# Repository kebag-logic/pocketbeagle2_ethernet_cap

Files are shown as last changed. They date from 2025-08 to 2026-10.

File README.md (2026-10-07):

# PocketBeagle 2 Ethernet Cap

Ethernet cap for the PocketBeagle 2, exposing the TSN features of the AM62x through a
DP83867IRPAPR gigabit PHY (RGMII), with full IO pass-through headers for stacking additional modules.

## Getting started

```sh
git clone <this repo>
git submodule update --init     # pulls kebag_logic_kicad_library
```

Open `pocketbeagle2_ethernet_cap.kicad_pro` with KiCad ≥ 9. All symbols/footprints
resolve project-locally through `sym-lib-table` / `fp-lib-table` into the
[kebag_logic_kicad_library](https://github.com/kebag-logic/kebag_logic_kicad_library)
submodule — no global library setup needed.

## Schematic structure

```
pocketbeagle2_ethernet_cap.kicad_sch   root: pure block diagram (sheet symbols only)
├── io.kicad_sch                       U1 PocketBeagle 2 + J2/J3 IO pass-through headers
├── network.kicad_sch                  network domain top
│   ├── phy.kicad_sch                  U2 DP83867 PHY, straps, decoupling, status LEDs
│   ├── rj45_connector_port0.kicad_sch J1 RJ45 magjack (integrated magnetics)
│   └── oscillator.kicad_sch           Y1 25 MHz HCMOS oscillator + clock conditioning
├── ldo_2v5.kicad_sch                  U4 TPS7A2025 -> VDD_2V5
└── ldo_1v1.kicad_sch                  U3 TPS7A2011 -> VDD_1V1
```

The design is fully hierarchical (shish-lan house style): **no global labels**. `GND`
is distributed via `power:GND` symbols; every other inter-sheet net crosses through
**hierarchical sheet-pin ports**, so signal flow is traceable through the hierarchy.
The root is a block diagram: `io` sources the RGMII/MDIO/reset/interrupt signals and
`VDD_3V3`, `network` consumes them, and the `ldo_*` sheets feed `VDD_2V5`/`VDD_1V1`.
Inside `io`, the PocketBeagle IOs fan out to the stacking headers as sheet-local nets;
only the 17 cap-used signals leave the sheet as ports.

## Documentation

- [documentation/connections.md](documentation/connections.md) — RGMII, MDI, MDIO,
  clocking, straps, audio, power tree, and the rev A → current net rename map
- [documentation/naming_convention.md](documentation/naming_convention.md) — mandatory
  signal naming rules
- [documentation/review_checklist.md](documentation/review_checklist.md) — everything
  awaiting user review after the restructure
- [documentation/library_additions.md](documentation/library_additions.md) — every
  part added to the KL library for this design (review checkpoint)
- [documentation/U2-DP83867IRPAPR_pin_out.md](documentation/U2-DP83867IRPAPR_pin_out.md)
- [documentation/current_consumption.md](documentation/current_consumption.md)

## Board state

**Rev B** (branch `revb-respin`) is manufactured and assembled by JLCPCB. All SMD parts are on the
top side; the RJ45 magjack J1 (TE 5-2301994-7, pin 1 left unsoldered) is hand-soldered on the bottom
and runs through the DP83867 RJ45 mirror mode. RGMII lengths are matched including the PocketBeagle 2
module side. Design and order details: [documentation/handover_revb_respin.md](documentation/handover_revb_respin.md).

Bring-up status (2026-10-07):

| Step | Result |
|---|---|
| Visual inspection, rail-to-GND shorts | OK |
| Bench 3.3 V on P1.14, cape alone: VDD_2V5 / VDD_1V1 | OK |
| PocketBeagle 2 on USB-C, no SD card: rails | OK |
| Ethernet link LED on cable plug/unplug (PHY out of reset, auto-negotiation) | OK |
| Link speed on the switch side: 1000 Mb/s (all 4 pairs and mirror mode work) | OK |
| Linux: PHY detected over MDIO, 1000/Full, iperf3, RGMII delay tuning | to do (needs SD card) |

### Software

A Linux image for the PocketBeagle 2 with this cape is built from the
[ti-sitara-am65x-bsp](https://github.com/kebag-logic/ti-sitara-am65x-bsp). The device tree needs the PHY at `reg = <0>` and
`phy-mode = "rgmii-rxid"` (start with a 1.75 ns RX delay); see section 2.4 of the handover.

### Rev B pictures

Assembled board on the PocketBeagle 2:

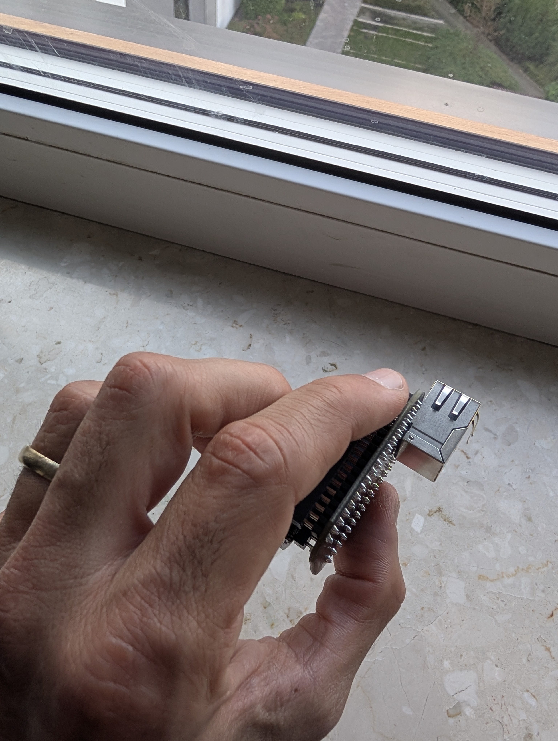
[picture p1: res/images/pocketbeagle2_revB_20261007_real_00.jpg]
Rev B assembled, side

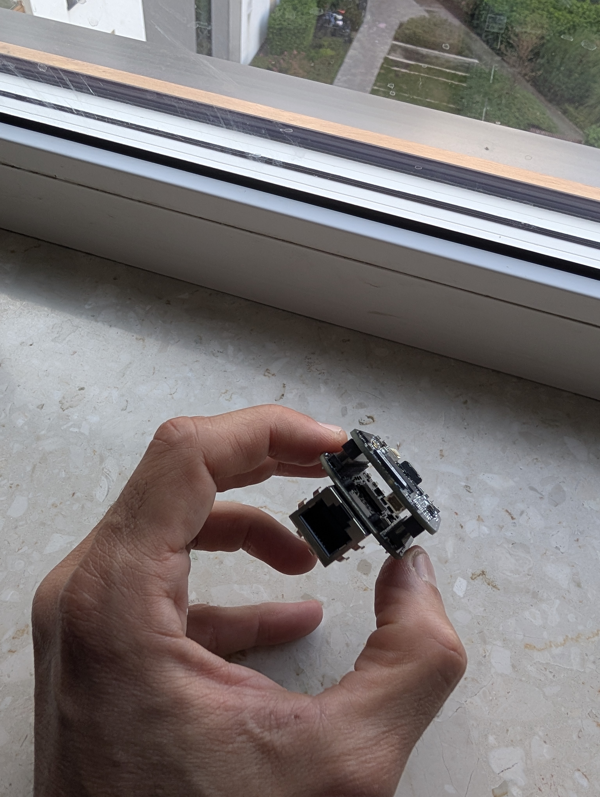
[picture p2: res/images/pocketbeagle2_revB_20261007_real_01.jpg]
Rev B assembled, RJ45 side

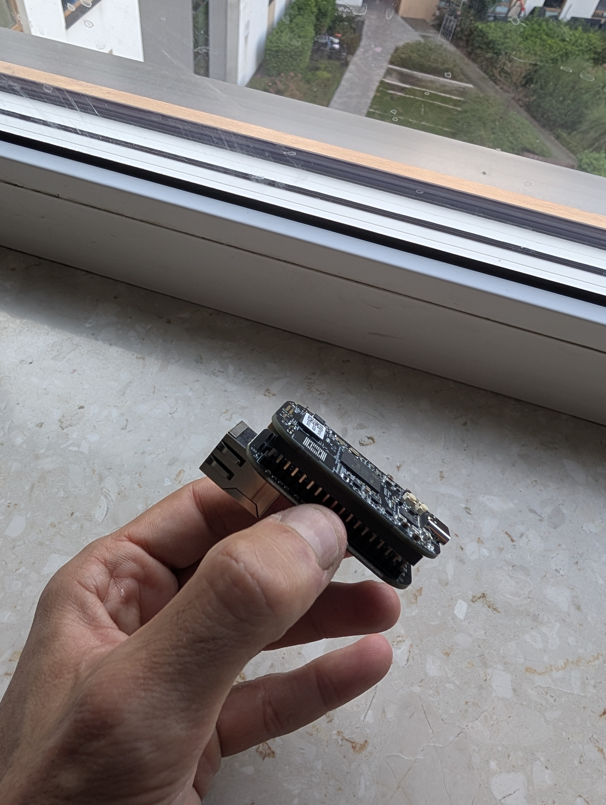
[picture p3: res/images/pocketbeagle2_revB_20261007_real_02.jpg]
Rev B assembled, PocketBeagle 2 on top


Layout and 3D views:

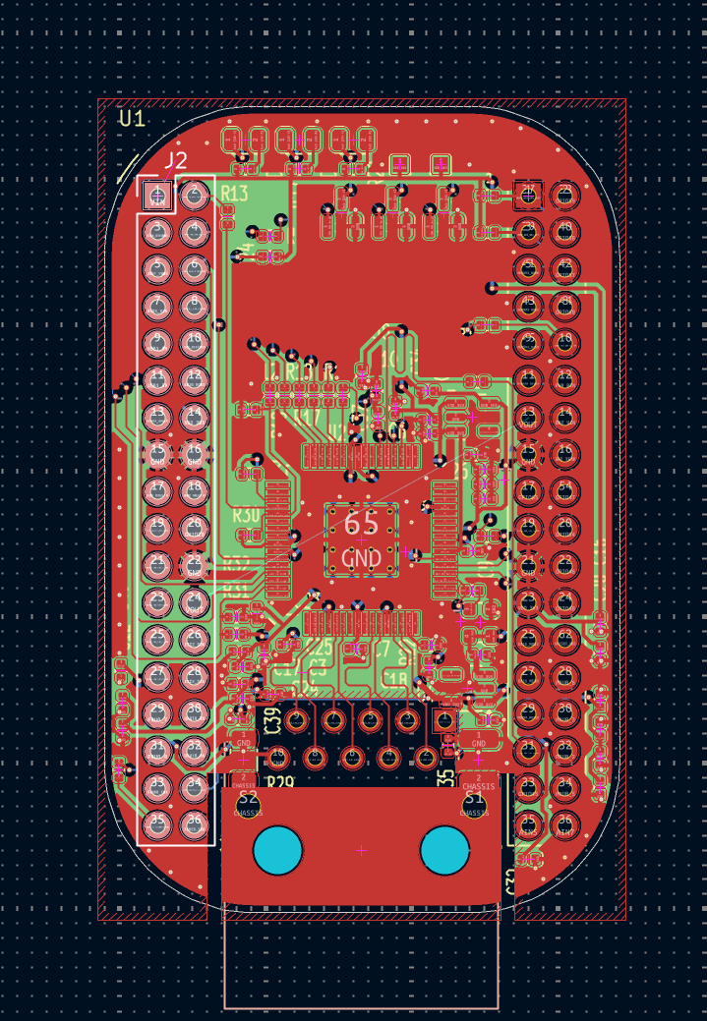
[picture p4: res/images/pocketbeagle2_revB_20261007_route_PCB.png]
Rev B routing

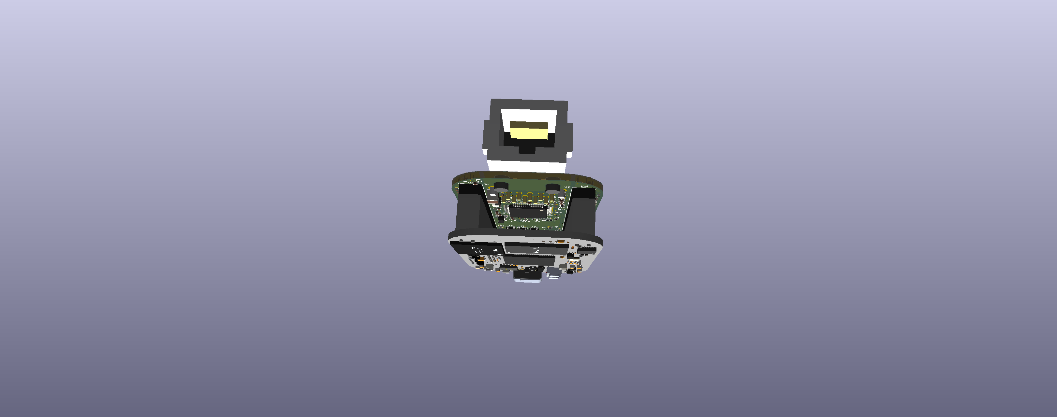
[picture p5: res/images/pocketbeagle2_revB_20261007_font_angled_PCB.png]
Rev B 3D front

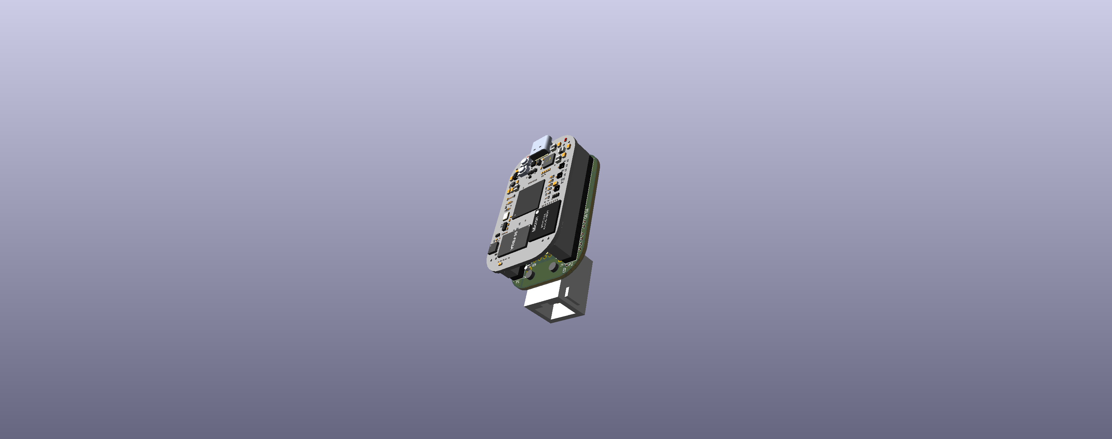
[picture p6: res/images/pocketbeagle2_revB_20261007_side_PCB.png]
Rev B 3D side

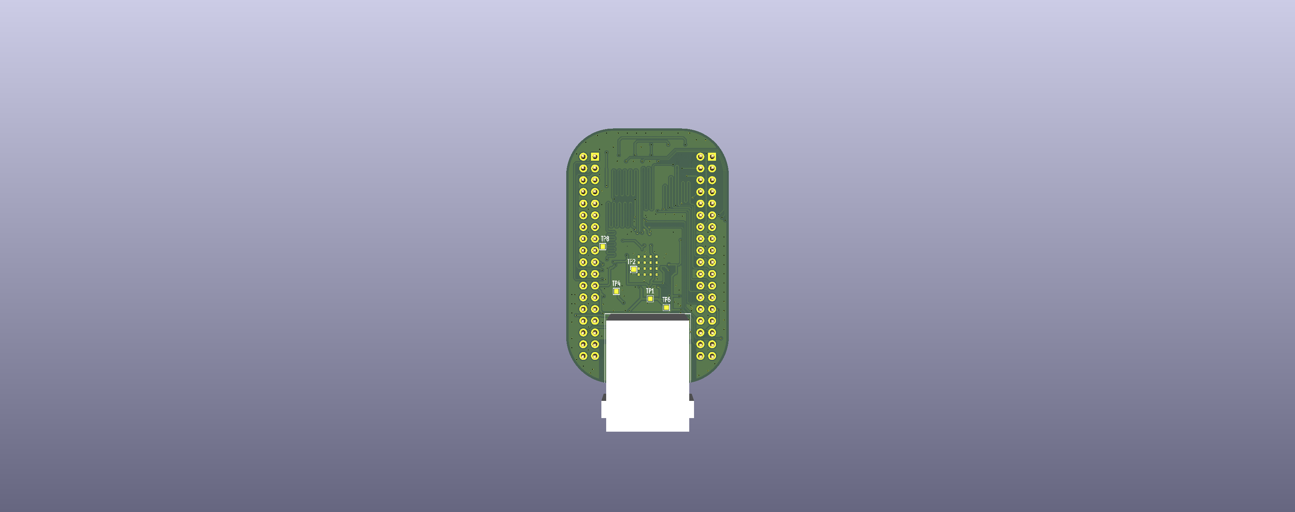
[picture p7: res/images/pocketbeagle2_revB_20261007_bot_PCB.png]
Rev B 3D bottom


### Rev A

The **rev A** routed board is preserved at git tag `revA-routed` (flight-time matching on the RGMII was
still open there).

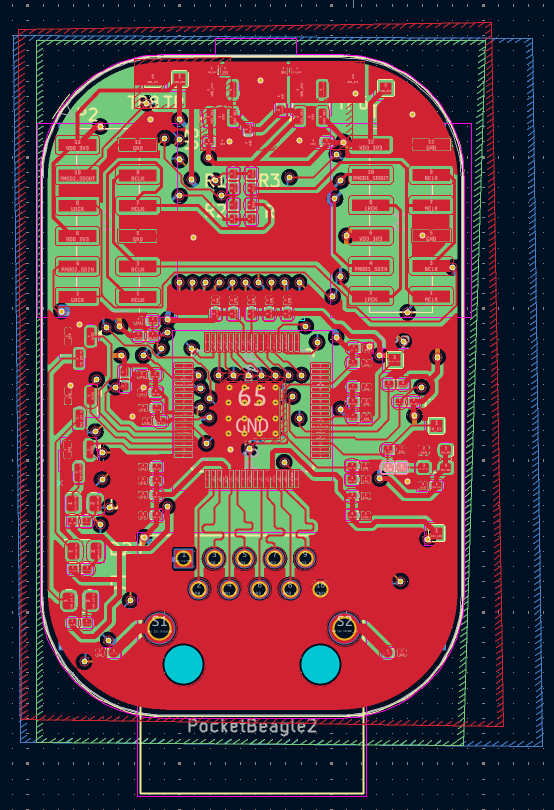
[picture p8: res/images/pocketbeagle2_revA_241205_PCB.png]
PCB layout

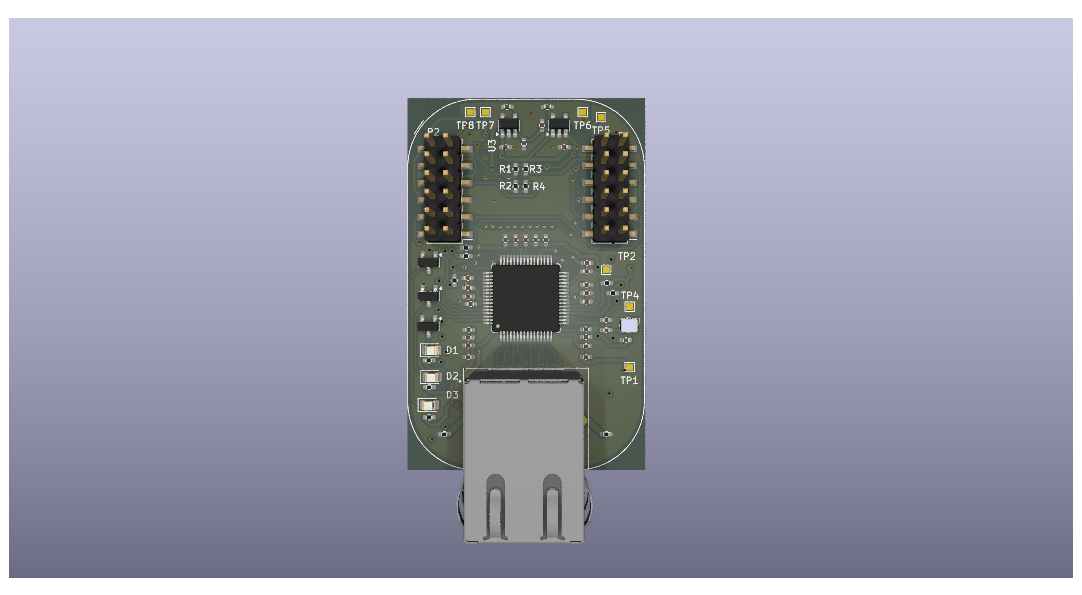
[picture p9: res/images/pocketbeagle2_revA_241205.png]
3D front

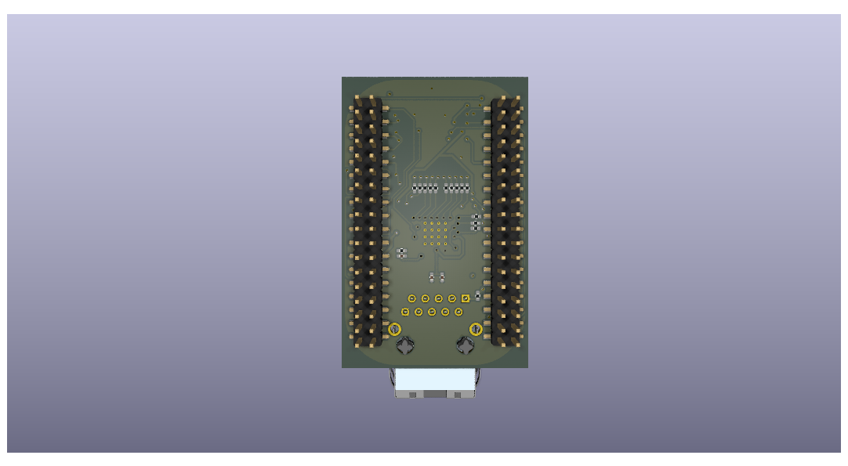
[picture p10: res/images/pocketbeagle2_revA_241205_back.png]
3D back


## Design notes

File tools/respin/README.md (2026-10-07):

# Rev B re-spin helper scripts

These are read-only planning tools plus one kipy script, which clears copper. See `documentation/handover_revb_respin.md`.

Requirements: Python 3 with `shapely` and `kipy==0.8.0`. KiCad 10 must be running with IPC enabled for the kipy scripts.

| Script | What it does |
|---|---|
| `sexp.py` | Minimal s-expression parser. |
| `model.py` | Loads pads and tracks from the saved `.kicad_pcb`. `Plan.seg/via/check` does clearance and edge checks for planned copper with shapely. |
| `plan_mdi.py [bumps…]` | MDI pair routes with the P/N skew bumps. Run with `1.2745 1.2745 1.2745 1.3455` to get 0 issues. |
| `plan_led.py` | LED0–2 gate routes: F stubs, vias, then B.Cu lanes around the top-left arc, necked to 0.10 mm. |
| `plan_rgmii.py` | **Reference only.** The old shortest-path RGMII plan, superseded by the length-matched re-spin. |
| `rgmii_len.py` | Measures the cape-side RGMII lengths per line (PHY pin → R → PB2 pad) and prints the PB2 module lengths. |
| `schio.py <sheet.kicad_sch>` | Read-only schematic geometry helper: pin positions and wire clusters. |
| `ses_parse.py` | Reads Freerouting `.ses` wiring into segment and via lists. |
| `clear_copper.py` | **Destructive.** Removes every track, via and zone from the live board in one KiCad undo step. |

`reference/board_before_respin.kicad_pcb` is the board just before the copper was cleared on 2026-09-25. It has the MDI, power, slow-net and LED routing.

## `topside/`: all SMD parts moved to F.Cu (2026-09-25)

These are archived as run. They also import the working-copy planners (`rg.py`, `d_*.py`, `meander.py`, `audit_angles.py`), which are not archived, so treat them as a record, not a ready-to-run tool.

| Script | What it does |
|---|---|
| `fpgeo.py` | Library footprint pads and courtyards for what-if placements. |
| `prune.py` | Finds the copper that dangles once a set of footprints leaves; used to clear their old bottom-side routing. |
| `ts.py` | The stage placement table (x, y, rot, side) plus courtyard and pad-clearance checks. |
| `r_top.py` | Stage 1. LED drivers Q1–Q3, D-K lanes, rebuilt LED gate lanes, MDIO/INT pull-ups, and the TD0/TD2 series resistors with their re-matched accordions. |
| `r_bot.py` | Stage 2. TD3 (R11) re-matched, TX_CLK (R14), R7 strap, CLK_OUT/1V1 test points moved to B.Cu. |
| `router.py` | 2-layer grid router. It uses 8 directions with turns of 45° or less, places vias, and stays clear of other-net copper and keepouts. |
| `capfit.py` | Greedy placement of U4 and the 30 caps nearest their pins. Each part is routed rail to copper and GND to a plane via. Results go to `cap_place.json` and `cap_routes.json`. |
| `conn.py` | Per-net island check: pads, tracks and vias, with GND vias joining the planes. |
| `apply_stage.py` | Checks live pads against the model, removes the pruned copper (exact endpoints), then pushes the plan. |
| `silk_place.py` | Places reference designators and P1/P2 labels at 1.0/0.15 mm with no overlaps. |

`../make_build.py` writes `build/`: fabrication (Gerbers, drill, zip, IPC-D-356), assembly (JLC BOM/CPL, full BOM, drawing) and docs (schematic PDF, STEP, DRC report).

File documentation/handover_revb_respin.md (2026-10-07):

# Handover — Rev B schematic review and PCB re-spin

Date: 2026-09-25. Project: PocketBeagle 2 Ethernet cape (DP83867, KiCad 10.0.6).

**State (end of 2026-09-25):** the re-spin is **routed, DRC-clean on copper and committed** on branch
`revb-respin`, with **every SMD part on the top side**. JLCPCB Gerbers, BOM and CPL are in `build/`.
Sections 2.1–2.2 are the schematic/library history; 2.3 onward is the current board.

---

## 1. What was asked

- Review the schematics, then re-spin the PCB.
- Match the RGMII lanes as they must be, **including the PocketBeagle 2 (PB2) module-side
  lengths**, with the right impedance. EMC must be good.
- Add F.Silkscreen labels for the P1/P2 headers.
- Add missing 3D models to the `kebag_logic_kicad_library` submodule and commit them.
  Commit as `hackerman-kl <alexandremalki89@gmail.com>`, at most 10 words, no co-author.
- Pour the signal-layer (F/B) GND planes **last**, after everything else is routed.
- Avoid 90° corners. Follow every IC's layout guidelines.

PB2 module-side RGMII2 lengths given by the user (mils → mm):

| Signal  | Ball | mils | mm |
|---|---|---|---|
| RD0 | AE23 | 1808.5  | 45.94 |
| RD1 | AB20 | 1520.17 | 38.61 |
| RD2 | AC21 | 1511.44 | 38.39 |
| RD3 | AE22 | 1459.68 | 37.08 |
| RX_CLK  | AD23 | 2204.81 | 56.00 |
| RX_CTRL | AD22 | 1350.87 | 34.31 |
| TD0 | Y18  | 1182.32 | 30.03 |
| TD1 | AA18 | 1991.72 | 50.59 |
| TD2 | AD21 | 785.48  | 19.95 |
| TD3 | AC20 | 328.86  | 8.35  |
| TX_CLK  | AE21 | 2442.23 | 62.03 |
| TX_CTRL | AA19 | 2925.95 | 74.32 |

TD2 and TD3 each have "2 possibilities" (two SoC balls). The table uses the listed ball.

---

## 2. Done

### 2.1 Schematic fixes (ERC: 0 errors; committed)

| Fix | Where | Why |
|-----|---|-----|
| J2.2/4/19/21/23/25/27/34/35 and J3.10/19 were tied to GND. They now carry their U1 RGMII net. | `io.kicad_sch` | J2/J3 are co-located on the U1 holes, so they are the same plated hole. As drawn, the GND tie shorted RGMII to GND. It came from commit `c8bef36`. |
| AIN_VREF_N label moved from U1.51 to U1.17. U1.51 is GND again. | `io.kicad_sch` | The label was on the wrong pin. |
| Removed a dangling 2.54 mm wire under `#PWR0100`. | `io.kicad_sch` | ERC warning. |
| **R30 5k76 added**, STRAP_RX_CTRL_PHY to VDD_3V3. With R7 2k49 this gives **mode 3**. | `phy.kicad_sch` | RX_CTRL in mode 1 is forbidden (SNLS484J Table 7-6 note 1): the PHY can enter a test mode. |
| RX_D7 strap changed to **mode 4**: R5 5k76 → 2k49, R6 removed. | `phy.kicad_sch` | Speed-opt stays on and CLK_OUT is disabled, so the unused 25 MHz to TP2 no longer radiates. Table 7-5/7-6. |
| C28 (22p on RBIAS) removed. | `phy.kicad_sch` | Not in the datasheet or TI reference designs. Konnect can't set DNP, so the part was deleted. |
| C18 27p → **22p**. | `oscillator.kicad_sch` | XI amplitude goes from 1.51 Vpp (marginal) to about 1.65 Vpp, against the 1.5–1.9 Vpp spec. |
| **R25 removed**, J1.1 (centre-tap common) marked no-connect, and the `VDD_2V5` sheet pin on the magjack sheet deleted. | `rj45_connector_port0.kicad_sch`, `network.kicad_sch` | Fitting R25 would put 2.5 V DC on the magjack centre taps. Fig 9-2: CTs go to GND through caps only. |
| **Chassis isolation.** J1.S1/S2 go to a `CHASSIS` net, then R29 **1M 1206** ∥ C36 **4n7 2 kV 1210** to GND. This replaces the two 0R links. | `rj45_connector_port0.kicad_sch` | TI §9.2.2 chassis isolation, for ESD and EMC. |

Review findings that are **not** schematic changes. They go to firmware and device tree (DT):

- **Shared pins:** PB2 RGMII/MDIO header pins are shared with other SoC balls (E18, D20, A13, B20, B18) and with MSPM0 PA16/PA21–26. The PB2 pinmux must keep the second balls as inputs with no pull, and the MSPM0 must keep those pins Hi-Z/analog. Check the RX eye at 1000 Mb/s.
- **PHY address:** it depends on RX_D0/RX_D2 floating at strap latch time. Put `reg = <0>` in the DT.
- **RGMII delays:** AM62x normally uses `phy-mode = "rgmii-rxid"`, and the DT needs `ti,rx-internal-delay`. Set the final values after routing, from the measured lengths (section 4.4).
- **Voltage:** RGMII2 on the PB2 is 3.3 V (VDDSHV2), so VDDIO = 3.3 V is correct. The "1.8V" pin labels were wrong; see 2.2.

### 2.2 Library submodule (`kebag_logic_kicad_library`, branch `pocketbeagle-2`)

There are 3 local commits. They are **not pushed**, and the main repo's submodule pointer has not been bumped.

- `3800219` Add 3D models for PHY, oscillator and PocketBeagle 2:
  - HTQFP-64: KiCad model `TQFP-64-1EP_10x10mm_P0.5mm_EP5.305x5.305mm.step`.
  - ECS-2520MV: KiCad `SG210` 2.5×2.0 model as a **stand-in** (see `3dmodels/Oscillator.3dshapes/README.md`).
  - PocketBeagle 2: `3dmodels/Module.3dshapes/PocketBeagle2.stpZ`. The source is the openbeagle.org pocketbeagle-2 repo (EVT STEP), licensed CC BY-SA 4.0. Attribution is in `README.md`.
- `d30326e` Add 1M 1206 resistor and 4n7 2kV 1210 capacitor:
  - `R_1M_0.25W_1pct_1206`: CRCW12061M00FKEA, LCSC C844869.
  - `C_4n7_2kV_10pct_X7R_1210`: KEMET C1210C472KGRACTU. **The Mouser, Digikey and LCSC fields are blank because they weren't verified.**
  - New footprints `R_1206` and `C_1210`, with KiCad 3D models.
- `561d560` Match PocketBeagle2 symbol GND pins, AIN0-4 are 3.3V:
  - The library symbol now matches the schematic layout.
  - GND pin 15 is `power_out`; the other GND pins are `passive`.

Later schematic changes (user-approved, committed):

- 1 µF added on PHY pins 4, 12, 41, 42 (C37–C40), per TI.
- **DP83867 RJ45 mirror mode** (§7.4.6.6), so J1 can sit on B.Cu:
  - J1 MDI pins are remapped: A↔D and B↔C, with polarity swapped.
  - A LED_0 mode-3 strap enables it: R31 5k76 to 3V3, R32 2k49 to GND. LED0 stays active-high.
- BOM swapped to in-stock LCSC parts. U3 is now **TLV73311PDBVR** (C2865431), same DBV pinout.

3D models (submodule `kebag_logic_kicad_library`): `PocketBeagle2.stpz` (lower-case extension, which KiCad 10 needs)
sits 11 mm above the cape top: 2.5 mm male-header plastic plus the 8.5 mm PB2 female header, which is on the PB2's
bottom face, so the PB2 is component-side up. The J1 Bel STEP is **not** committed; see section 5.

### 2.3 PCB (current)

**Stackup:** F / 0.1 mm prepreg / **In1 GND** / 1.24 mm core / **In2 GND** / 0.1 mm prepreg / B, close to JLC04161H-3313.

**Placement:**
- **All SMD parts are on F.Cu.**
- B.Cu holds only J1 (THT Bel 1840888-1, rotated 180° after the flip) and the unassembled test pads TP1/2/4/6/8.
- The PB2 (U1) plugs onto J2/J3 (2×18 male headers on U1's holes).
- LED drivers Q1–Q3 are under the 3V3 top bus.
- The TX series resistors R8/R10/R11/R14 sit next to their header pins.
- U4 (2V5 LDO) is at the bottom right.

**Routing:** everything uses 45° corners, audited by script.
- **RGMII:** 0.15 mm (≈50 Ω, estimate). Lengths are matched including the PB2 module side (module + cape, physical length, vias counted as 1.6 mm):

  | Group | Lines | Total (mm) |
  |-------|-------|------------|
  | RX | RD0–3 | 84.76 |
  | RX | RX_CLK | 98.86 (+14.1) |
  | TX | TX_CTRL, TD0–3 | 99.671 |
  | TX | TX_CLK | 115.07 (+15.4) |

  - The clock offsets (≈ +95 ps RX, ≈ +103 ps TX) come from the routes and are absorbed by the delay settings. Use AM62x `phy-mode = "rgmii-rxid"` or `rgmii-id`, and tune with DP83867 RGMIIDCTL (0.25 ns steps) or `ti,rx/tx-internal-delay`.
  - Measure with `tools/respin/rgmii_len.py`. It sums stubs as well, so strapped nets such as RX_CTRL read long.
- **MDI:** 0.13 mm width, 0.2 mm gap, on F.Cu with no vias, P/N skew-matched.
- **Chassis:** a CHASSIS island under J1 on F and B, with a 1 mm moat to GND. R29 (1M) and C36 (4n7 2 kV) bridge it.
- **Stitching:** GND stitching fence plus interior grid. F/B GND pours are refilled.
- **Decoupling:** placed and routed by `tools/respin/topside/capfit.py`, nearest free top-side spot to each pin.
  - C7 sits on pin 8 in the MDI gap, and C9 on pin 23.
  - Because of the single-sided constraint (user decision: "Everything on top anyway"), several caps are several mm from their pins. They connect over short B.Cu rail links.
  - The 2V5/3V3 bulk caps C11/C8/C19/C15/C16/C20 sit on the right edge strip beyond J3. C22 sits on the left strip.

**DRC (kicad-cli, `--refill-zones`):** 0 clearance, short, width, courtyard or silk-overlap errors. What remains:
- `annular_width` and `starved_thermal`: Board Setup values the user has to change (section 5).
- `holes_co_located`: J2/J3 on U1, by design.
- 4 `lib_footprint_mismatch`.
- U4 silk clipped by the J1.1 NC pad.
- J1 B.Silk past the edge: J1 overhangs the edge by design.
- VOUT U1.24 ↔ U1.49 unconnected: the PB2 joins them internally.
- Schematic parity field mismatches.

**Silkscreen:**
- 1.0 mm text, 0.15 mm stroke, with no overlaps.
- P1/P2 labels and pin numbers are kept.
- 19 crowded references are hidden on silk; they're still on F.Fab.

**Production:** `build/` holds the Gerber and drill zip, `*_bom_jlcpcb.csv` (LCSC #) and `*_cpl_jlcpcb.csv`. See `build/README.md`. Regenerate with `python tools/make_build.py`.

---

## 2.4 JLCPCB order (2026-09-25)

- The order was submitted to JLCPCB from `build/` at commit `bfe32f5`: Gerber zip, JLC BOM, JLC CPL.
- It's a top-side assembly with JLC-chosen rotations: U2 0°, Q1–Q3 270°, U3 180°, U4 0°, Y1 90°, J2/J3 90°, LEDs 0°.
- **Not assembled:**
  - J1: hand-solder it and **leave pin 1 (NC) unsoldered**. It sits 0.17–0.23 mm from U4, C5, C32 and C33.
    - **Part: TE 5-2301994-7** (tray; DigiKey stock 2,653 on 2026-09-27). The Bel 1840888-1 through -5 have no stock anywhere.
    - The TE drawing matches the Bel in every way that matters here:
      - holes Ø0.90 on a 1.27/2.54 stagger, rows 8.89/6.35, pegs Ø3.25 at 11.43;
      - pin 1 = centre-tap common, with 4 × 0.1 µF to pin 10 (GND);
      - pairs 2/3→RJ1/2, 4/5→RJ3/6, 6/7→RJ4/5, 8/9→RJ7/8;
      - the 1000 pF Bob-Smith capacitor goes to the shield.
    - The shield tabs are 15.71 mm apart against 15.49 on the board, 0.11 mm off per side in the 1.65 mm holes. If the tabs don't go in, squeeze them in slightly.
    - Other drop-ins, same wiring: Halo HFJ11-(E)1G16E-L12RL, Molex 0936268520 / 0936263508, Pulse (J)XKM-0013NL. For their LED pins (which land 0.2 mm inside the board edge), clip flush before fitting.
    - **Don't use** HanRun HR911130A-style jacks (and their clones). The holes match but the middle pairs are crossed (4/7, 5/6). The same goes for TE 2301994-6, 1-2301994-0 and 3-2301994-1, and Molex 0936263006 / 0936268020.
  - U1: the PocketBeagle 2, plugged on.
  - TP1–TP8: test pads only.
- **Late fixes before the order:**
  - R29 and C36 chassis pads moved off the J1 shield-pin holes.
  - C33 placed under U4.
  - J1.10 ground reconnected.
  - CPL rotations and centroid corrections.
- **Bring-up:**
  - Set the RGMII delays: RX clock is +14.1 mm (+95 ps) and TX clock +15.4 mm (+103 ps) versus data. Start with `rgmii-rxid` / `rgmii-id` and a DP83867 RX delay of 1.75 ns.
  - RJ45 mirror mode is strap-enabled (LED_0 mode 3).
  - PHY address `reg = <0>`.

## 3. Decisions and approvals from the user (keep them)

1. **Stackup:** In1 and In2 are both GND. Power runs on outer-layer traces.
2. **Tools:**
   - Konnect MCP is used for part moves, flips, saves, refills and footprint updates.
   - kicad-python (kipy 0.8.0, `ipc:///tmp/kicad/api.sock`) is approved for:
     - bulk clear or add of planned tracks and vias in undoable batches;
     - zone outline and spoke edits;
     - silkscreen text placement;
     - one-off 3D model entries.
   - Never hand-edit `.kicad_pcb`, `.kicad_sch` or `.kicad_pro`.
3. **Commits:**
   - One line, at most 10 words.
   - Author and committer `hackerman-kl <alexandremalki89@gmail.com>`, with **no co-author trailer**.
   - Branch `revb-respin`.
   - Never commit the untracked `.gitprep-hackerman-kl`, `Requirements`, `konnect/` or the PDF.
4. **Layout:**
   - F/B GND pours go on last.
   - 45° corners only.
   - Every SMD part on the top side, **"Everything on top anyway"**: decoupling can sit farther from the pins.
   - J1 is the only part on the bottom.
5. **Schematic changes need explicit approval.**

---

## 4. Open items

- **J1 sourcing:** the Bel 1840888-x has no stock anywhere, so hand-solder the **TE 5-2301994-7** instead (drop-in; see 2.4). J1 stays out of the JLC BOM/CPL. The schematic MPN still says Bel.
- **Low stock:** U2 C477933 has 18 pcs; order early.
- **Firmware / DT:**
  - Set the PHY address with `reg = <0>`.
  - RGMII delays per 2.3.
  - Mirror mode is strap-enabled; nothing to do in software.
  - PB2 shared pins: keep the second SoC balls and the MSPM0 pins Hi-Z.

---

## 5. Actions only the user can do

1. ~~Close and reopen the project in KiCad.~~ **Done.** `KL_LIB` is now a project text variable (`${KIPRJMOD}/kebag_logic_kicad_library`, `09816f6`). Its in-memory project settings are stale (pre-rev-B netclasses) and rewrite `pocketbeagle2_ethernet_cap.kicad_pro` on save. Every script run so far restores the file with `git checkout -- pocketbeagle2_ethernet_cap.kicad_pro`.
2. **3D path:** Preferences → Configure Paths → add `KL_LIB` = `<project>/kebag_logic_kicad_library`. Without it, KiCad shows only pads.
3. ~~Board Setup: via annular 0.1 mm, thermal spokes 1~~. **Done** (`6a96a4f`). DRC now has **0 errors**. Only warnings remain: J2/J3 on U1 holes, 4 library mismatches, the U4 silk clipped at J1.1, and J1's overhang.
4. **Impedance:** order JLC impedance control and let them adjust the widths. On their 3313 stackup, 50 Ω may need about 0.17–0.19 mm.
5. **J1 model:** download the Bel 1840888-1 STEP from belfuse.com (CC BY-ND, commit it unchanged).
6. **Library:** push the `kebag_logic_kicad_library` commits and bump the submodule pointer.
7. **JLC order:** check part rotations in the placement preview (SOT-23, SOT-23-5, HTQFP, LEDs).

---

## 6. Tooling and gotchas

- Scripts live in `tools/respin/` (see its README), including `topside/`: the router, the cap fitter and the stage plans.
- `kicad-cli pcb render` / `export` need `-D KL_LIB=<repo>/kebag_logic_kicad_library`.
- KiCad re-nets a dangling via or stub when a footprint it touched is flipped. Check for orphan vias and duplicate tracks after pushes.
- **Konnect cannot:** delete vias or zones, set DNP, or import SES on 4-layer or rounded boards.
- `kicad-cli` ERC JSON coordinates are scaled by 100.

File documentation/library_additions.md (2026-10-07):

# Library additions — review checkpoint (M2)

Everything added to `kebag_logic_kicad_library` for the ethernet cap migration, with
sources, license basis and open questions. **Please review before the submodule is
pushed upstream.**

**Sourcing pass (2026-07-27):** every MPN below was checked against a live Digi-Key
product page and against LCSC, and the `Digikey` / `LCSC` fields were filled from those
listings — see [Supplier reference pass](#supplier-reference-pass-2026-07-27) for the
full table and for the three part numbers that turned out not to exist. MPNs previously
marked *(derived)* are now marked **verified** where a distributor listing confirmed
them.

## Footprints (`KL_Footprints.pretty`)

| Footprint | Used by | Source | License basis | Notes |
|---|---|---|---|---|
| `SOT-23` | Q1-Q3 BSS138 | KiCad official lib, verbatim + KL 3D path | CC-BY-SA-4.0 w/ exception (house precedent: `C_0402`, `TQFP-128`) | 3D model included |
| `SOT-23-5` | U3/U4 LDOs | KiCad official lib | same | 3D model included. **PCB rev A uses SOT-23-5**, not the DSBGA of the old vendor import |
| `LED_0805` | D1-D3 | KiCad official `LED_0805_2012Metric` | same | 3D model included |
| `06x02_2.54mm_SMD_Header` | P1/P2 PMOD | KiCad official `PinHeader_2x06_P2.54mm_Vertical_SMD` | same | name follows `10x02_2.54mm_Header` house pattern; 3D model included |
| `TestPoint_SMD_1.0x1.0mm` | TP1-TP8 | KiCad official | same | existing KL `TestPoint` is through-hole — not interchangeable |
| `ECS-2520MV` | Y1 | KiCad official `Oscillator_SMD_ECS_2520MV-xxx-xx-4Pin_2.5x2.0mm` (the exact footprint on the routed rev A board) | same | no 3D model in KiCad lib; ECS provides a STEP on ecsxtal.com (SnapEDA copy not redistributable) |
| `BeagleBoard_PocketBeagle` | U1 | KiCad official Module lib | same | no 3D model available upstream |
| `HTQFP-64_10x10mm_P0.5mm` | U2 DP83867 | **redrawn**: pad geometry (incl. thermal-via array) identical to rev A board (TI PAP0064 land pattern); all graphics regenerated per FOOTPRINTS.md | land-pattern dimensions are datasheet facts; no SnapEDA file content copied (their license §1a forbids library redistribution) | via-in-pad array kept exactly as routed |
| `BEL_1840888-1` | J1 RJ45 | **redrawn**: pad geometry identical to rev A board; graphics regenerated | same reasoning | TH pin 1 is rectangular = pin-1 marking per FOOTPRINTS.md |

## Symbols

| Symbol (lib) | MPN | Status | Datasheet |
|---|---|---|---|
| `KL_R`: `R_0R_0.063W_5pct_0402` | CRCW04020000Z0EDC | **verified** (Digi-Key + LCSC) | vishay.com 28773/crcwce3.pdf |
| `KL_R`: `R_22R/200R/2K2/2K49/5K76/11K_0.063W_1pct_0402` | CRCW0402…FKEDC | **verified** — all six exist at Digi-Key and LCSC | same |
| `KL_C`: `C_10n_50V_10pct_X7R_0402` | GRM155R71H103KA88D | **verified** | murata.com productdetail |
| `KL_C`: `C_1u_16V_10pct_X5R_0402` | GRM155R61C105KA12D | **verified** — 0 stock / 17-week lead at Digi-Key, 150 k at LCSC | same |
| `KL_C`: `C_10u_6.3V_20pct_X5R_0402` | GRM155R60J106ME44D | **verified but DISCONTINUED at Digi-Key** (LCSC still stocks 1.1 M) — **6.3 V rating on a 3V3 rail: check derating policy** | same |
| `KL_C`: `C_22p/27p_50V_5pct_C0G_0402` | GRM1555C1H220/270JA01D | **verified** | same |
| `KL_LED`: `LED_Green_2.1V_0.02A_0805` | LTST-C170GKT | **verified** (Lite-On, same family as house 0603s); LCSC field was wrong — see below | liteon.com |
| `KL_LED`: `LED_Orange_2V_0.02A_0805` | LTST-C170KFKT | **verified**; LCSC field was wrong | liteon.com |
| `KL_LED`: `LED_Red_2V_0.02A_0805` | LTST-C170KRKT | **verified**; LCSC field was wrong | liteon.com |
| `KL_TestPoint`: `TestPoint_SMD` | — | clone of house TestPoint, SMD footprint | — |
| `KL_Voltage_Regulators`: `TPS7A2025PDBVR` | TPS7A2025PDBVR | **verified orderable** (2.5 V rail) | ti.com/lit/gpn/tps7a20 |
| `KL_Voltage_Regulators`: `TPS7A2011PDBVR` | TPS7A2011PDBVR | **DOES NOT EXIST — see Q1** (1.1 V rail) | same |
| `KL_Conn_Data`: `RJ45_1840888-1` | 1840888-1 | **verified — manufacturer is Bel Fuse Inc.** (Q2 closed) | LCSC mirror, see Q2 |
| `KL_Conn_Data`: `PMOD_02x06` | TBD (generic 2x6 SMD header) | physical part = any 2x6 SMD header; Digilent PMOD spec linked | digilent.com |
| `KL_Transistor` (new lib): `BSS138LT1G` | BSS138LT1G | **verified** (onsemi, Digi-Key + LCSC C82045) — rev A says only "BSS138"; onsemi variant chosen — see Q3 | onsemi.com |
| `KL_Oscillator` (new lib): `Oscillator_25M_25ppm_HCMOS_2.5x2.0` | ECS-2520MV-250-CN-TR | **verified** (LCSC C405464); matches `footporint_manual/ECS_2520MV_250_CN_TR/` | ecsxtal.com/store/pdf/ECS-2520MV.pdf |
| `KL_PHY` (new lib): `DP83867IRPAPR` | DP83867IRPAPR | **verified** | ti.com/lit/gpn/dp83867ir |
| `KL_Module` (new lib): `PocketBeagle2` | PocketBeagle 2 | board, not a component | docs.beagleboard.org/boards/pocketbeagle-2/ |

All IC/connector/module symbols replicate the **pin positions of the rev A schematic
symbols exactly**, so the migration drops them onto the existing wires without rewiring.
Only numeric pin data was carried over; symbol bodies, properties and fields are fresh
(KL conventions). Electrical pin types were corrected where the vendor import was wrong
(e.g. LDO `GND` was `power_out`, `NC` now `no_connect`).

## New convention documents

- `TRANSISTOR.md`, `OSCILLATOR.md`, `PHY.md`, `MODULE.md` — modeled on `VOLTAGE_REGULATOR.md`.
- `README.md` — four new libraries registered. *(Note: the pre-existing README table
  names several libraries that don't match the actual files, e.g. `KL_Ferrites` vs
  `KL_Ferrite_Bead` — left untouched, upstream issue.)*

## Open questions

1. **1.1 V LDO — BLOCKING, part does not exist.** rev A used symbol
   `TPS7A20C285PYCKR` (a DSBGA part) for *both* LDOs while the board has SOT-23-5 pads.
   TPS7A20**25**PDBVR (2.5 V) is confirmed orderable. **TPS7A20**11**PDBVR is not a real
   part number**: TI's own `part-details` page 404s for it (it resolves for e.g.
   `TPS7A2018PDBVR`), Digi-Key returns no results, and LCSC has no listing. Digi-Key's
   TPS7A20 SOT-23-5 range skips 1.1 V entirely (…09, 12, 15, 18, 185, 24, 28, 30, 31,
   32, 36, 42, 45, 50, 55). Its supplier fields were therefore left `TBD` — filling
   them would mean inventing an order number for a part nobody sells.
   Options: **(a)** `TLV73311PDBVR` — real TI 1.1 V / 300 mA LDO in the same SOT-23-5
   (DBV) package, LCSC `C2865431`; its pinout differs from TPS7A20 (no separate NR/SS
   pin) so it needs a pin-by-pin check before committing. **(b)** drop U3 and use the
   DP83867's internal core LDO, freeing one regulator. Neither `TPS7A2009PDBVR` (0.9 V)
   nor `TPS7A2012PDBVR` (1.2 V) is within the DP83867 VDD1P1 ±5 % window.
2. ~~**RJ45 1840888-1**~~ — **RESOLVED. The manufacturer is Bel Fuse Inc.**, so the
   SnapEDA `BEL_…` label was right and the TE-looking number format was a red herring.
   Digi-Key `5923-1840888-1-ND` (the same `5923-` Bel Fuse prefix as the house part
   `0826-1X4T-43-F`), LCSC `C5876366`. It is a shielded 10/100/1000 Base-T AutoMDIX
   MagJack with integrated magnetics, gold-plated phosphor bronze contacts, no LEDs.
   The `Datasheet` field now points at LCSC's mirror of the manufacturer PDF:
   `https://wmsc.lcsc.com/wmsc/upload/file/pdf/v2/lcsc/2312031643_TRP-Connector-1840888-1_C5876366.pdf`
   — **replace this with a belfuse.com URL if you have one**; Bel's own site does not
   expose a per-part page for this number. Note availability is poor: 26-week lead at
   Digi-Key, 0 stock at LCSC.
3. **BSS138 vendor**: plain "BSS138" is multi-sourced. I picked onsemi `BSS138LT1G`.
   OK, or do you have a preferred source (Nexperia BSS138P …)?
4. **Capacitor specs**: rev A schematic has bare values (no voltage/dielectric).
   Derived choices above (X7R/C0G/X5R, 50/16/6.3 V) — all five part numbers are now
   confirmed real, but the *choice* of rating is still mine, not rev A's. If a rev A
   BOM exists, I'll match it. Two availability notes: the 10 µF `GRM155R60J106ME44D`
   is **discontinued at Digi-Key** (LCSC still stocks it heavily; Digi-Key suggests
   `GRM155R60J106ME15D`), and the 1 µF `GRM155R61C105KA12D` is on a 17-week Digi-Key
   lead.
5. **DNP resistor R25**: value literally "DNP" in rev A. It will be migrated as the
   footprint-compatible resistor of its strap group with the KiCad DNP attribute set —
   which value should it document (11K like R22?)
6. ~~**Supplier numbers**~~ — **DONE for Digi-Key and LCSC**, see the section below.
   **Mouser could not be automated**: mouser.com serves an "Access to this page has
   been denied" bot wall to every request, and Mouser part numbers are not derivable
   from the MPN (the house entries show Mouser mangles them — MPN `GRM187R61A226ME15D`
   is Mouser `81-GRM187R61A226ME5D`, a character short). Four Mouser fields are still
   `TBD`; the confirmed Mouser product pages are listed below so you can copy the
   numbers in one click.

## Expansion header addition

| Symbol (lib) | MPN | Source | Notes |
|---|---|---|---|
| `KL_Header`: `Header_18x02_2.54mm_2.54mm_Straight` | BHR-36-VUA *(derived from house BHR-20-VUA)* | Adam Tech BHR series | footprint `18x02_2.54mm_Header` ported from KiCad official 2x18 vertical + 3D model |

**Sourcing check (left as-is on request, recorded for the record):** `BHR-36-VUA` is not
orderable anywhere — not Digi-Key, not LCSC. The Adam Tech BHR series only comes in the
standard IDC position counts (…20, 34, 40; BHR-20/34/40-VUA all resolve, 36 does not).
Its datasheet also titles it *"BOX HEADER, VERTICAL PCB MOUT, 2 ROW .100 PITCH"* — a
shrouded/keyed connector, which is not what the plain `18x02_2.54mm_Header` footprint
lays down. (The same mismatch already exists upstream on the house `BHR-20-VUA` /
`10x02_2.54mm_Header` pair, so this is inherited, not introduced here.) A real
equivalent, if wanted later: **Adam Tech `PH2-36-UA`** — 36 positions, 2 rows, 2.54 mm,
through-hole, unshrouded, Digi-Key `2057-PH2-36-UA-ND` (same `2057-` Adam Tech prefix as
the house BHR-20-VUA entry); not carried by LCSC. `Digikey`/`LCSC` on this symbol were
left `TBD`.

## Supplier reference pass (2026-07-27)

Method: each MPN was resolved against its live Digi-Key product page (for the Digi-Key
part number, and to confirm the MPN exists at all) and against LCSC via the JLCPCB parts
API, accepting only exact MPN matches. Nothing here is derived from a naming scheme.

| MPN | Digi-Key | LCSC | Refs |
|---|---|---|---|
| CRCW04020000Z0EDC | 541-4062-1-ND | C844710 | R25, R26, R29 |
| CRCW040222R0FKEDC | 541-3973-1-ND | C2076943 | R8–R19 |
| CRCW0402200RFKEDC | 541-3995-1-ND | C843896 | R23, R27, R28 |
| CRCW04022K20FKEDC | 541-3971-1-ND | C2076947 | R20, R21, R24 |
| CRCW04022K49FKEDC | 541-4867-1-ND | C1730862 | R6, R7 |
| CRCW04025K76FKEDC | 541-5031-1-ND | C4180495 | R5 |
| CRCW040211K0FKEDC | 541-4691-1-ND | C1730800 | R22 |
| GRM155R71H103KA88D | 490-4516-1-ND | C77019 | C19, C24, C27 |
| GRM155R61C105KA12D | 490-10694-1-ND | C77006 | C8, C11, C12, C16, C17, C20, C21, C23, C25, C30–C33 |
| GRM155R60J106ME44D | 490-13811-2-ND | C76991 | C15, C22, C26 |
| GRM1555C1H220JA01D | 490-5868-1-ND | C76960 | C28 |
| GRM1555C1H270JA01D | 490-5869-1-ND | C76961 | C14, C18 |
| LTST-C170GKT | 160-1179-1-ND | C125090 | D1 |
| LTST-C170KFKT | 160-1413-1-ND | C284931 | D2 |
| LTST-C170KRKT | 160-1415-1-ND | C94868 | D3 |
| TPS7A2025PDBVR | 296-TPS7A2025PDBVRCT-ND | C2869949 | U4 |
| DP83867IRPAPR | 296-46083-1-ND | C477933 | U2 |
| BSS138LT1G | BSS138LT1GOSCT-ND | C82045 | Q1–Q3 |
| ECS-2520MV-250-CN-TR | XC2752TR-ND | C405464 | Y1 |
| 1840888-1 (Bel Fuse) | 5923-1840888-1-ND | C5876366 | J1 |
| PocketBeagle 2 (BeagleBoard MPN `102110780`) | 2820-102110780-ND | NA | U1 |

### Corrections made to existing data

- **All three 0805 LED `LCSC` fields were wrong** — they held the *0603* parts' values,
  copy-pasted: green had the literal string `LTST-C190GKT` (an MPN, not a C-number),
  orange had `C7297440` (the 0603 orange) and red had `C913101` (the 0603 red
  `LTST-C194KRKT`). All three would have ordered the wrong LED. Now C125090 / C284931 /
  C94868.
- **Upstream bug fixed in passing**: the pre-existing house 0603 symbol
  `LED_Green_2.1V_0.03A_0603` also had its `LCSC` field set to the MPN string
  `LTST-C190GKT` instead of a part number — corrected to `C125093`. This is the source
  the 0805 green was copied from.

### Still `TBD`, and why

| Field | Reason |
|---|---|
| `TPS7A2011PDBVR` → Digikey, LCSC | part does not exist — see Q1 |
| `Header_18x02…` (BHR-36-VUA) → Digikey, LCSC | part does not exist — see above |
| `PMOD_02x06` → MPN + all suppliers | no physical part chosen; symbol is lib stock and is not placed in this design |
| Mouser on Y1, J1, U1 | mouser.com bot-walls automated lookup and its numbers are not derivable. Confirmed product pages: oscillator `mouser.com/ProductDetail/ECS/ECS-2520MV-250-CN-TR`, PocketBeagle 2 `mouser.com/new/beagleboardorg/beagleboard-pocketbeagle-2/`. Mouser stocks Bel Fuse but no page for `1840888-1` was found. |

## Post-migration symbol fixes (M6, also in the submodule)

- `KL_Module:PocketBeagle2`: pin 15 (GND) `power_in` → `power_out` (the host board
  sources ground — makes GND ERC-driven); pin 59 (second 3.3V) `power_out` → `passive`
  (avoids output-vs-output conflict with pin 14; KiCad idiom for duplicated rail pins); pin 49 (second VOUT) `power_out` → `passive` for the same reason once the expansion headers connected both VOUT pins.
- `KL_PHY:DP83867IRPAPR`: RBIAS (15) `unspecified` → `passive`, XI (19) `unspecified`
  → `input`.

## Submodule state

19 commits on `kebag_logic_kicad_library` main (local only, **not pushed**), identity
`hackerman-kl`. The superproject records the new submodule SHA; push both after review.

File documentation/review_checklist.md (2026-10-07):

# Review checklist

Everything awaiting user review/decision after the shish-lan-style restructure, the KL
library migration, the expansion (stacking header) rework and the readability pass.
Check items off here; details live in [library_additions.md](library_additions.md) and
[connections.md](connections.md).

## A. Library parts (before pushing the submodule)

- [ ] **1.1 V LDO — BLOCKING.** `TPS7A2011PDBVR` **is not a real part number**: TI's
  `part-details` page 404s for it, Digi-Key returns no results, LCSC has no listing,
  and Digi-Key's TPS7A20 SOT-23-5 range skips 1.1 V entirely. Supplier fields left
  `TBD` on purpose. Decide between `TLV73311PDBVR` (real TI 1.1 V / 300 mA SOT-23-5,
  LCSC C2865431 — **pinout differs from TPS7A20, needs a pin-by-pin check**) and
  dropping U3 for the DP83867's internal core LDO. Detail in
  [library_additions.md Q1](library_additions.md).
- [x] **RJ45 `1840888-1`** — **RESOLVED: manufacturer is Bel Fuse Inc.** Digi-Key
  `5923-1840888-1-ND` (same `5923-` Bel prefix as the house `0826-1X4T-43-F`), LCSC
  `C5876366`. Shielded 10/100/1000 Base-T AutoMDIX MagJack with magnetics, no LEDs.
  `Datasheet` now points at LCSC's mirror of the manufacturer PDF — **swap in a
  belfuse.com URL if you have one**. Availability is poor: 26-week Digi-Key lead,
  0 stock at LCSC.
- [ ] **BSS138** — multi-sourced; onsemi `BSS138LT1G` chosen and now **verified**
  (Digi-Key `BSS138LT1GOSCT-ND`, LCSC `C82045`, 982 k in stock). Confirm, or name a
  preferred source (e.g. Nexperia BSS138P).
- [ ] **Capacitor specs** — all five Murata GRM155 part numbers are now **verified**,
  but the *choice* of X7R/C0G/X5R and 50/16/6.3 V is still derived, not from rev A.
  The 10 µF is only 6.3 V-rated on the 3V3 rail — check the derating policy, or
  provide the rev A BOM. **Sourcing risk:** `GRM155R60J106ME44D` (C15/C22/C26) is
  **discontinued at Digi-Key** (LCSC stocks 1.1 M; Digi-Key suggests
  `GRM155R60J106ME15D`), and `GRM155R61C105KA12D` is on a 17-week Digi-Key lead.
- [x] **Resistors** — all seven Vishay `CRCW0402…EDC` MPNs **verified** against
  Digi-Key product pages and LCSC; order numbers filled.
- [ ] **18x02 stacking header** — `BHR-36-VUA` **is not orderable** (no Digi-Key, no
  LCSC; the Adam Tech BHR series only comes in standard IDC counts …20, 34, 40) and
  its datasheet describes a *shrouded box header*, not the plain 2x18 pin header the
  footprint lays down. Left untouched on request; supplier fields stay `TBD`. Real
  equivalent if wanted: Adam Tech `PH2-36-UA`, Digi-Key `2057-PH2-36-UA-ND`.
- [x] **TBD supplier fields** — Digi-Key and LCSC filled for every part that exists
  (21 MPNs, 205 field writes across the library and all six sheets). Four Mouser
  fields remain `TBD`: mouser.com bot-walls automated lookup and its part numbers are
  not derivable from the MPN. See library_additions.md for the confirmed Mouser
  product-page links.
- [ ] **LED LCSC fields were wrong** (now fixed) — all three 0805 LEDs carried the
  0603 parts' LCSC values, so a JLCPCB order would have fitted the wrong LEDs. The
  pre-existing house 0603 green symbol had the same defect (`LCSC` = the MPN string
  `LTST-C190GKT`) and was corrected to `C125093` — **this one is an upstream fix,
  confirm before pushing the submodule.**
- [ ] **Upstream lib quirks** (found, deliberately not fixed): LED symbols carry the
  placeholder Value `LED_{color}_{U_F}_{I_F}`; the lib README library table names
  don't match the actual files (`KL_Ferrites` vs `KL_Ferrite_Bead`, …). Fix upstream?

## B. Design decisions to approve

- [ ] **R25** (RJ45 VCC feed from `VDD_2V5`) migrated as **0R with the KiCad DNP
  attribute** — confirm the value choice.
- [ ] **C30/C32 pin swap** — pins 1/2 swapped vs rev A (non-polarized input caps,
  electrically identical; artifact of the redrawn LDO sheets).
- [ ] **PocketBeagle2 symbol pin types** — one GND pin is `power_out` (the host board
  sources ground), the duplicate 3.3V and VOUT pins are `passive` (KiCad idiom to
  avoid output-vs-output ERC conflicts).
- [ ] **Pass-through semantics** — cap-used signals (RGMII, MDIO, RESET/INT on the
  SPI0 pins) are exposed 1:1 on J2/J3; stacked modules must not drive them
  (documented in connections.md). OK?
- [ ] **PWR_FLAG rails** — rails a stacked module may legally drive: `VIN`,
  `USB1_VIN`, `BAT_VIN`, `AIN_VREF_P`, `AIN_VREF_N`. Confirm this matches the
  intended stacking topology.
- [ ] **Audio removal consequences** — the MCLK 0R selection matrix (R1–R4) is gone;
  MCASP/TIMER/EXT_REFCLK pins are plain pass-through now. The PMOD symbol
  (`KL_Conn_Data:PMOD_02x06`) and `06x02_2.54mm_SMD_Header` footprint remain in the
  KL library as stock — keep or drop?
- [ ] **Sheet naming deviation** — the clock sheet is `oscillator.kicad_sch` (plan
  said `crystal.kicad_sch`; the part is an oscillator, not a crystal).

## C. Housekeeping / publishing

- [ ] Delete the duplicate untracked `Requirements` file (`requirements.md` is
  committed and is a superset).
- [ ] **Submodule**: 25 commits on branch `pocketbeagle-2`, **not pushed** — push /
  open a PR (upstream uses branch-per-issue) once section A is approved.
- [ ] Decide whether local submodule `main` should be reset to `origin/main` (it
  still shows "ahead 20" from before the branch existed).
- [ ] Push the superproject `main` when ready.
- [ ] Open the project in KiCad once — headless rendering can't judge everything
  (fonts, print scale, personal preference). ERC should report 0 errors / 0 warnings.

## D. Known leftovers (low priority)

- [ ] Stray floating GND symbol in `phy.kicad_sch` at (43.18, 91.44) — pre-existing
  rev A cruft, harmless; delete on request.
- [ ] `current_consumption.md` has TBD figures awaiting the DP83867 power-table
  numbers per operating mode.
- [ ] Root title block still says "Gigabit EthernetCap, Rev V0.1, 2025-08-19" —
  bump revision/date if this rework warrants it.
- [ ] Flight-time matching on the RGMII (open since rev A) — becomes relevant again
  when routing resumes; the RGMII_TX/RGMII_RX netclasses and skew DRC rules are
  repaired and active.

## Verification status (for reference)

| Check | Result |
|---|---|
| ERC (last commit) | 0 errors, 58 warnings — the warnings are `lib_symbol_mismatch`, expected while the submodule is ahead of the committed sheets |
| ERC (working tree, 2026-07-27) | **6 errors, 3 warnings** — see the note below |
| Netlist vs rev A | identical node-sets (incl. power flags); only net *names* re-scoped (pass-through nets now `/io/*`) |
| IO pass-through | all 72 U1 pins match J2/J3 1:1 (scripted check) |
| Connectivity | fully hierarchical: 0 global labels, GND via power symbols, inter-sheet via ports |
| Libraries | 100 % `KL_*` + `power:` symbols, 100 % `KL_Footprints` footprints |
| BOM export | grouped, with MPN/Mouser/Digikey/LCSC columns |
| PCB file | byte-identical to tag `revA-routed` (rename only) |

> **ERC regression in the uncommitted working tree.** `kicad-cli sch erc` on the current
> tree reports 6 errors / 3 warnings, against 0 errors at `HEAD`. They are **not** from
> the supplier-field pass — re-running ERC with every one of those 205 field writes
> reverted gives the same 6 errors. They come from the uncommitted sheet edits that were
> already in the tree: 4 × `pin_to_pin` "Power output connected to Power output",
> 1 × `power_pin_not_driven`, 1 × `ground_pin_not_ground` (U1 pin 51 GND), plus
> `unconnected_wire_endpoint`, `pin_not_connected` and a `lib_symbol_mismatch` on
> `KL_Module:PocketBeagle2`. That last one is a one-character issue: the cached symbol
> in `io.kicad_sch` now has `Reference` = `U1` where the library says `U` (`HEAD` still
> says `U`). Worth resolving before the next commit.

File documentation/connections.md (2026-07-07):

# Schematic Connections — PocketBeagle 2 ↔ DP83867 Ethernet Cap

## Scope

Detailed information about the connections between the PocketBeagle 2 (AM62x, "CPU"),
the DP83867IRPAPR gigabit PHY ("PHY") and the RJ45 magjack. Net names follow
[naming_convention.md](naming_convention.md).

## RGMII (CPU ↔ PHY)

- 12 signals: `RGMII_TD0..3_CPU_to_PHY`, `RGMII_TX_CLK_CPU_to_PHY`,
  `RGMII_TX_CTRL_CPU_to_PHY`, `RGMII_RD0..3_PHY_to_CPU`, `RGMII_RX_CLK_PHY_to_CPU`,
  `RGMII_RX_CTRL_PHY_to_CPU` — routed on the PocketBeagle 2 RGMII2 header pins.
- Every RGMII line has a **22R series resistor** (R8–R19) placed near the driver end.
- Skew/length matching is enforced by the custom DRC rules
  (`pocketbeagle2_ethernet_cap.kicad_dru`) via the net classes **RGMII_TX** and
  **RGMII_RX** (3 mm window). The classes are defined in the project settings; the rev A
  board carried the internal PHY RGMII delay (flight-time matching still open, see
  rev A commit history).

## MDI (PHY ↔ RJ45)

- `MDI0..3_PHY_RJ45_P/_N` — four differential pairs, connected **directly** from the
  PHY to the 1840888-1 jack: the magnetics are integrated in the jack, no external
  Bob-Smith termination on the pairs in rev A.
- Jack center tap / VCC (`Net-(J1-VCC)`) can be fed from `VDD_2V5` through **R25 (0R,
  DNP)** — unpopulated by default.
- Both shield tabs go to GND through 0R resistors (R26, R29).

## MDIO (CPU ↔ PHY)

- `MDIO_MDC_CPU_PHY`, `MDIO_DIO_CPU_PHY` — shared management bus, participants listed
  per convention (no direction encoded). Pull-ups: R20/R21/R24 (2.2K to `VDD_3V3`).

## Clocking

- `CLK_25M_OSC_to_PHY`: ECS-2520MV-250-CN-TR 25 MHz HCMOS oscillator (Y1, own
  `oscillator` sheet) → series C14 (22 pF) → PHY XI (pin 19). C18 (27 pF) shunts the
  XI node to GND; TP4 probes the clock. Y1 runs from `VDD_3V3` (C4 100n decoupling).
- PHY `CLK_OUT` (pin 22) is only brought to test point TP2.

## Reset / Interrupt / Straps

- `RESET_N_CPU_to_PHY`: CPU GPIO → PHY RESET_N (pin 59).
- `INT_PWDN_N_CPU_PHY`: dual-function open-drain INT/PWDN — bidirectional by protocol,
  so participants are listed without direction.
- Strap nets `STRAP_RX_CTRL_PHY` / `STRAP_RX_D7_PHY` carry the RX_CTRL / RX_D7 strap
  dividers (R5 5K76, R6/R7 2K49). `RBIAS` (pin 15) has R22 = 11K 1% to GND.
- PHY status LEDs: `LED0_PHY_to_Q1` … `LED2_PHY_to_Q3` drive BSS138 gates (Q1–Q3);
  the FETs sink D1–D3 (0805 green/orange/red) from `VDD_3V3` via 200R (R23/R27/R28).

## io sheet — PocketBeagle host + stacking headers

U1 (PocketBeagle 2) and the two 18x02 (36-pin) pass-through headers live on the `io`
sheet. Every PB2 IO is routed 1:1 to J2/J3 as **sheet-local nets** so the PB2 + cap
stack can sit on top of (or under) other modules:

- **J2** mirrors P1 (header pin k = U1 pin k), **J3** mirrors P2 (header pin k =
  U1 pin 36+k). Pin numbering follows the PB2 zigzag convention.
- Signals used by the cap (RGMII, MDIO, reset/interrupt, `VDD_3V3`) leave `io` as
  **hierarchical ports** to the root block diagram, and also pass through to J2/J3 - a
  stacked module sees them and must not drive them.
- All other pins carry their PB2 pin-function net names (`GPIO47`, `I2C2_SDA`,
  `UART0_TX`, `SPI0_MOSI`, `MCASP2_ACLKX`, `AIN5`, ...). The former audio PMOD
  circuitry (rev A) was removed; the MCASP/TIMER/EXT_REFCLK pins are now plain
  pass-through.
- `PWR_FLAG`s mark the power-input rails a stacked module may legally drive:
  `VIN`, `USB1_VIN`, `BAT_VIN`, `AIN_VREF_P`, `AIN_VREF_N`.

## Power tree

```
PocketBeagle 2 VDD_3V3 (P1.14/P2.23 rails)
├── PHY VDDIO (3x), oscillator, pull-ups, LED anodes
├── ldo_2v5: U4 TPS7A2025PDBVR -> VDD_2V5 -> PHY VDDA2P5, (R25/DNP -> J1 VCC)
└── ldo_1v1: U3 TPS7A2011PDBVR -> VDD_1V1 -> PHY VDD1P1 (core)
```
Each LDO sheet: 1u in + 1u out + 100n input decoupling, EN tied to input rail,
test points on input and output rails.

## Net rename map (rev A → current)

| rev A | current |
|---|---|
| RGMII_TD0..3 | RGMII_TD0..3_CPU_to_PHY |
| RGMII_TX_CLK / TX_CTRL | RGMII_TX_*_CPU_to_PHY |
| RGMII_RD0..3 / RX_CLK / RX_CTRL | RGMII_*_PHY_to_CPU |
| MDIO0_MDC / MDIO_MDC | MDIO_MDC_CPU_PHY |
| MDIO0_DIO / MDIO_DIO | MDIO_DIO_CPU_PHY |
| RESET_N / RST_N | RESET_N_CPU_to_PHY |
| INT_N/PWRDN_N / INT_PWDN_N | INT_PWDN_N_CPU_PHY |
| X_IN | CLK_25M_OSC_to_PHY |
| MD0..3_P/N | MDI0..3_PHY_RJ45_P/N |
| LED0/1/2 | LED0..2_PHY_to_Q1..3 |
| RX_CTRL / RX_D7 (straps) | STRAP_RX_CTRL_PHY / STRAP_RX_D7_PHY |
| 1V1 / 2V5 / 3V3 (hier) | VDD_1V1 / VDD_2V5 / VDD_3V3 |
| BCLK / LRCK / PMOD* / MCLK* (audio, removed) | MCASP2_ACLKX / MCASP2_AFSX / MCASP2_AXR0/1 / MCASP_AXR12/13 / TIMER_IO0/1 / EXT_REFCLK1 (plain pass-through) |

Known accepted ERC warnings: local rail labels intentionally share the global
`VDD_*` names inside child sheets (`same_local_global_label`, 3x) — connectivity is
via hierarchical pins and was netlist-verified against rev A.

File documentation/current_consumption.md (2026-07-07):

# Current consumption (estimate)

| Rail | Consumer | Estimate | Source |
|---|---|---|---|
| VDD_3V3 (from PocketBeagle 2) | DP83867 VDDIO + oscillator + LEDs + pull-ups | TBD | — |
| VDD_2V5 (TPS7A2025PDBVR, 300 mA max) | DP83867 VDDA2P5 | TBD | DP83867 total: ~490 mW (PAP pkg, ti.com datasheet) |
| VDD_1V1 (TPS7A2011PDBVR, 300 mA max) | DP83867 VDD1P1 core | TBD | — |
| Oscillator | ECS-2520MV | < 6 mA typ. | ECS-2520MV datasheet |

TODO: fill per-rail figures from the DP83867 datasheet power tables for RGMII/1000Base-T
operation and verify the LDO thermal budget (SOT-23-5).

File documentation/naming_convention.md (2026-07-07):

# Signal Naming Convention

This section defines the mandatory signal naming rules for the PocketBeagle 2 Ethernet Cap project. The goal is to eliminate ambiguity, make signal direction obvious, and keep schematics readable and review friendly.

## General Principles

- Signal names must communicate electrical reality, not assumptions
- Direction must be explicit only where it is unambiguous
- Protocol behavior takes precedence over stylistic consistency
- Readability is preferred over extreme compactness

## 1. Point to Point Signals

For single driver, single receiver connections, use the following format:

`<signal-name>_<source-ic>_to_<sink-ic>`

### Examples

```
UART_TX_CPU_to_DEBUG
RMII_TXD0_SWITCH_to_PHY
CLK_25M_OSC_to_PHY
RESET_SUPERVISOR_to_SWITCH
```

This format must be used whenever the electrical direction is fixed and known.

## 2. TX / RX Communication Links

Do not rely on TX or RX alone to indicate direction. The source and sink must be encoded in the name.

### Examples

```
UART_TX_CPU_to_DEBUG
UART_RX_DEBUG_to_CPU
SPI_MOSI_CPU_to_FLASH
SPI_MISO_FLASH_to_CPU
```

This removes all ambiguity during schematic review and debugging.

## 3. Shared and Bidirectional Buses

For buses with bidirectional or multi driver signals, direction must not be encoded in the net name. Instead, list all participating devices.

### Examples

```
I2C_SCL_CPU_EEPROM
I2C_SDA_CPU_EEPROM
MDIO_MDIO_SWITCH_PHY
MDIO_MDC_SWITCH_PHY
```

Direction is defined by the protocol and must not be implied incorrectly by the net name.

## 4. Broadcast and Multi Sink Signals

For signals that drive multiple devices, avoid enumerating all sinks unless required for clarity.

### Preferred approaches

- Functional domain naming
- Logical grouping of recipients

### Examples

```
RESET_AVB_DOMAIN
RESET_PHYS
SYNC_AUDIO_DOMAIN
```

If a signal is duplicated intentionally, separate nets may still use the point to point scheme.

## 5. Clock Signals

Clock sources must always be explicitly named.

### Examples

```
CLK_25M_OSC_to_PHY
CLK_125M_SWITCH_to_PHY
CLK_24M_OSC_to_CPU
```

Clock direction must never be ambiguous.

## Summary Rules

1. Use `<signal>_<source>_to_<sink>` for point to point signals
2. Do not encode direction for bidirectional or shared buses
3. Name broadcast signals by function or domain
4. Net names must always reflect electrical reality

Consistency with these rules is mandatory across all schematics in the project.

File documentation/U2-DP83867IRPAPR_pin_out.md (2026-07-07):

# U2 - DP83867IRPAPR pin-out

Generated from `KL_PHY:DP83867IRPAPR`. Electrical types as modeled in the symbol.

| Pin | Name | Type |
|---|---|---|
| 1 | RESERVED | unspecified |
| 2 | TD_P_A | bidirectional |
| 3 | TD_M_A | bidirectional |
| 4 | VDDA2P5 | power_in |
| 5 | TD_P_B | bidirectional |
| 6 | TD_M_B | bidirectional |
| 7 | RESERVED | unspecified |
| 8 | VDD1P1 | power_in |
| 9 | RESERVED | unspecified |
| 10 | TD_P_C | bidirectional |
| 11 | TD_M_C | bidirectional |
| 12 | VDDA2P5 | power_in |
| 13 | TD_P_D | bidirectional |
| 14 | TD_M_D | bidirectional |
| 15 | RBIAS | unspecified |
| 16 | RESERVED | unspecified |
| 17 | VDDA1P8 | power_in |
| 18 | XO | unspecified |
| 19 | XI | unspecified |
| 20 | MDC | input |
| 21 | MDIO | bidirectional |
| 22 | CLK_OUT | output |
| 23 | VDDIO | power_in |
| 24 | JTAG_TRSTN | input |
| 25 | JTAG_CLK | input |
| 26 | JTAG_TDO | output |
| 27 | JTAG_TMS | input |
| 28 | JTAG_TDI | input |
| 29 | VDD1P1 | power_in |
| 30 | TX_CLK | output |
| 31 | TX_D7 | input |
| 32 | TX_D6 | input |
| 33 | TX_D5 | input |
| 34 | TX_D4 | input |
| 35 | TX_D3 | input |
| 36 | TX_D2 | input |
| 37 | TX_D1 | input |
| 38 | TX_D0 | input |
| 39 | TX_ER | input |
| 40 | GTX_CLK | input |
| 41 | VDDIO | power_in |
| 42 | VDD1P1 | power_in |
| 43 | RX_CLK | output |
| 44 | RX_D0 | output |
| 45 | RX_D1 | output |
| 46 | RX_D2 | output |
| 47 | RX_D3 | output |
| 48 | RX_D4_GPIO | bidirectional |
| 49 | RX_D5_GPIO | bidirectional |
| 50 | RX_D6_GPIO | bidirectional |
| 51 | RX_D7_GPIO | bidirectional |
| 52 | TX_EN_TX_CTRL | bidirectional |
| 53 | RX_DV_RX_CTRL | bidirectional |
| 54 | RX_ER_GPIO | bidirectional |
| 55 | COL_GPIO | output |
| 56 | CRS_GPIO | bidirectional |
| 57 | VDDIO | power_in |
| 58 | VDD1P1 | power_in |
| 59 | RESET_N | input |
| 60 | INT_PWDN | bidirectional |
| 61 | LED_2 | bidirectional |
| 62 | LED_1 | bidirectional |
| 63 | LED_0 | bidirectional |
| 64 | VDDA1P8 | power_in |
| 65 | GND | power_in |
| V | NC | input |

Datasheet: https://www.ti.com/lit/gpn/dp83867ir

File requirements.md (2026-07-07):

# Requirements

The goal of the his project is to reproduce the same type of structure as the
shish-lan switch.

The goal would not be to do the routing so far, just to ensure everything works.
The library is broken must be similar to the library use in the shish-lan (../shish-lan)

Make sure that everything is documented for the decision and for each element added (footprint etc...)
make sure that the user review them.
Similar for the different connection

Divide the design in different sheet for a better usage.
Any documentation necessary either look it online or ask the user (datsheet etc...)
Do no make any assumption, ask the user if needed.

If a tool was to miss i can install it for you

The project in itself is documented in the README.md

## Commits

Do small incremental commits, one line message hackerman-kl no co-authored.

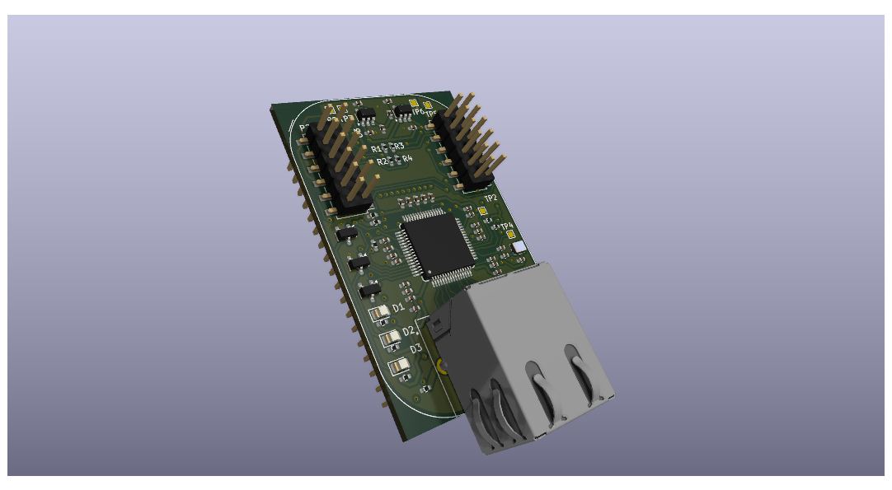
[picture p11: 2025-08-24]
res/images/pocketbeagle2_revA_241205_3_4.png

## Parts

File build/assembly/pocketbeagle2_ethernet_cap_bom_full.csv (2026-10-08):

Designator | Quantity | Value | Manufacturer | MPN | Footprint | LCSC | Digikey | Mouser | Assembled by JLCPCB
C1,C2,C3,C4,C5,C6,C7,C9,C10,C13,C34,C35 | 12 | 100n |  | CL05B104KB54PNC | C_0402 | C307331 |  |  | yes
C8,C11,C12,C16,C17,C20,C21,C23,C25,C30,C31,C32,C33,C37,C38,C39,C40 | 17 | 1u |  | GRM155R61C105KA12D | C_0402 | C77006 | 490-10694-1-ND | 81-GRM155R61C105KA12D | yes
C14 | 1 | 27p |  | 0402CG270J500NT | C_0402 | C1557 |  |  | yes
C15,C22,C26 | 3 | 10u |  | GRM155R60J106ME44D | C_0402 | C76991 | 490-13811-2-ND | 81-GRM155R60J106ME44D | yes
C18 | 1 | 22p |  | GRM1555C1H220JA01D | C_0402 | C76960 | 490-5868-1-ND | 81-GRM1555C1H220JA01D | yes
C19,C24,C27 | 3 | 10n |  | GRM155R71H103KA88D | C_0402 | C77019 | 490-4516-1-ND | 81-GRM155R71H103KA88D | yes
C36 | 1 | 4n7 |  | C1210C472KGRACTU | C_1210 | C2167834 |  |  | yes
D1 | 1 | Green |  | LTST-C170GKT | LED_0805 | C125090 | 160-1179-1-ND | 859-LTST-C170GKT | yes
D2 | 1 | Orange |  | LTST-C170KFKT | LED_0805 | C284931 | 160-1413-1-ND | 859-LTST-C170KFKT | yes
D3 | 1 | Red |  | LTST-C170KRKT | LED_0805 | C94868 | 160-1415-1-ND | 859-LTST-C170KRKT | yes
J1 | 1 | RJ45_1840888-1 | BELFUSE | 1840888-1 | BEL_1840888-1 | C5876366 | 5923-1840888-1-ND | TBD | no
J1-Alternative | 1 | RJ45_1840888-1 | TE | 5-2301994-7 | BEL_1840888-1 | C5902577 | A126256-ND | 571-5-2301994-7 | no
J2,J3 | 2 | Header_18x02_2.54mm_2.54mm_Straight |  | HC-PZ254-11.5L-2x18PZ | 18x02_2.54mm_Header | C41376109 |  |  | yes
Q1,Q2,Q3 | 3 | BSS138LT1G |  | BSS138LT1G | SOT-23 | C82045 | BSS138LT1GOSCT-ND | 863-BSS138LT1G | yes
R5,R7,R32 | 3 | 2K49 |  | CRCW04022K49FKEDC | R_0402 | C1730862 | 541-4867-1-ND | 71-CRCW04022K49FKEDC | yes
R8,R9,R10,R11,R12,R13,R14,R15,R16,R17,R18,R19 | 12 | 22R |  | 0402WGF220JTCE | R_0402 | C25092 |  |  | yes
R20,R21,R24 | 3 | 2K2 |  | CRCW04022K20FKEDC | R_0402 | C2076947 | 541-3971-1-ND | 71-CRCW04022K20FKEDC | yes
R22 | 1 | 11K |  | FRC0402F1102TS | R_0402 | C2909313 |  |  | yes
R23,R27,R28 | 3 | 200R |  | 0402WGF2000TCE | R_0402 | C25087 |  |  | yes
R29 | 1 | 1M |  | CRCW12061M00FKEA | R_1206 | C844869 |  |  | yes
R30,R31 | 2 | 5K76 |  | FRC0402F5761TS | R_0402 | C5153969 |  |  | yes
TP1,TP2,TP4,TP5,TP6,TP7,TP8 | 7 | TestPoint_SMD |  |  | TestPoint_SMD_1.0x1.0mm |  |  |  | no
U1 | 1 | PocketBeagle2 |  | PocketBeagle 2 | BeagleBoard_PocketBeagle | NA | 2820-102110780-ND | TBD | no
U2 | 1 | DP83867IRPAPR |  | DP83867IRPAPR | HTQFP-64_10x10mm_P0.5mm | C477933 | 296-46083-1-ND | 595-DP83867IRPAPR | yes
U3 | 1 | TLV73311PDBVR |  | TLV73311PDBVR | SOT-23-5 | C2865431 |  |  | yes
U4 | 1 | TPS7A2025PDBVR |  | TPS7A2025PDBVR | SOT-23-5 | C2869949 | 296-TPS7A2025PDBVRCT-ND | 595-TPS7A2025PDBVR | yes
Y1 | 1 | 25M |  | ECS-2520MV-250-CN-TR | ECS-2520MV | C405464 | XC2752TR-ND | TBD | yes

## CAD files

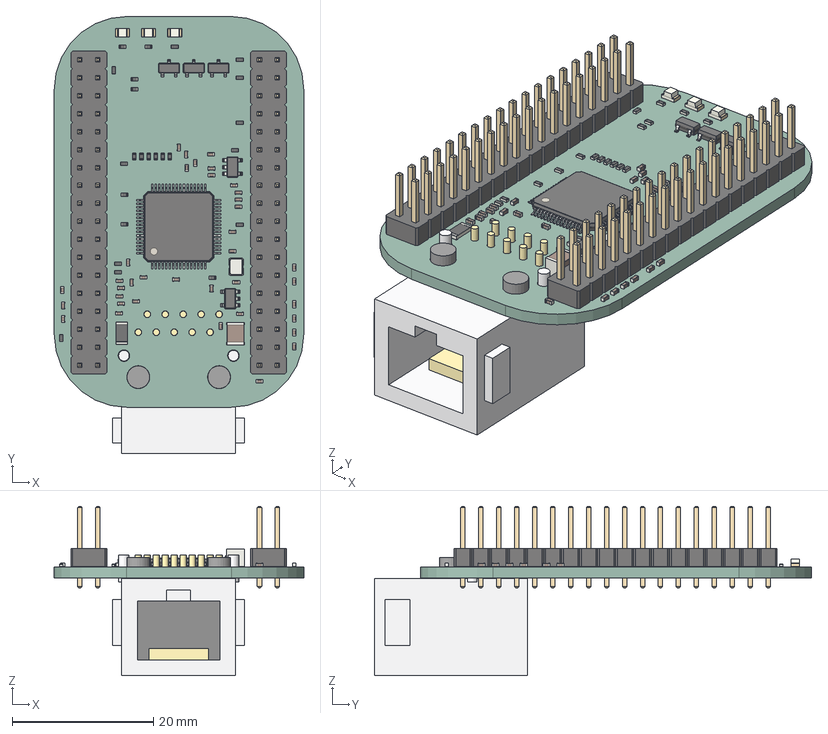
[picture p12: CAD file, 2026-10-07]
build/docs/pocketbeagle2_ethernet_cap_cape.step
35.3 x 61.8 x 24.0 mm
R_0402_1005Metric x 24
LED_0805_2012Metric x 3
C_0402_1005Metric x 37
SOT-23-5 x 2
R_1206_3216Metric
PinHeader_2x18_P254mm_Vertical x 2
SOT-23 x 3
C_1210_3225Metric
Oscillator_SMD_SeikoEpson_SG210-4Pin_2.5x2.0mm
TQFP-64-1EP_10x10mm_P0.5mm_EP5.305x5.305mm
shield
cavity
contacts
emi_finger1
emi_finger2
pin1
pin2
pin3
pin4
pin5
pin6
pin7
pin8
pin9
pin10
shield_pin1
shield_pin2
peg1
peg2
pocketbeagle2_ethernet_cap_PCB

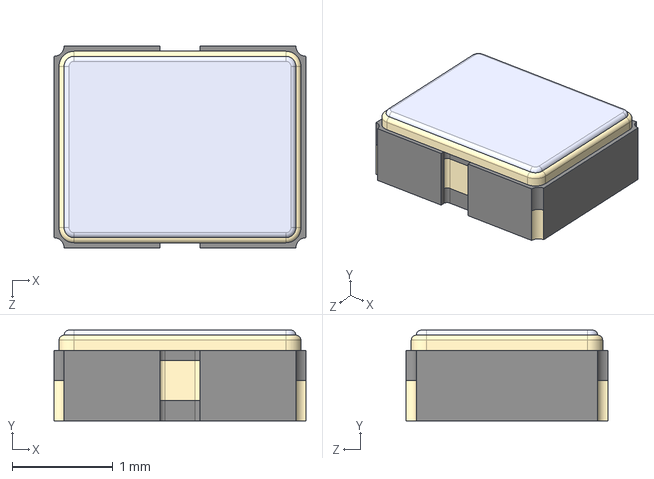
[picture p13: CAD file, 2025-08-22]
footporint_manual/ECS_2520MV_250_CN_TR/ECS-2520MV-250-CN-TR.step
2.50 x 0.9 x 2.00 mm

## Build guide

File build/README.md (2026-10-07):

# Build outputs: PocketBeagle 2 Ethernet cape, rev B

Everything needed to fabricate and assemble the board, generated from the committed schematic and PCB with:

```
python tools/make_build.py            # needs kicad-cli (KiCad 10); drawing needs shapely + matplotlib
python tools/make_build.py --no-step  # skip the 3D STEP export
```

Regenerate after every design change. Don't edit these files by hand.

```
build/
├── fabrication/
│   ├── pocketbeagle2_ethernet_cap_gerber.zip   ← upload this to JLCPCB (PCB order)
│   ├── gerber/                                 Gerber X2 layers + Excellon PTH/NPTH drill + drill maps + job file
│   └── pocketbeagle2_ethernet_cap.ipc          IPC-D-356 netlist (bare-board electrical test)
├── assembly/
│   ├── pocketbeagle2_ethernet_cap_bom_jlcpcb.csv   ← JLCPCB SMT assembly BOM (Comment, Designator, Footprint, LCSC #)
│   ├── pocketbeagle2_ethernet_cap_cpl_jlcpcb.csv   ← JLCPCB pick & place (Designator, Mid X/Y, Layer, Rotation)
│   ├── pocketbeagle2_ethernet_cap_bom_full.csv     every part, with MPN, LCSC, DigiKey, Mouser, assembled yes/no
│   └── pocketbeagle2_ethernet_cap_assembly.pdf     assembly drawing, every reference on its part (vector, zoom in)
└── docs/
    ├── pocketbeagle2_ethernet_cap_schematic.pdf
    ├── pocketbeagle2_ethernet_cap_cape.step        3D of the assembled cape (without the PocketBeagle 2)
    └── pocketbeagle2_ethernet_cap_drc.rpt          DRC report: 0 errors, warnings listed below
```

## PCB order (JLCPCB)

- **4 layers, 1.6 mm, JLC04161H-3313 stackup.**
  - Layers: F / 0.1 mm prepreg / In1 GND / core / In2 GND / 0.1 mm prepreg / B.
  - Board size: 35.3 × 55.3 mm, with rounded corners.
- **Order impedance control**, and let JLC adjust the trace widths to their stackup:
  - RGMII: 50 Ω single-ended, drawn at 0.15 mm. Their 3313 calculator gives about 0.17–0.19 mm.
  - MDI: 100 Ω differential, drawn at 0.13 mm width with a 0.2 mm gap.
- Design limits, all within JLC standard capability:
  - Track 0.1 mm, space 0.15 mm.
  - Vias 0.45 mm with a 0.2 mm drill (0.125 mm ring).
  - Copper to edge ≥ 0.5 mm.
  - Legend text 1.0 mm high with a 0.15 mm stroke.
- J1 (the magjack) overhangs the bottom board edge by design.

## Assembly (JLCPCB, single-sided top)

- **Every SMD part is on the top side.**
- The bottom has only J1 and the test pads TP1/2/4/6/8, which get no part.
- J2/J3 (HC-PZ254-11.5L-2x18PZ, C41376109) are THT on the top. JLC fits them as through-hole assembly.
- **Not in the JLC BOM/CPL** (all are in `bom_full.csv`):
  - U1: the PocketBeagle 2 plugs onto J2/J3.
  - J1: magjack, THT on the bottom, hand-soldered. The schematic says Bel 1840888-1, which has no stock anywhere. Fit the drop-in **TE 5-2301994-7** instead (DigiKey). Leave pin 1 unsoldered. See handover 2.4.
  - TP1–TP8: test pads only.
- Every LCSC number was in stock when the files were generated. Low stock to watch:
  - U2 DP83867IRPAPR (C477933)
  - C36 (C2167834)
  - U4 TPS7A2025PDBVR (C2869949)
- **Check rotations in JLC's placement preview**, especially Q1–Q3 (SOT-23), U3/U4 (SOT-23-5), U2 (HTQFP-64) and the LEDs D1–D3. JLC's package origins can differ from KiCad's.

## Silkscreen

- 64 of 81 references are printed at 1.0 mm (0.65 mm character width).
- 17 densely packed 0402 parts have no room for a legible reference. Use the assembly drawing for those.

## DRC warnings (expected)

- J2/J3 share the PocketBeagle 2 (U1) holes by design.
- 4 library-mismatch notices.
- U4 legend clipped at J1.1 (an unused pad).
- J1 back-side legend past the edge (the overhang).
- VOUT is not connected on the cape, because the PocketBeagle 2 joins U1.24/U1.49 internally.

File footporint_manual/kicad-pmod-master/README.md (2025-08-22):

KiCad PMOD compatible connector Library
=======================================

KiCad Library to make it easy to create both host boards and expansion boards
and which are compatible with the Digilent "PMOD" specification.

Library has;
 * Schematic components for "Host Side" and "Device Side" for the following PMOD types;
  * Type 1 - GPIO (plus what I call Type 1A which is a "dual" Type 1 connector).
  * Type 2 - SPI
  * Type 2A - Expanded SPI
  * Type 3 - Old style UART
  * Type 4 - New style UART
  * Type 4A - Expanded new style UART
  * (TODO) Type 5 - H-Bridge
  * (TODO) Type 6 - Dual H-Bridge

 * (TODO) PCB module footprints.
 * (TODO) KiCad templates

PMOD
======================

Pmod interface or Peripheral Module interface is a standard defined by Digilent
Inc in the
[Digilent Pmod™ Interface Specification](http://www.digilentinc.com/Pmods/licensing.cfm)
for peripherals used with FPGAs or micro-controllers.

A lot of [Pmod information is collected in the following Google Spreadsheet
](https://docs.google.com/spreadsheets/d/1D-GboyrP57VVpejQzEm0P1WEORo1LAIt92hk1bZGEoo/edit#gid=826995092)

The PMOD header is found on a wide variety of FPGA boards including many not
developed by Digilent,

 * [Atlys](http://www.digilentinc.com/atlys/)
   a Xilinx Spartan 6, video testing platform.
   The board only has 1 "dual" PMOD header by default but can have another 4
   dual added by the vmod-mib expansion board.

 * [Zybo](http://www.digilentinc.com/Products/Detail.cfm?NavPath=2,400,1198&Prod=ZYBO),
   A low cost Xilinx Zynq development board.
   The board has 5 dual PMOD headers and one dual Analog PMOD header.

 * [Zedboard](http://zedboard.org/product/zedboard),
   A higher end, very popular Xilinx Zynq development board.
   The board has 5 dual PMOD headers.

 * [Mimas V2](http://numato.com/us/fpga-boards/xilinx/spartan6.html)
   A budget Spartan 6 board with plenty of power.
   The board has 5 dual PMOD headers.

 * [Arty A7](https://reference.digilentinc.com/reference/programmable-logic/arty-a7/start)
   An affordable Xilinx Artix-7 development board.
   The board has 4 dual PMOD headers.

Example Pmod expansion boards can be purchased from;

 * Digilent at http://www.digilentinc.com/Products/Catalog.cfm?NavPath=2,401&Cat=9
 * Numato at http://numato.com/fpga-boards/expansion-modules.html
 * Zedboard at http://zedboard.org/accessories/pmod
 * Maxim at http://www.maximintegrated.com/en/design/design-technology/fpga-design-resources/pmod-compatible-plug-in-peripheral-modules.html

PMOD "Extensions"
---------------------

There are a number of unofficial extensions to the PMOD standard. These include;
 * Using multiple PMOD headers which are next to each other.
 * An "Analog PMOD header" found on the Zybo.
 * An "High speed PMOD header" found on the Zybo.

Contributing
======================

I **love** contributions. Just fork and send me a pull request!

**If I don't respond to your pull request within a couple of days, please poke
me!**

If you make (or convert) these to Eagle, I'd be more than happy to include a
link to your repository.

Author & License
======================

This library was created by [Tim 'mithro' Ansell](https://blog.mithis.net/).

This library is released under the
[Apache 2.0 License](http://www.apache.org/licenses/LICENSE-2.0.html).

If you use this library for anything, I'd love an [email](mithro@mithis.com)
with a picture of the project (of course this isn't *required* at all). People
making open source hardware make me happy!

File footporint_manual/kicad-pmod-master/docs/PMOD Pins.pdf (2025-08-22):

PMod Interface | I2C Interface
Single Width PMod | Double Width PMod
Host | Edge | Peripheral 1 | 1 Host | 7 | Edge | Peripheral 1 7 | 1 | Edge
2 | | | 2 | 2 | 8 | | | 8 | 2 | 1 | 2 | SCL | SCL
3 | | | 3 | 3 | 9 | | | 9 | 3 | 3 | 4 | SDA | SDA
4 | | | 4 | 4 | 10 | | | 10 | 4 | 5 | 6 | GND | GND
5 | | | 5 | 5 | 11 | | | 11 | 5 | 7 | 8 | VCC | VCC
6 | | | 6 | 6 | 12 | | | 12 | 6
| 0.40" | 0.15" | | Top | Bot | 0.45" | 0.20" | Bot | Top

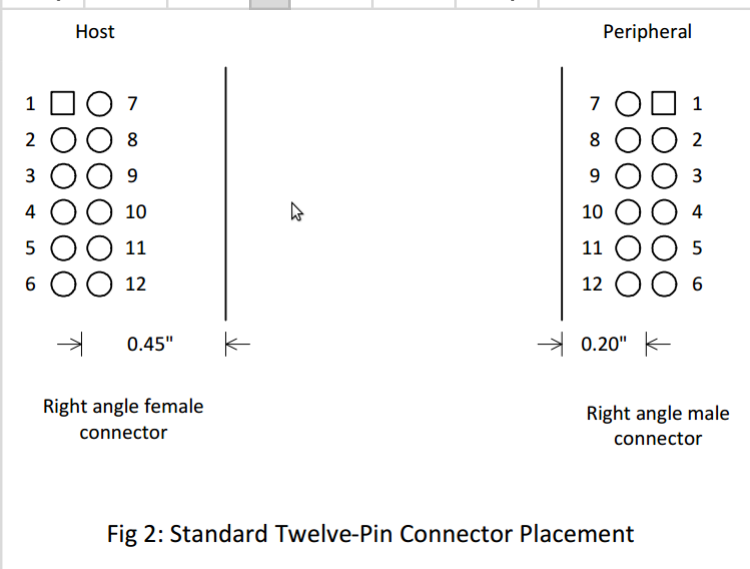
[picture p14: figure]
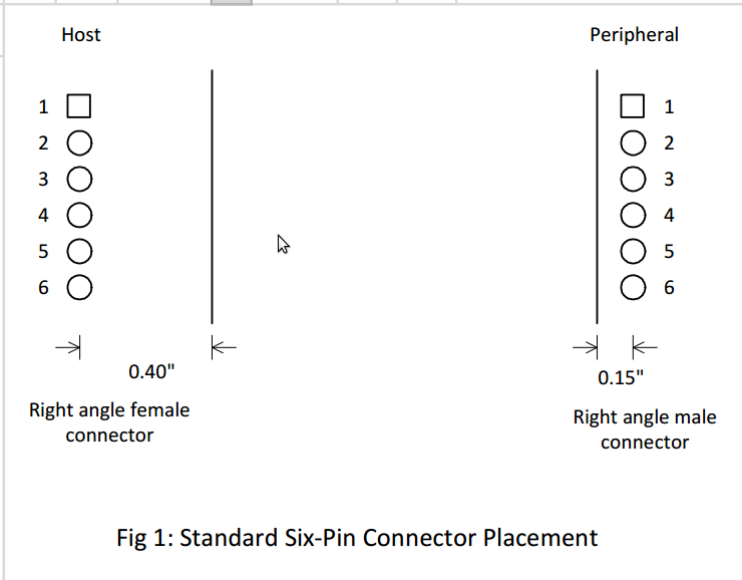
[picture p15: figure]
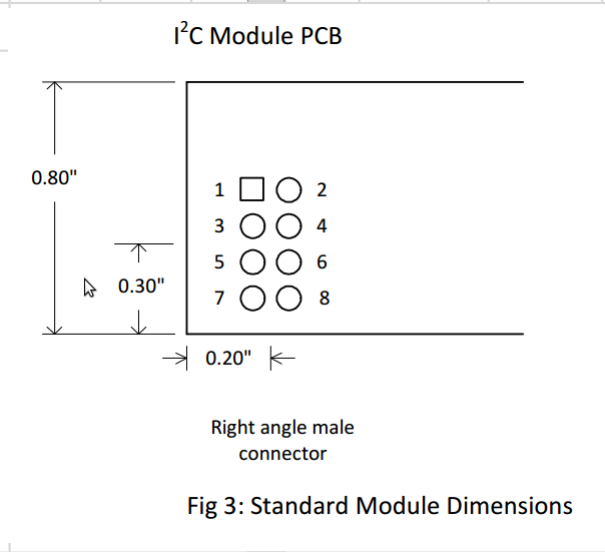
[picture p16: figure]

Pmod Pin | Standard Pin | | | Standard Pins | | Pmod Pins
1 | 2 | IO | Edge | 1 | 2 | Edge | 7 | 1
2 | 4 | IO | | 3 | 4 | | 8 | 2
3 | 6 | IO | | 5 | 6 | | 9 | 3
4 | 8 | IO | | 7 | 8 | | 10 | 4
5 | 10 | GND | | 9 | 10 | | 11 | 5
6 | 12 | VCC | | 11 | 12 | | 12 | 6
7 | 1 | IO
8 | 3 | IO
9 | 5 | IO
10 | 7 | IO
11 | 9 | GND
12 | 11 | VCC
Pmod Pin | Standard Pin | | | Standard Pins | | Pmod Pins
1 | 11 | IO | Edge | 12 | 11 | Edge | 7 | 1
2 | 9 | IO | | 10 | 9 | | 8 | 2
3 | 7 | IO | | 8 | 7 | | 9 | 3
4 | 5 | IO | | 6 | 5 | | 10 | 4
5 | 3 | GND | | 4 | 3 | | 11 | 5
6 | 1 | VCC | | 2 | 1 | | 12 | 6
7 | 12 | IO 8 | 10 | IO 9 | 8 | IO
10 | 6 | IO
11 | 4 | GND
12 | 2 | VCC

Type 1 GPIO | Type 1A Expanded GPIO | Type 2 SPI | Type 2A Expanded SPI | Type 3 UART | Type 4 UART | Type 4A Expanded UART | Type 5 H-Bridge | Type 6 Dual H-Bridge
1 2 3 4 | IO1 IO2 IO3 IO4 | In/Out In/Out In/Out In/Out | 1 2 3 4 | IOA1 IOA2 IOA3 IOA4 | In/Out In/Out In/Out In/Out | 1 2 3 4 | SS MOSI MISO SCK | Out Out | 1 2 | SS MOSI | Out Out | 1 2 | CTS RTS | Out | 1 | CTS | In | 1 | CTS | In | 1 DIR | Out | 1 DIR1 | Out
| | | | | | | | | | | | | | In | 2 | TXD | Out | 2 | TXD | Out | 2 EN | Out | 2 EN1 | Out
| | | | | | | | In | 3 | MISO | In | 3 | RXD | In | 3 | RXD | In | 3 | RXD | In | 3 SA | In | 3 DIR2 | Out
| | | | | | | | Out | 4 | SCK | Out | 4 | TXD | Out | 4 | RTS | Out | 4 | RTS | Out | 4 SB | In | 4 EN2 | Out
5 | GND | | 5 | GND | | 5 | GND | | 5 | GND | | 5 | GND | | 5 | GND | | 5 | GND | | 5 GND | | 5 GND
6 | VCC | | 6 | VCC | | 6 | VCC | | 6 | VCC | | 6 | VCC | | 6 | VCC | | 6 | VCC | | 6 VCC | | 6 VCC
| | | 7 8 9 10 | IOB1 IOB2 IOB3 IOB4 | In/Out In/Out In/Out In/Out | | | | 7 8 9 10 | INT RESET N/S N/S | In | | | | | | | 7 | INT | In
| | | | | | | | | | | Out | | | | | | | 8 | RESET | Out
| | | | | | | | | | | N/S N/S | | | | | | | 9 10 | N/S N/S | N/S N/S
| | | 11 | GND | | | | | 11 | GND | | | | | | | | 11 | GND
| | | 12 | VCC | | | | | 12 | VCC | | | | | | | | 12 | VCC
| | | | | | SS - Slave Select. Active low to enable slave device slave to master SCK - Serial clock. Data clock from master to slave | | | | | | CTS - Permission for peripheral to send data to host RTS - Request from peripheral to send data to host RXD - Data from peripheral to host | | | CTS - Device will only transmit when this signal is asserted RTS - Device is ready to receive data RXD - Data from peripheral to host TXD - Data from host to peripheral | | | CTS - Device will only transmit when this signal is asserted RTS - Device is ready to receive data RXD - Data from peripheral to host TXD - Data from host to peripheral INT - Interrupt signal from peripheral to host RESET - Reset signal for host to reset peripheral N/S - Not-specified depending on the module these pins may be unconnected or additional module specific inputs or outputs. | | | DIR - Motor direction EN - Motor enable, active high SA - feedback sense A SB - feedback sense B | | DIR1 - Motor/Phase 1 direction, active high MOSI - Master Out Slave In. Data from master to slave EN1 - Motor/Phase 1 enable MISO - Master In Slave Out. Data from DIR2 - Motor/Phase 2 direction, active high EN2 - Motor/Phase 2 enable
Pin | Signal | Direction | Pin | Signal | Direction | Pin | Signal | Direction | Pin | Signal | Direction | Pin | Signal | Direction | Pin | Signal | Direction | Pin | Signal | Direction | Pin | Signal | Direction | Pin | Signal | Direction

Pmod "High Speed" | XADC Pmod | Low Speed
Pin | Signal | LVDS Pair | Pin | Signal | LVDS Pair | Pin | Signal | LVDS Pair
1 | JA1_P | JA1 | 1 | JA1_P | JA1 | 1 | IO1 | NA
2 | JA1_N | | 2 | JA2_P | JA2 | 2 | IO2
3 | JA2_P | JA2 | 3 | JA3_P | JA3 | 3 | IO3
4 | JA2_N | | 4 | JA4_P | JA4 | 4 | IO4
5 | GND | | 5 | GND | | 5 | GND
6 | VCC | | 6 | VCC | | 6 | VCC
7 | JA3_P | JA3 | 7 | JA1_N | JA1 | 7 | IO1
| JA3_N | | 8 | JA2_N | JA2 | 8 | IO2 | NA 8
9 | JA4_P | JA4 | 9 | JA3_N | JA3 | 9 | IO3
10 | JA4_N | | 10 | JA4_N | JA4 | 10 | IO4
11 | GND | | 11 | GND | | 11 | GND
12 | VCC | | 12 | VCC | | 12 | VCC
* 0 Ohm series resistor * ESD protection | | | * No series resistor * ESD protection | | | * ~200 Ohm series resistor * Sometimes ESD protection
TMDS_33 input + output | ~XADC Pmod | | LVDS_25 input/output
LVDS_25 input | | Pin | Signal | LVDS Pair
1 | JA1_N | JA1
2 | JA2_N | JA2
3 | JA3_N | JA3
4 | JA4_N | JA4
5 | GND
6 | VCC
7 | JA1_P | JA1
8 | JA2_P | JA2
9 | JA3_P | JA3
10 | JA4_P | JA4
11 | GND
12 | VCC

Digilent Arty (https://reference.digilentinc.com/_media/arty:arty_sch.pdf) | Artix 7 | 100E
JA | Low Speed
| High Speed | Group 1 JB | No ESD?, JB1 - SRCC, JB2 - MRCC
JC | High Speed | | No ESD?
JD | Low Speed | | Uses mostly clock pins
Digilent Nexys Video (https://reference.digilentinc.com/_media/nexys-video:nexys_video_sch.pdf) | Artix 7 | GigE, HDMI In, HDMI Out, DP Out -- FMC(2 x HDMI In)
JA | Low Speed | Group 1
JB | High Speed | Group 2
JC | High Speed
JXADC XADC | | Group 3 | 100 Ohm Resistor
Digilent Nexys 4 DDR (https://reference.digilentinc.com/_media/nexys4-ddr:nexys_4_ddr_sch.pdf) | Artix 7
JA | Low Speed
JB | Low Speed
JC | Low Speed
JD | Low Speed
JXADC XADC
Digilent Genesys 2 (https://reference.digilentinc.com/_media/genesys2:genesys2_public_sch.pdf) | Kintex 7 | GigE, HDMI In, HDMI Out, DP In, DP Out, VGA Out -- FMC(2 x HDMI In)
JA | High Speed | Group 1
JB | High Speed
JC | Low Speed | Group 2
JD | Low Speed
JXADC XADC | | Group 3
Digilent Zybo (https://reference.digilentinc.com/_media/zybo:zybo_sch.pdf) | Zynq | GigE, HDMI BiDir, VGA Out
JA | XADC | Group 1
JB | High Speed
| High Speed | Group 2 JC
JD | High Speed | | JD3 - SRCC
JE | Low Speed
JF | Low Speed | Group 3 | MIO PMOD?
ZedBoard (https://reference.digilentinc.com/_media/reference/programmable-logic/zedboard/zedboard_sch.pdf) Zynq | | GigE, HDMI Out, VGA Out
JA1 | Low Speed | Group 1
JB1 | Low Speed

JC1 | High Speed | Group 2
JD1 | High Speed
JE1 | Low Speed | MIO PMOD?
Digilent PYNQ (https://reference.digilentinc.com/_media/reference/programmable-logic/pynq-z1/pynq-z1_sch.pdf) | Zynq | GigE, HDMI In, HDMI Out
PMODA | High Speed | Group 1 | 200 Ohm Resistor, JA3 - MRCC
PMODB | High Speed | | 200 Ohm Resistor
TOFE LowSpeedIO (https://github.com/timvideos/HDMI2USB-TOFE-LowSpeedIO/raw/master/docs/TOFE-LowSpeedIO-v1.0.0-4-g63ba16f.pdf) | | | Check Spacing
P2 | XADC | Group 1
P1 | XADC
P4 | Low Speed
P3 | Low Speed | Group 2
Numato Mimas V2 (https://docs.numato.com/wp-content/uploads/2016/08/MimasV2Sch.pdf) | Spartan 6 | | Check Spacing
P6 | ~XADC
P7 | ~XADC
P8 | ~XADC
P9 | ~XADC
Numato Waxwing (https://docs.numato.com/wp-content/uploads/2016/08/WaxwingBasicDevelopmentBoardSch.pdf) | Spartan 6 | | Check Spacing
P3 | XADC
P5 | XADC
P4 | XADC
MicroZed (http://zedboard.org/sites/default/files/documentations/MicroZed_Rev_F_Schematic_141212.pdf) | Zynq
J5 | | | MIO PMOD???

MyIRTech Z-turn with IO CapeZynq XADC?
PMOD1?
PMOD2?
PMOD3?
Pipistrello (http://www.saanlima.com/download/pipistrello-v2.0/pipistrello_v2_schematic.pdf) | Spartan 6
PMOD | Low Speed | | No resistors or ESD
icoBoard (http://downloads.amescon.com/icoboard.pdf) | Lattice??
P1 | Low Speed | | Check
P3 | Low Speed | | Check

P2 | Low Speed | Check
P4 | Low Speed | Check

| Numato | | | Numato | | | Numato | | | Numato | | | Numato | | | Digilent
HDMI Transmitter
Expansion Module

RTL8211E Gigabit Ethernet
Expansion Module | FT234 Expansion Module | VGA Display Expansion Module | Micro SD Expansion Module | Pmod SD: Full-sized SD Card Slot
http://numato.com/hdmi-transmitter-expansion-module/ http://numato.com/rtl8211e-gigabit-ethernet-expansion-module/ http://numato.com/ft234-expansion-module/ | http://numato.com/vga-display-expansion-module/ | http://numato.com/micro-sd-expansion-module/http://store.digilentinc.com/pmod-sd-full-sized-sd-card-slot/
2 x Dual PMOD | 3 x Dual PMOD | 1 x Dual PMOD | 2 x Dual PMOD | 1 x Dual PMOD | 1 x Dual PMOD
Module | ~XADC | P1 | Module | Low Speed | P1 | Module | Low Speed | P1 | Module | Low Speed | P1 | Module | Low Speed | P1 | Module | Low Speed | P1
PMod
Pin | Signal | Numato
| | Pin | PMod
| | | Pin | Signal | Numato
| | | | | Pin | PMod
| | | | | | Pin | Signal | Numato
| | | | | | | | Pin | PMod
| | | | | | | | | Pin | Signal | Numato
| | | | | | | | | | | Pin | PMod
| | | | | | | | | | | | Pin | Signal | Numato
| | | | | | | | | | | | | | Pin | PMod
| | | | | | | | | | | | | | | Pin | Signal | Direction
1 2 3 4 5 6 7 8 9 10 11 12 Module PMod Pin | TMDS-TX-2_P TMDS-TX-1_P TMDS-TX-0_P TMDS-TX-CLK_P GND VCC TMDS-TX-2_N TMDS-TX-1_N TMDS-TX-0_N TMDS-TX-CLK_N GND VCC Low Speed Signal | 2 4 6 8 10 12 1 3 5 7 9 11 P2 Numato Pin | 1 2 3 4 5 6 7 8 9 10 11 12 Module PMod Pin | NC ETH_RXCTL ETH_RXD1 ETH_RXD3 GND VCC NC ETH_RXD0 ETH_RXD2 ETH_INT_B GND VCC Low Speed Signal | 2 4 6 8 10 12 1 3 5 7 9 11 P2 Numato Pin | 1 2 3 4 5 6 7 8 9 10 11 12 | CBUS0 NC NC NC GND VCC TXD RTS RXD CTS GND VCC | 2 4 6 8 10 12 1 3 5 7 9 11 | 1 R1 2 2 G2 4 3 G1 6 4 B1 8 5 GND 10 6 VCC 12 7 R2 1 8 R0 3 9 G0 5 10 B0 7 11 GND 9 12 VCC 11 Module Low Speed P2 PMod Numato Pin Signal Pin | 1 DAT2 2 2 CMD 4 3 DAT0 6 4 NC 8 5 GND 10 6 VCC 12 7 DAT3 1 8 CLK 3 9 DAT1 5 10 NC 7 11 GND 9 12 VCC 11 | 1 SS Out 2 MOSI Out 3 MISO In 4 SCK Out 5 GND 6 VCC 7 DAT1 8 DAT2 9 CD 10 WP 11 GND 12 VCC
1 2 3 4 5 6 7 8 9 10 11 12 | TMDS-TX-SCL TMDS-TX-HOT NC NC GND VCC TMDS-TX-CEC TMDS-TX-SDA NC NC GND VCC | 2 4 6 8 10 12 1 3 5 7 9 11 | 1 2 3 4 5 6 7 8 9 10 11 12 Module PMod Pin | NC ETH_TXCLK ETH_TXD1 ETH_TXD3 GND VCC NC ETH_RXCLK ETH_TXD0 ETH_TXD2 GND VCC Low Speed Signal | 2 4 6 8 10 12 1 3 5 7 9 11 P3 Numato Pin | | | | 1 Vsync 2 2 NC 4 3 NC 6 4 NC 8 5 GND 10 6 VCC 12 7 Hsync 1 8 NC 3 9 NC 5 10 NC 7 11 GND 9 12 VCC 11
1 | ETH_RESET_B | 2
2 | ETH_MDIO | 4
3 | MAC_SDA | 6
4 | FPGA_CLK | 8
5 | GND | 10
6 | VCC | 12
7 | ETH_TXCTL | 1
8 | ETH_MDC | 3
9 | MAC_SCL | 5
10 | SYSCLK | 7
11 | GND | 9
12 | VCC | 11

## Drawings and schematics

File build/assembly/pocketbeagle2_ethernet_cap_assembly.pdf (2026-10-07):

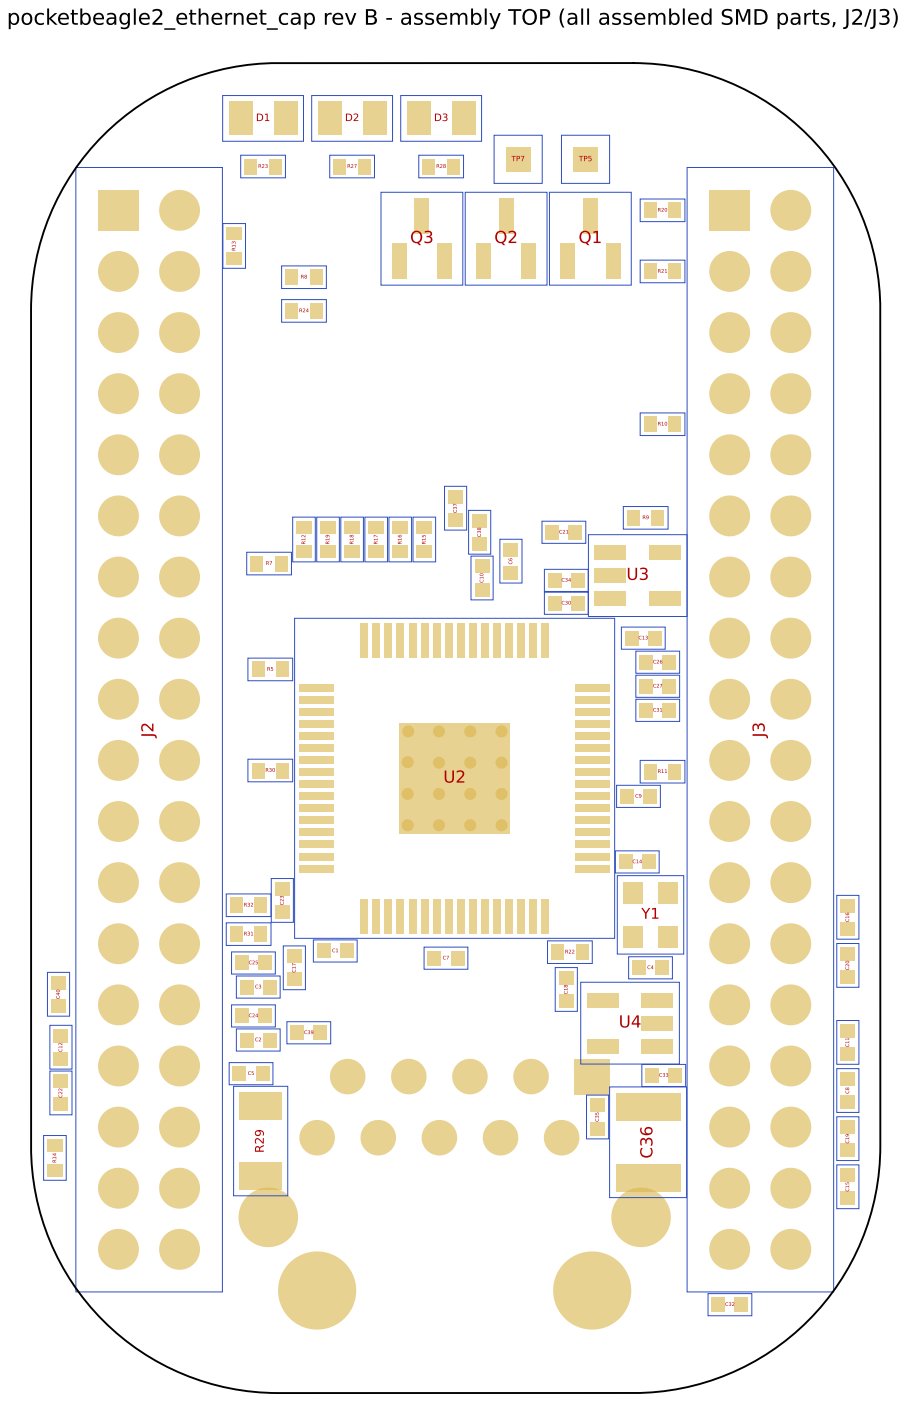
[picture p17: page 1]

pocketbeagle2_ethernet_cap rev B - assembly TOP (all assembled SMD parts, J2/J3)

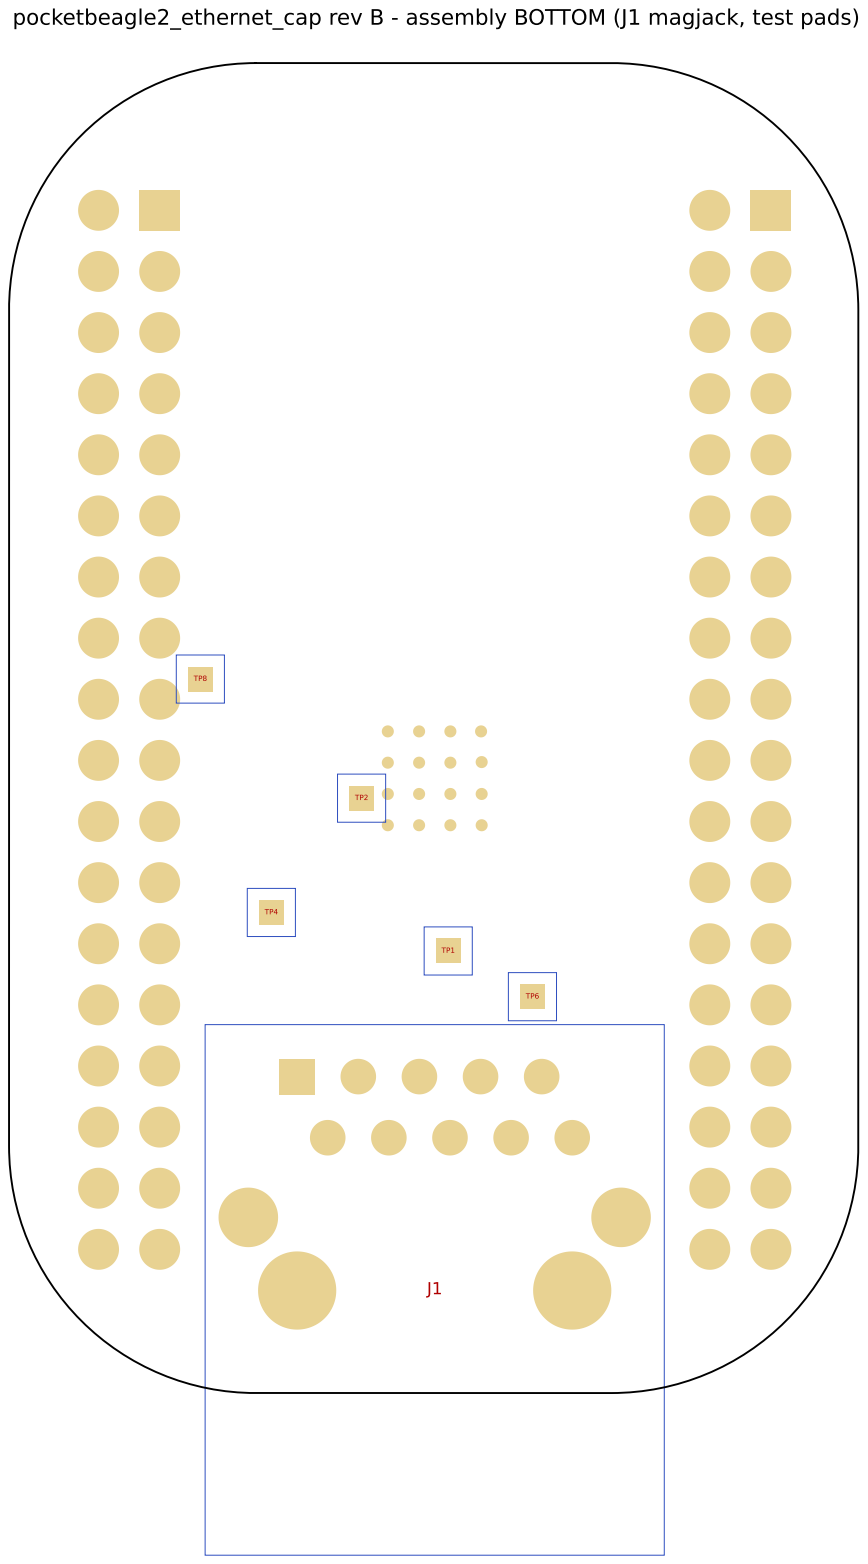
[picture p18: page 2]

pocketbeagle2_ethernet_cap rev B - assembly BOTTOM (J1 magjack, test pads)

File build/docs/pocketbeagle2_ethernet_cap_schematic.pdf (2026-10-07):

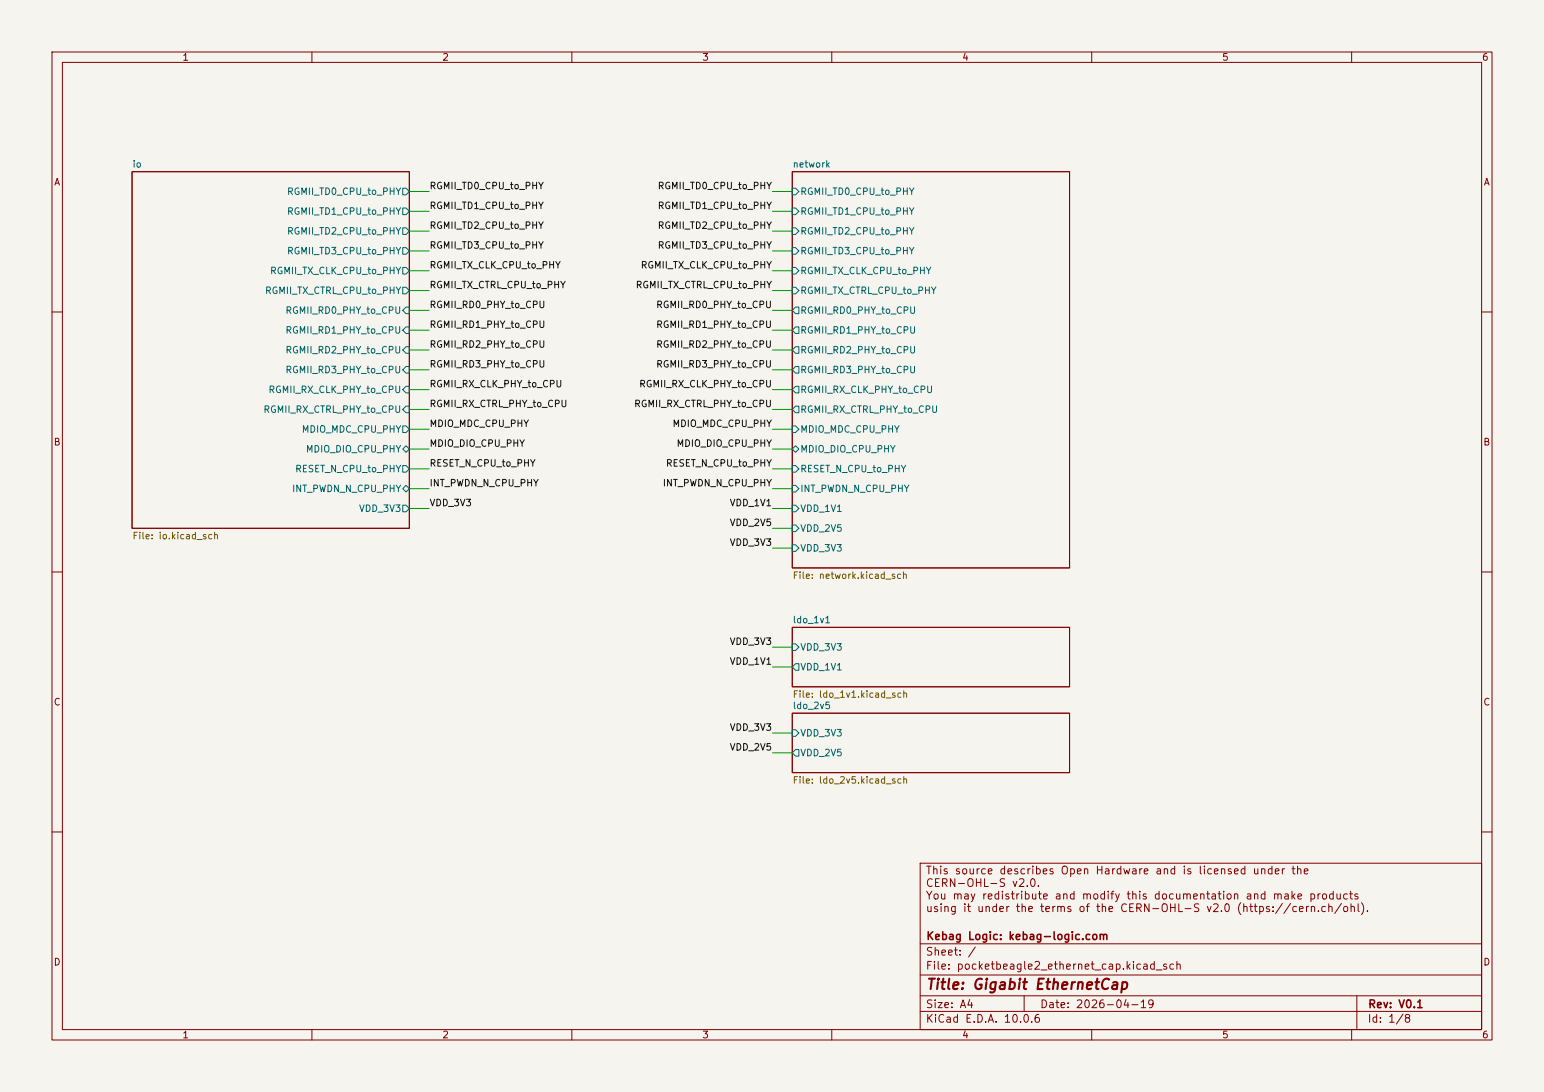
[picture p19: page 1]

This source describes Open Hardware and is licensed under the
CERN-OHL-S v2.0.
You may redistribute and modify this documentation and make products
using it under the terms of the CERN-OHL-S v2.0 (https://cern.ch/ohl).

Kebag Logic: kebag-logic.com
Sheet: /
File: pocketbeagle2_ethernet_cap.kicad_sch
Title: Gigabit EthernetCap

Size: A4 | Rev: V0.1
KiCad E.D.A. 10.0.6 | Id: 1/8

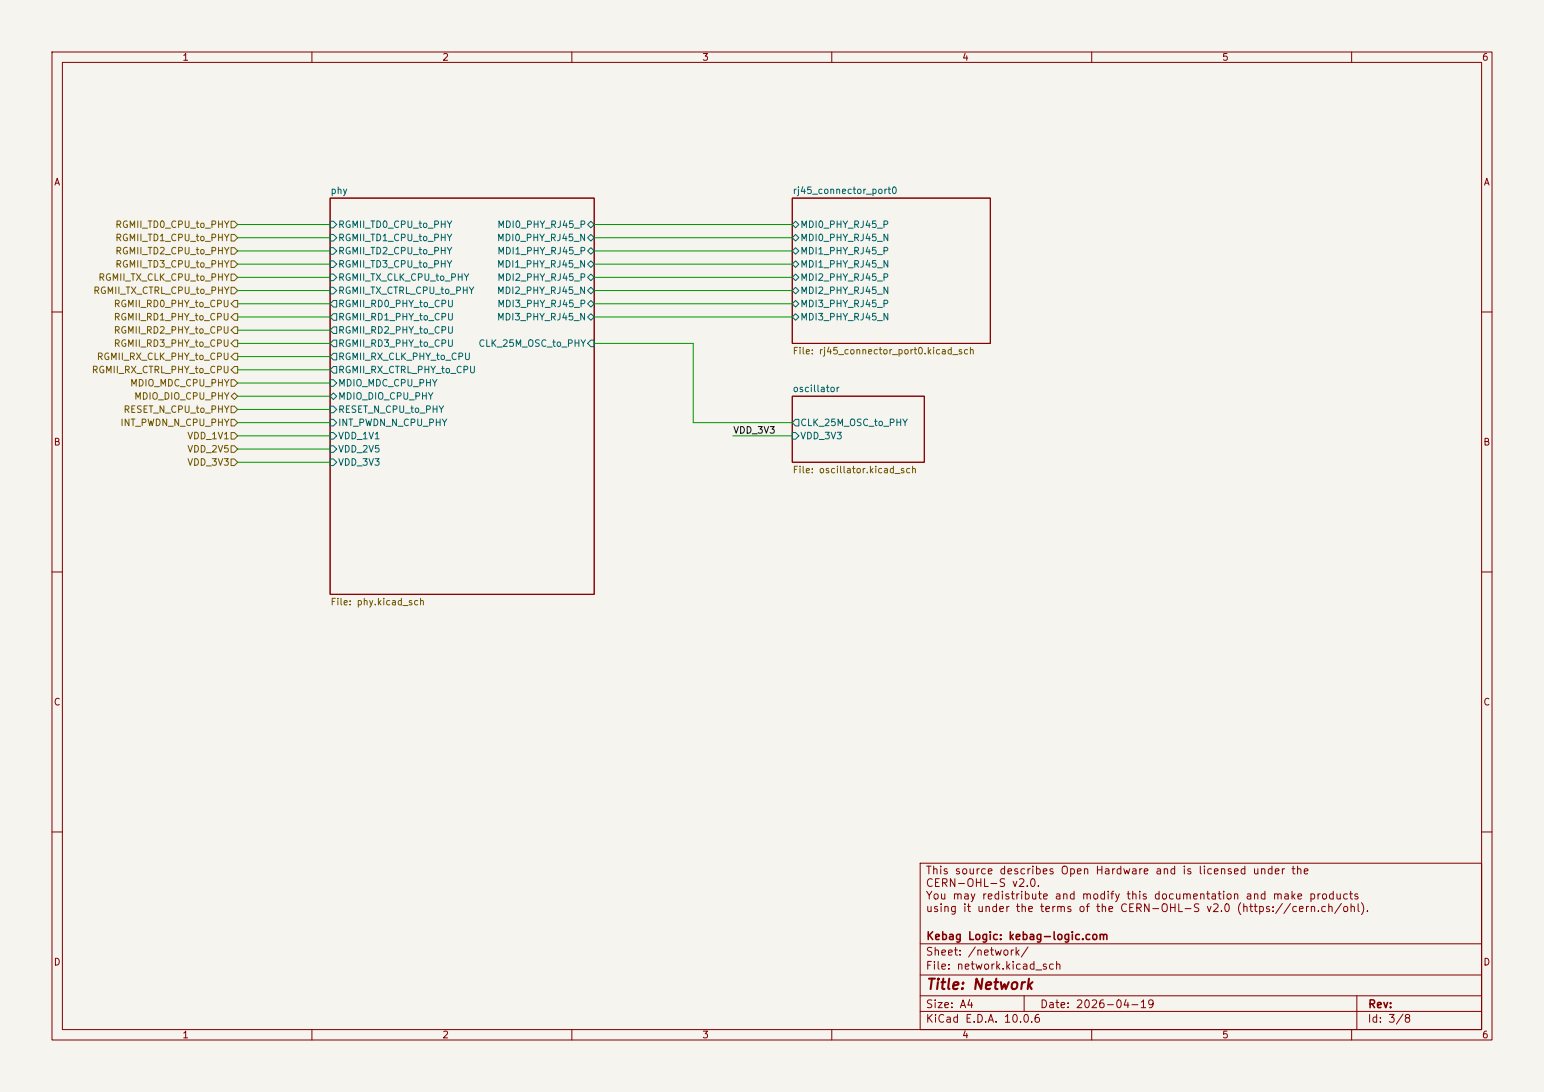
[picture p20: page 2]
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

Kebag Logic: kebag-logic.com
Sheet: /network/
File: network.kicad_sch
Title: Network

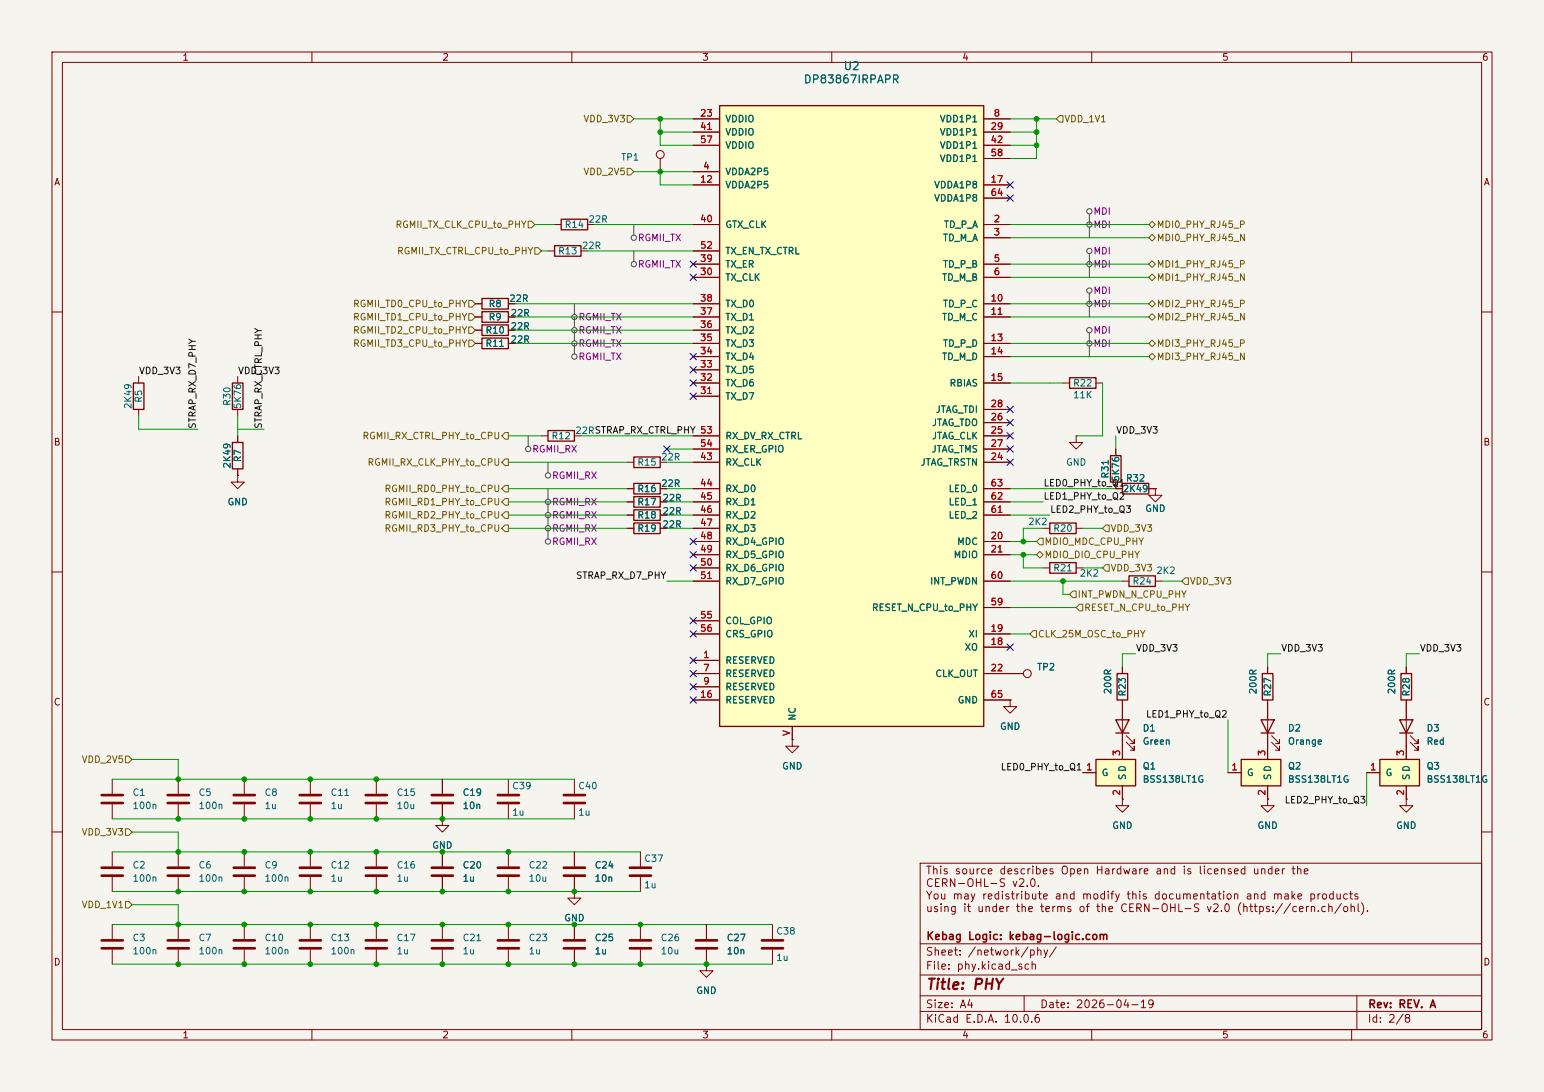
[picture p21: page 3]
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

Kebag Logic: kebag-logic.com
Sheet: /network/phy/
File: phy.kicad_sch
Title: PHY

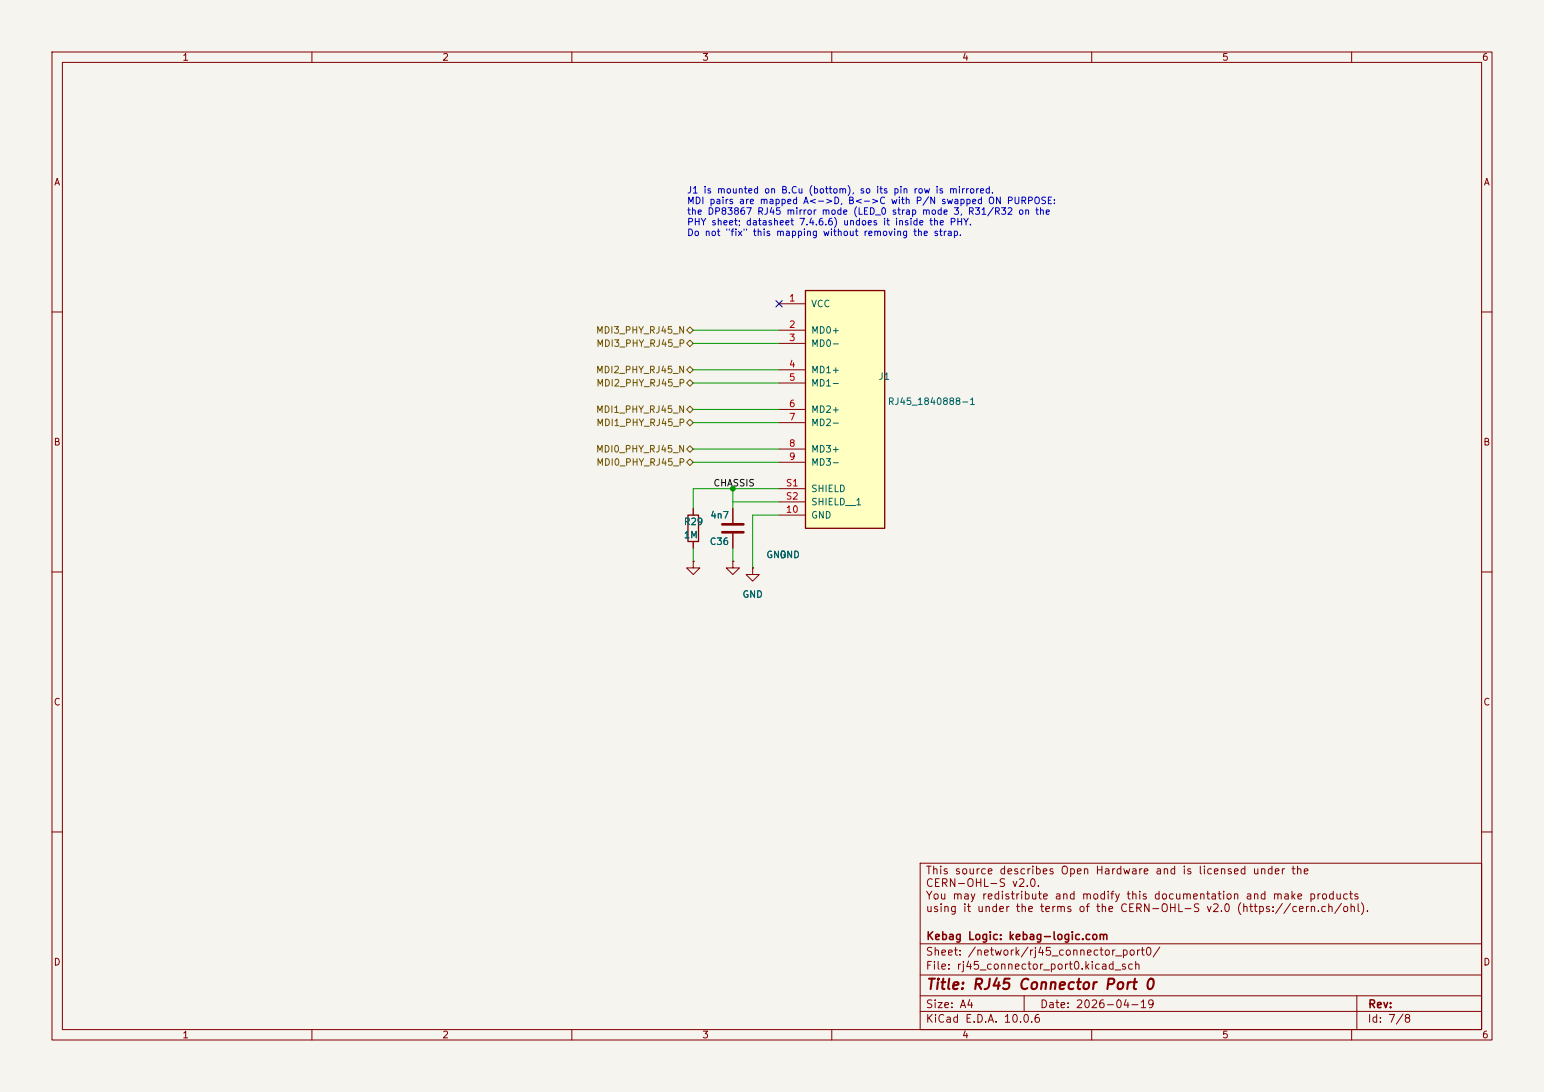
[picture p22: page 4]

J1 is mounted on B.Cu (bottom), so its pin row is mirrored. MDI pairs are mapped A<->D, B<->C with P/N swapped ON PURPOSE: the DP83867 RJ45 mirror mode (LED_0 strap mode 3, R31/R32 on the PHY sheet; datasheet 7.4.6.6) undoes it inside the PHY. Do not "fix" this mapping without removing the strap. R29

using it under the terms of the CERN-OHL-S v2.0 (https://cern.ch/ohl). GND

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

Kebag Logic: kebag-logic.com
Sheet: /network/rj45_connector_port0/
File: rj45_connector_port0.kicad_sch
Title: RJ45 Connector Port 0

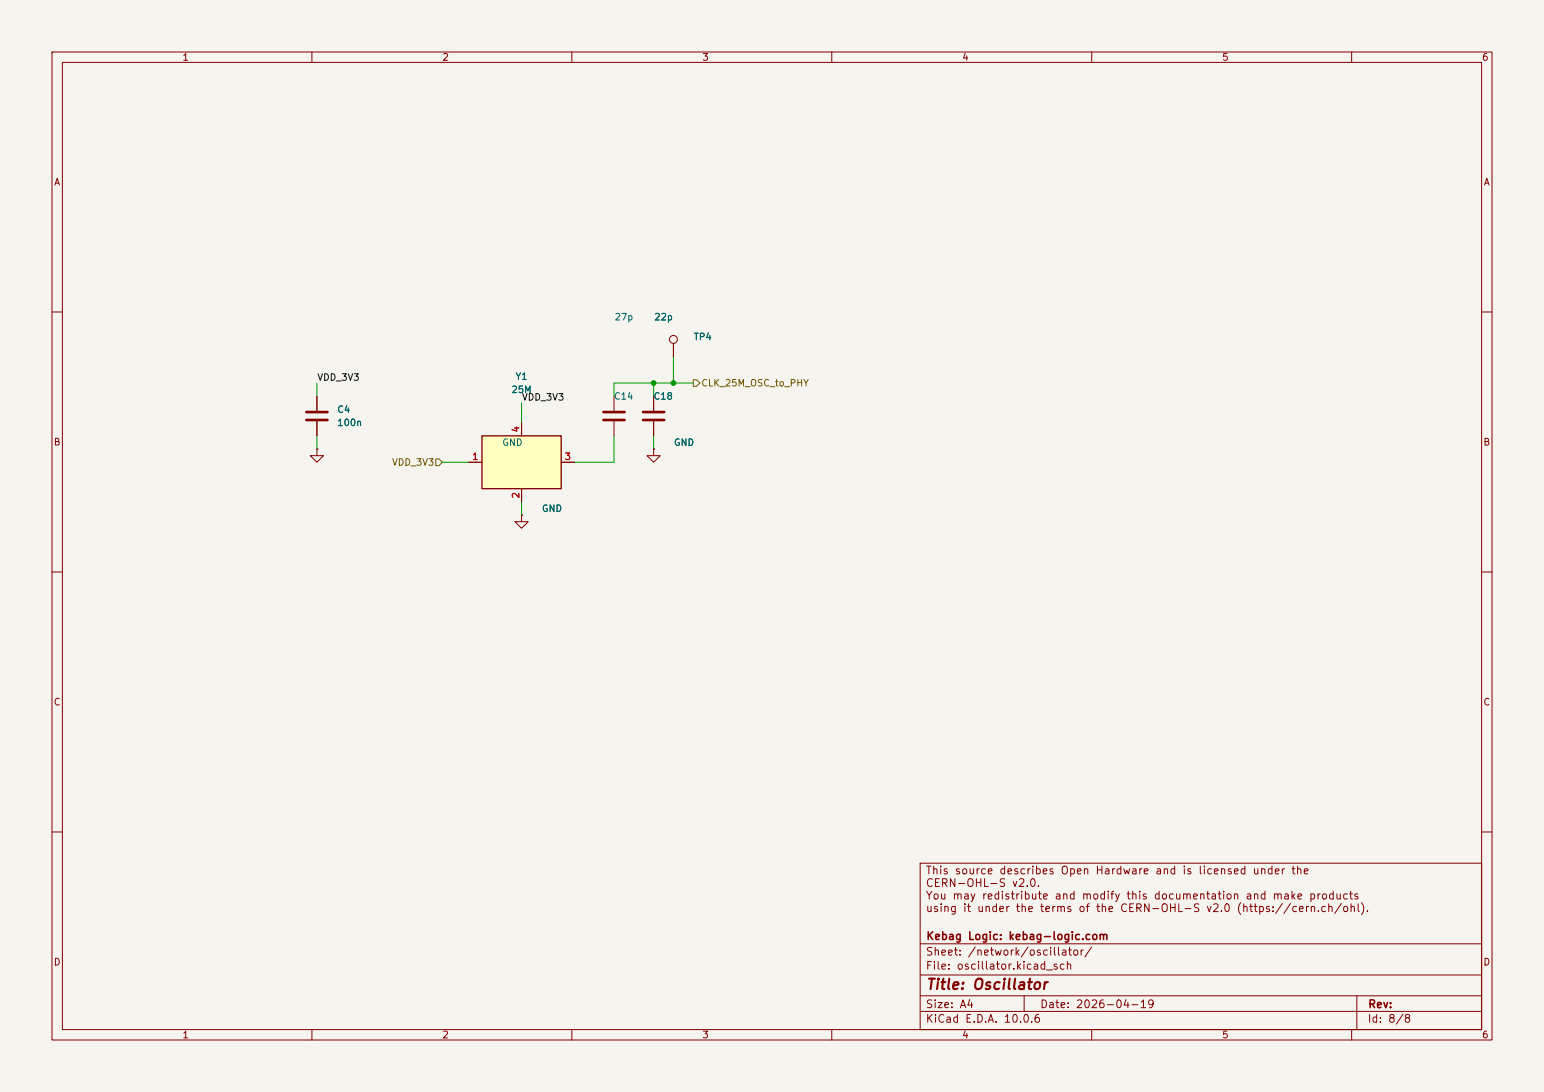
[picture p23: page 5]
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

Kebag Logic: kebag-logic.com
Sheet: /network/oscillator/
File: oscillator.kicad_sch
Title: Oscillator

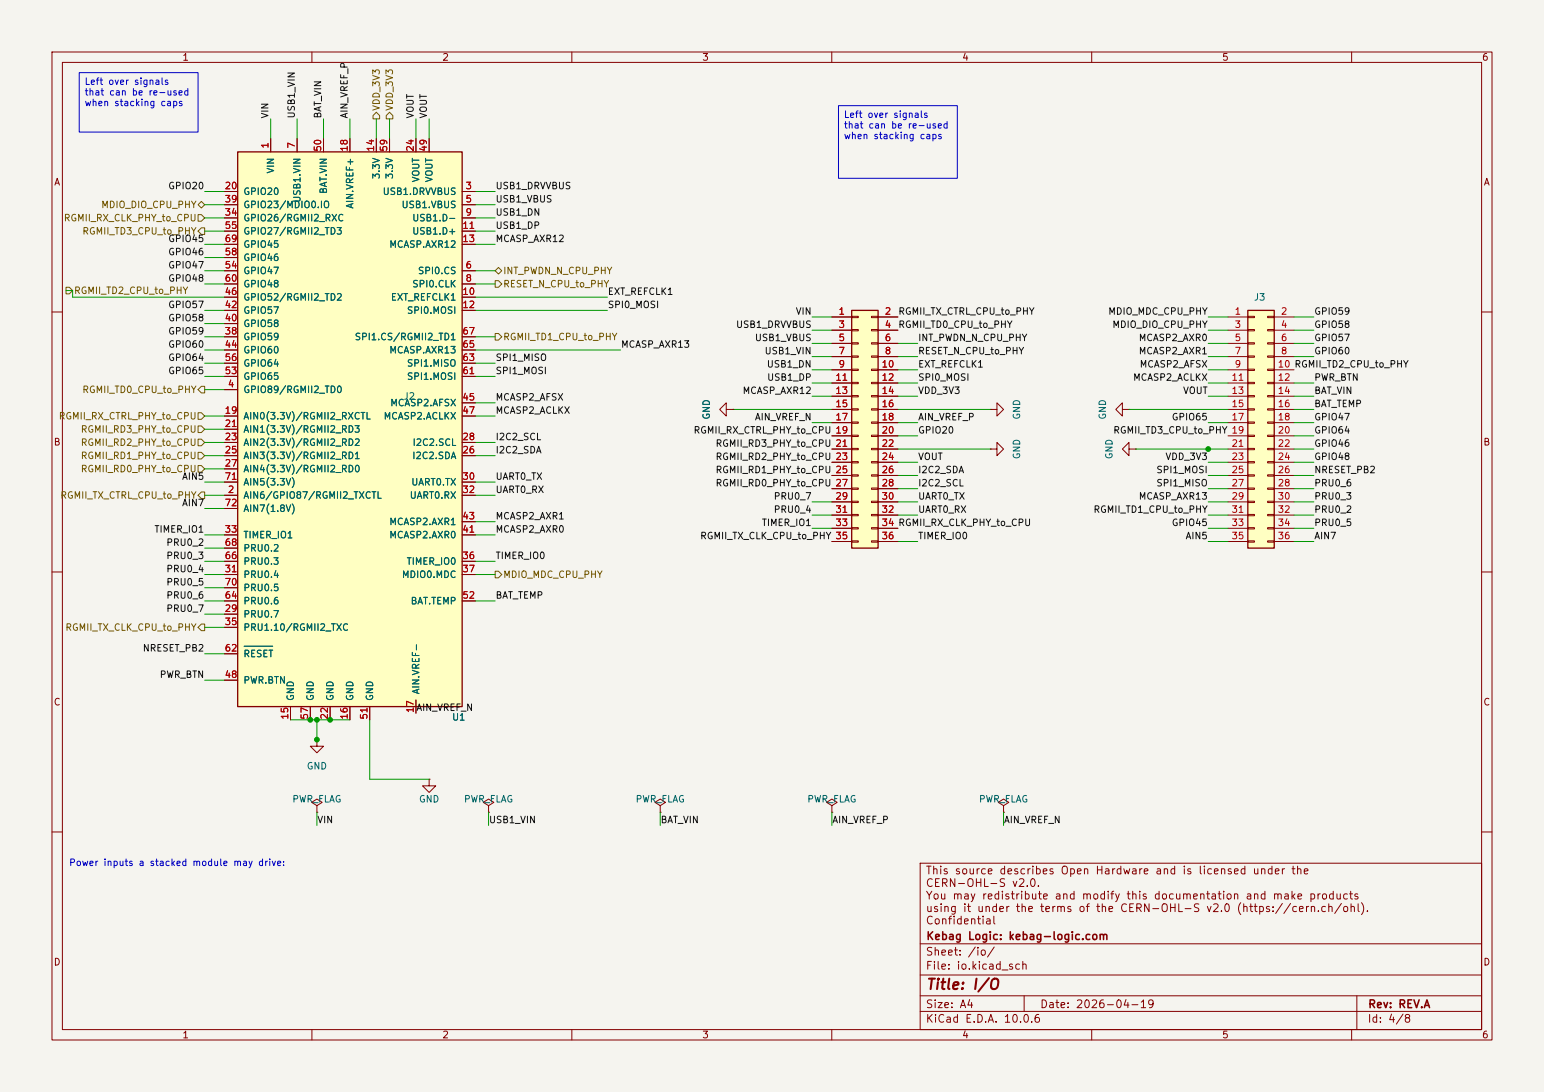
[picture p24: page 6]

Left over signals
that can be re-used when stacking caps

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

Confidential
Kebag Logic: kebag-logic.com
Sheet: /io/
File: io.kicad_sch
Title: I/O

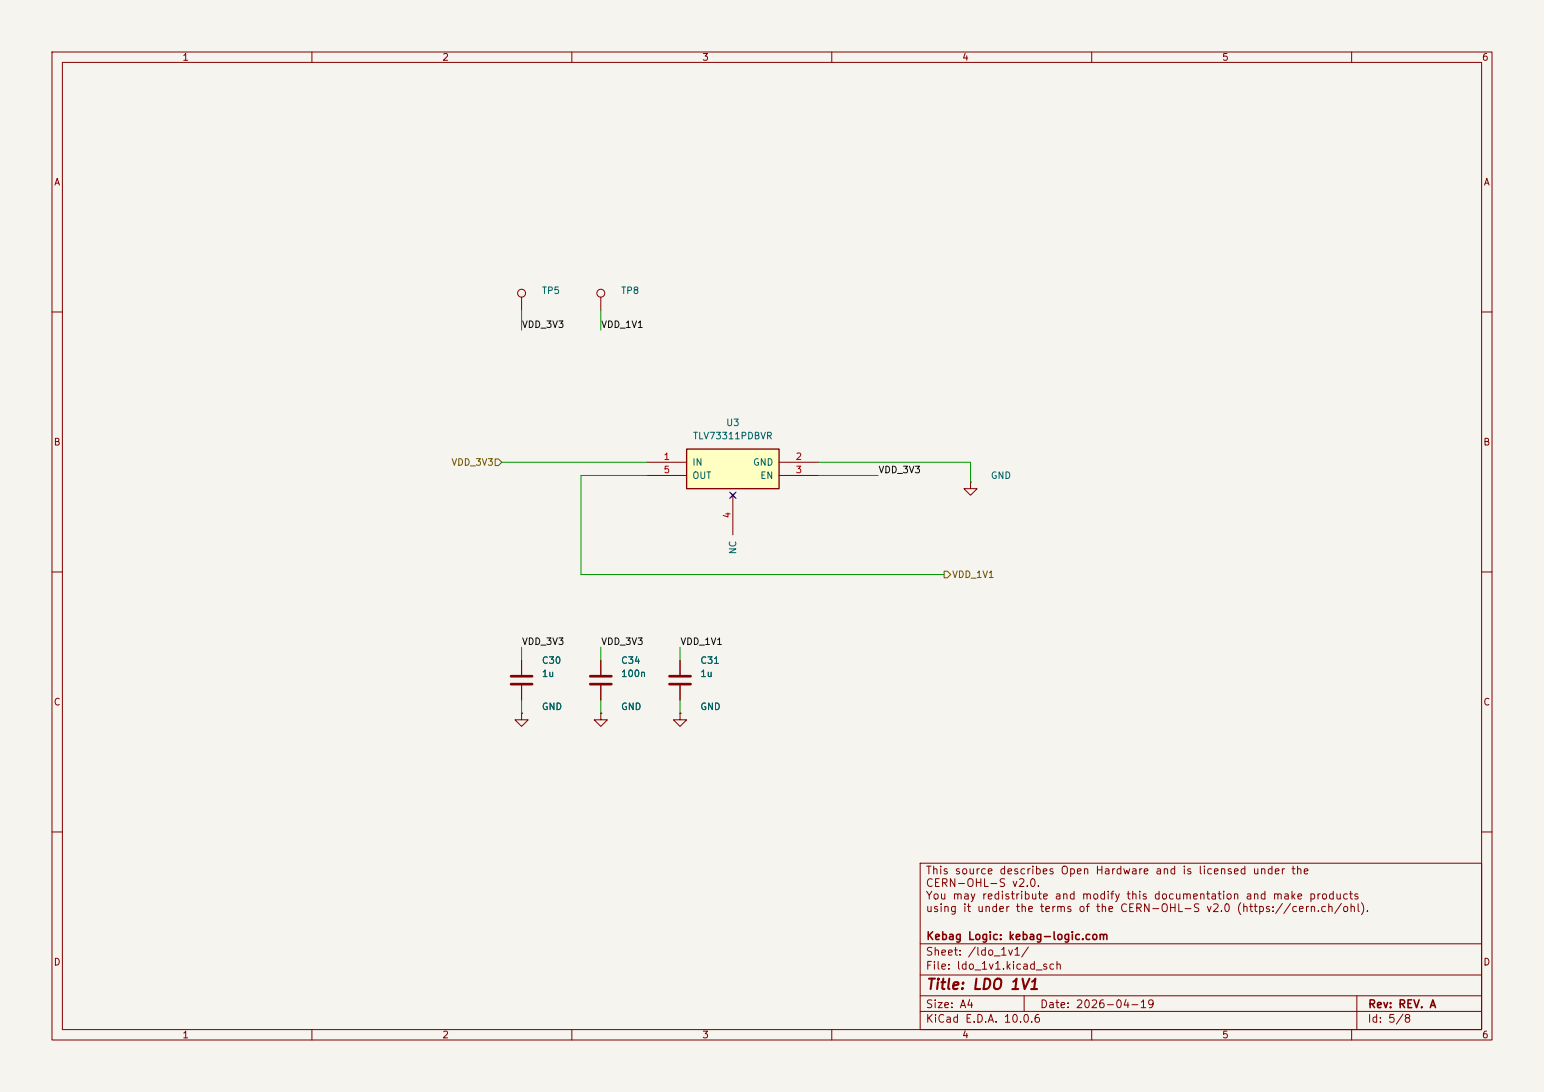
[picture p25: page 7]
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

Kebag Logic: kebag-logic.com
Sheet: /ldo_1v1/
File: ldo_1v1.kicad_sch
Title: LDO 1V1

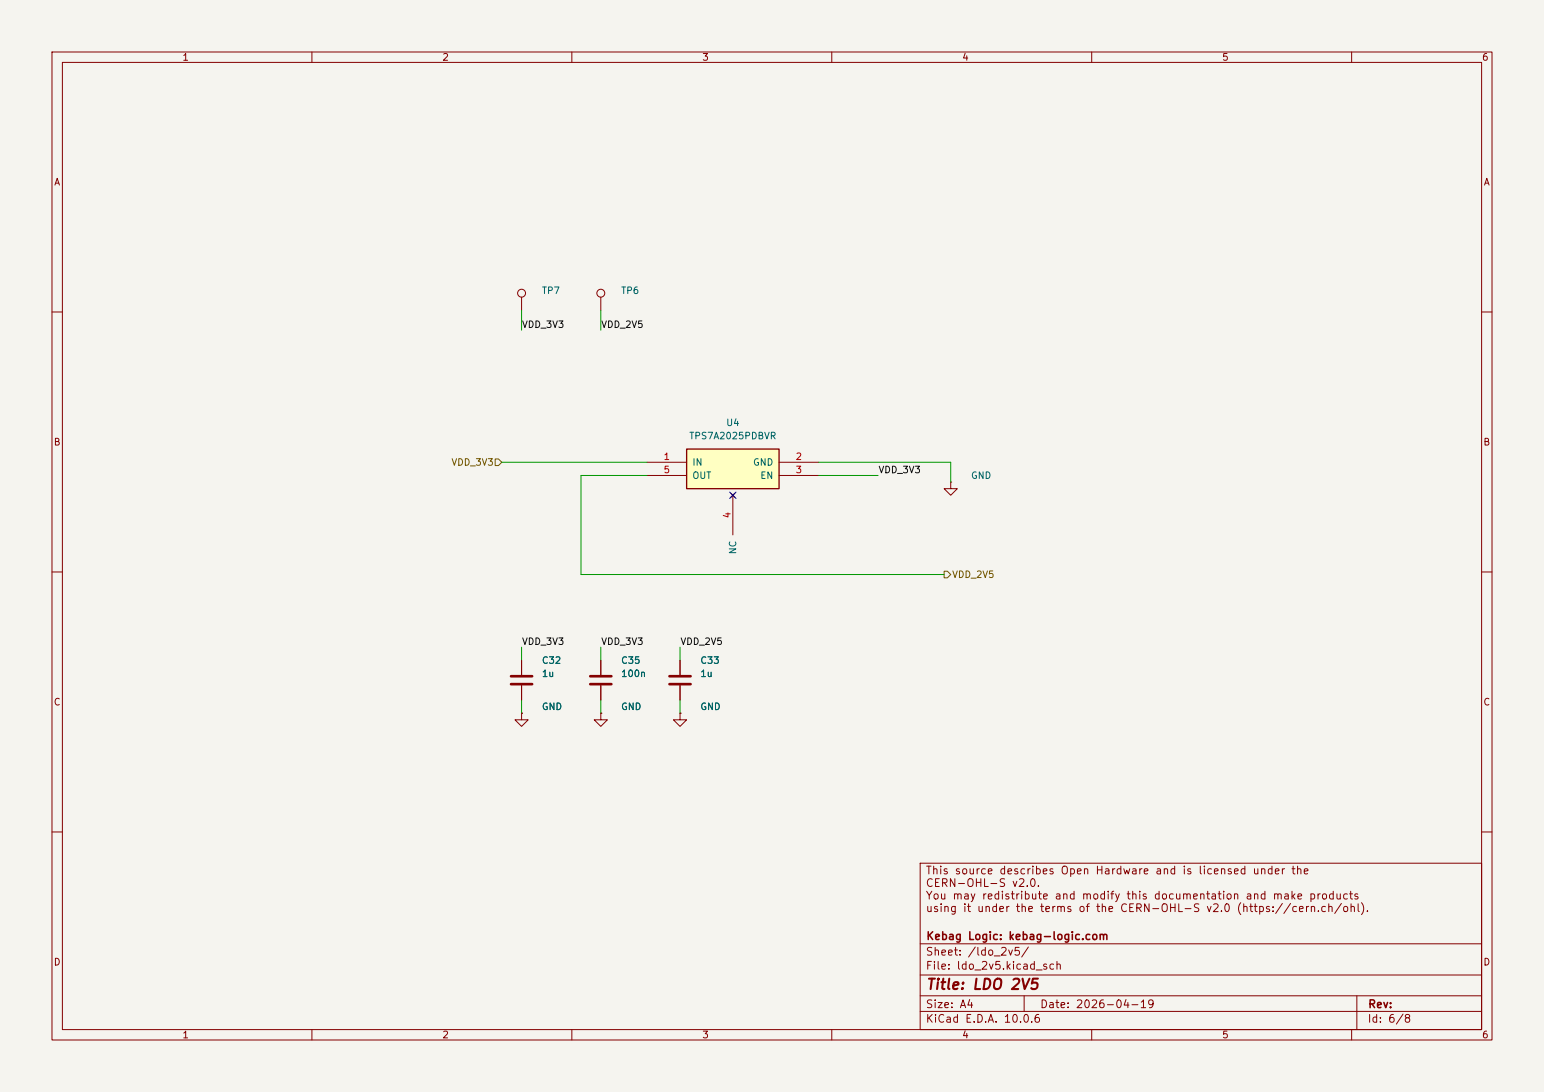
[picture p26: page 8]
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

Kebag Logic: kebag-logic.com
Sheet: /ldo_2v5/
File: ldo_2v5.kicad_sch
Title: LDO 2V5

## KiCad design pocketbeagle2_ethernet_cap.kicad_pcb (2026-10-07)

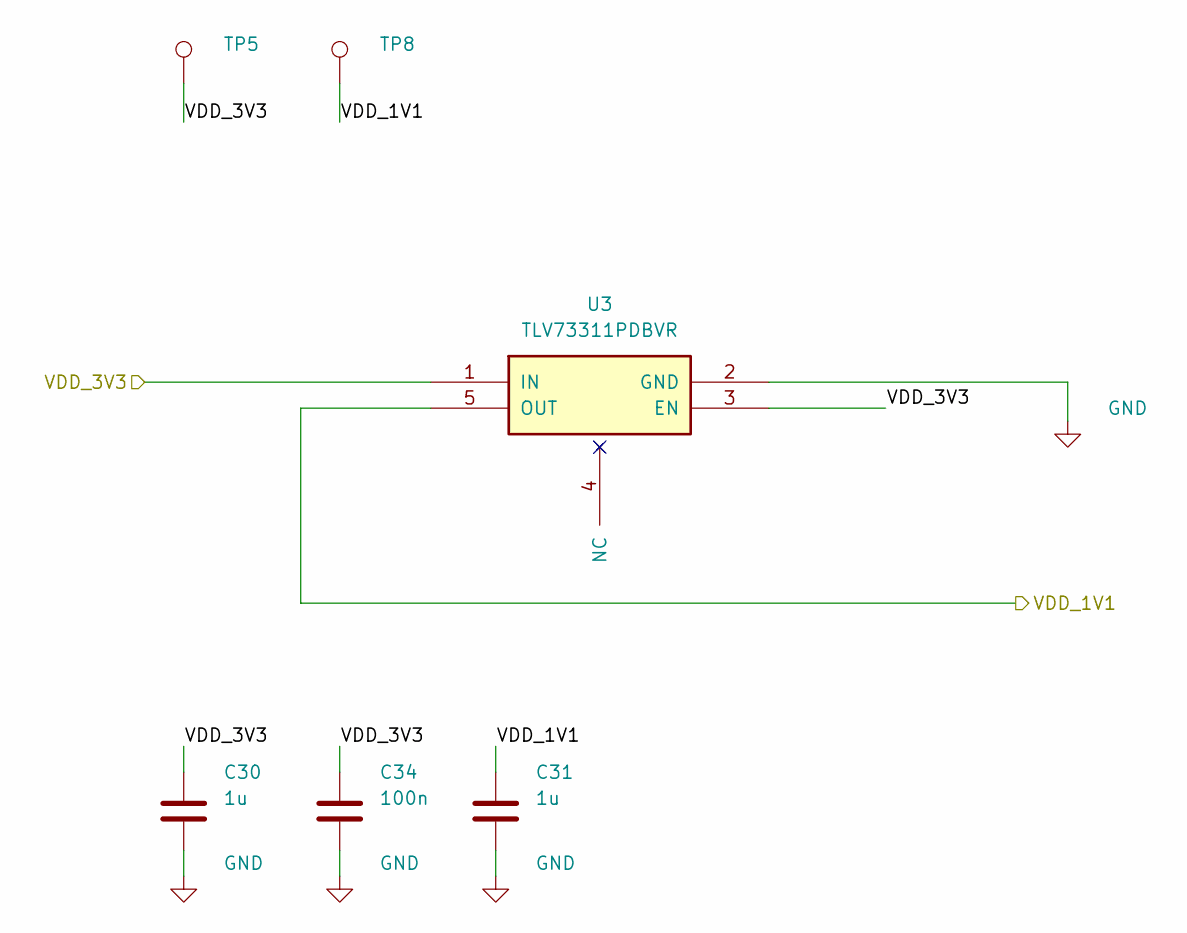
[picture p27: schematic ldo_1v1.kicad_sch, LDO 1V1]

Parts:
C30, C31: 1u; C_0402; Voltage_in_V 16; Tolerance_in_pct 10; MPN GRM155R61C105KA12D; Mouser 81-GRM155R61C105KA12D
C34: 100n; C_0402; Voltage_in_V 50; Tolerance_in_pct 10; MPN CL05B104KB54PNC; LCSC C307331
TP5, TP8: TestPoint_SMD; TestPoint_SMD_1.0x1.0mm
U3: TLV73311PDBVR; SOT-23-5; MPN TLV73311PDBVR; LCSC C2865431

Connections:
/VDD_1V1: C31.1, TP8.1, U3.5 (OUT); also elsewhere on the board
/VDD_3V3: C30.1, C34.1, TP5.1, U3.1 (IN), U3.3 (EN); also elsewhere on the board
GND: C30.2, C31.2, C34.2, U3.2 (GND); also elsewhere on the board

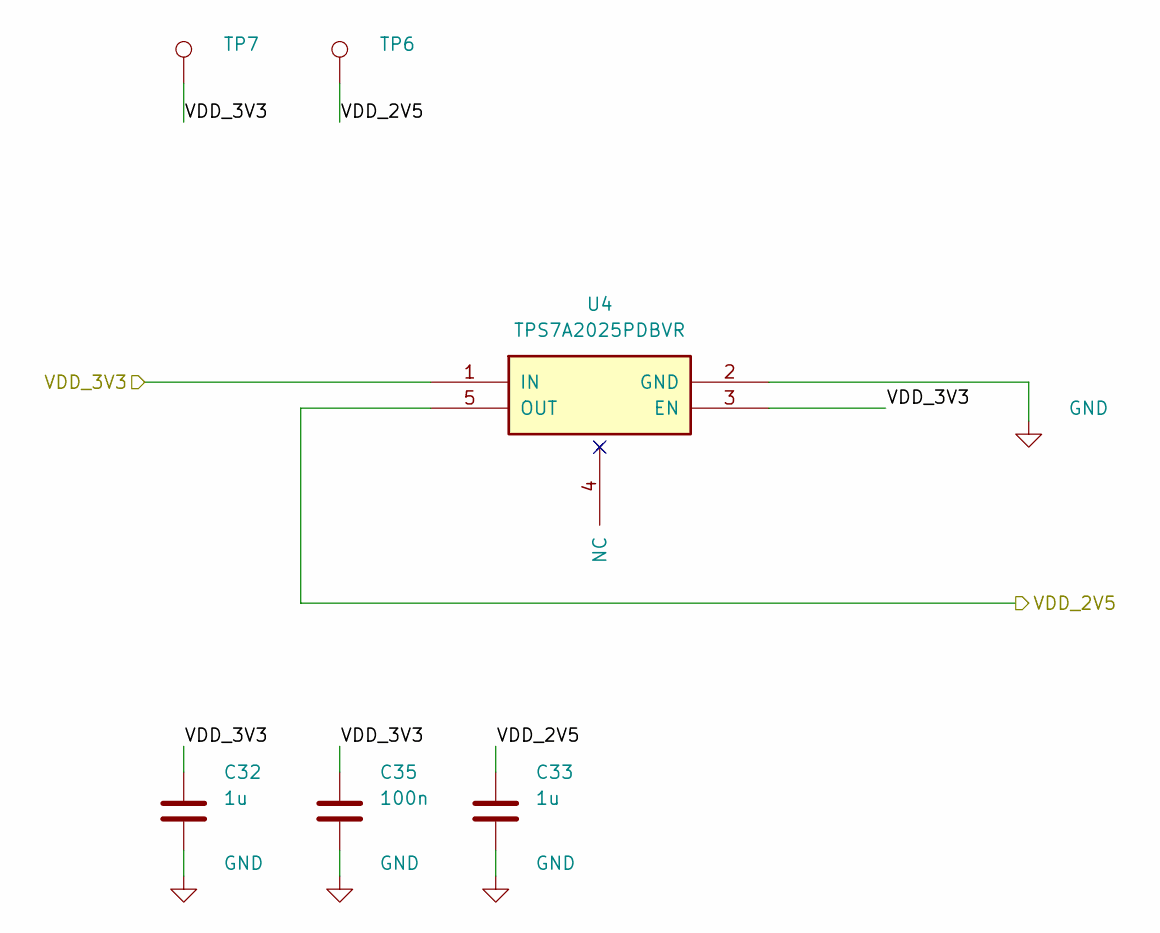
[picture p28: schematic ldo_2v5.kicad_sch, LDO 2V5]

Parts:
C32, C33: 1u; C_0402; Voltage_in_V 16; Tolerance_in_pct 10; MPN GRM155R61C105KA12D; Mouser 81-GRM155R61C105KA12D
C35: 100n; C_0402; Voltage_in_V 50; Tolerance_in_pct 10; MPN CL05B104KB54PNC; LCSC C307331
TP6, TP7: TestPoint_SMD; TestPoint_SMD_1.0x1.0mm
U4: TPS7A2025PDBVR; SOT-23-5; MPN TPS7A2025PDBVR; Mouser 595-TPS7A2025PDBVR

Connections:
/VDD_2V5: C33.1, TP6.1, U4.5 (OUT); also elsewhere on the board
/VDD_3V3: C32.1, C35.1, TP7.1, U4.1 (IN), U4.3 (EN); also elsewhere on the board
GND: C32.2, C33.2, C35.2, U4.2 (GND); also elsewhere on the board

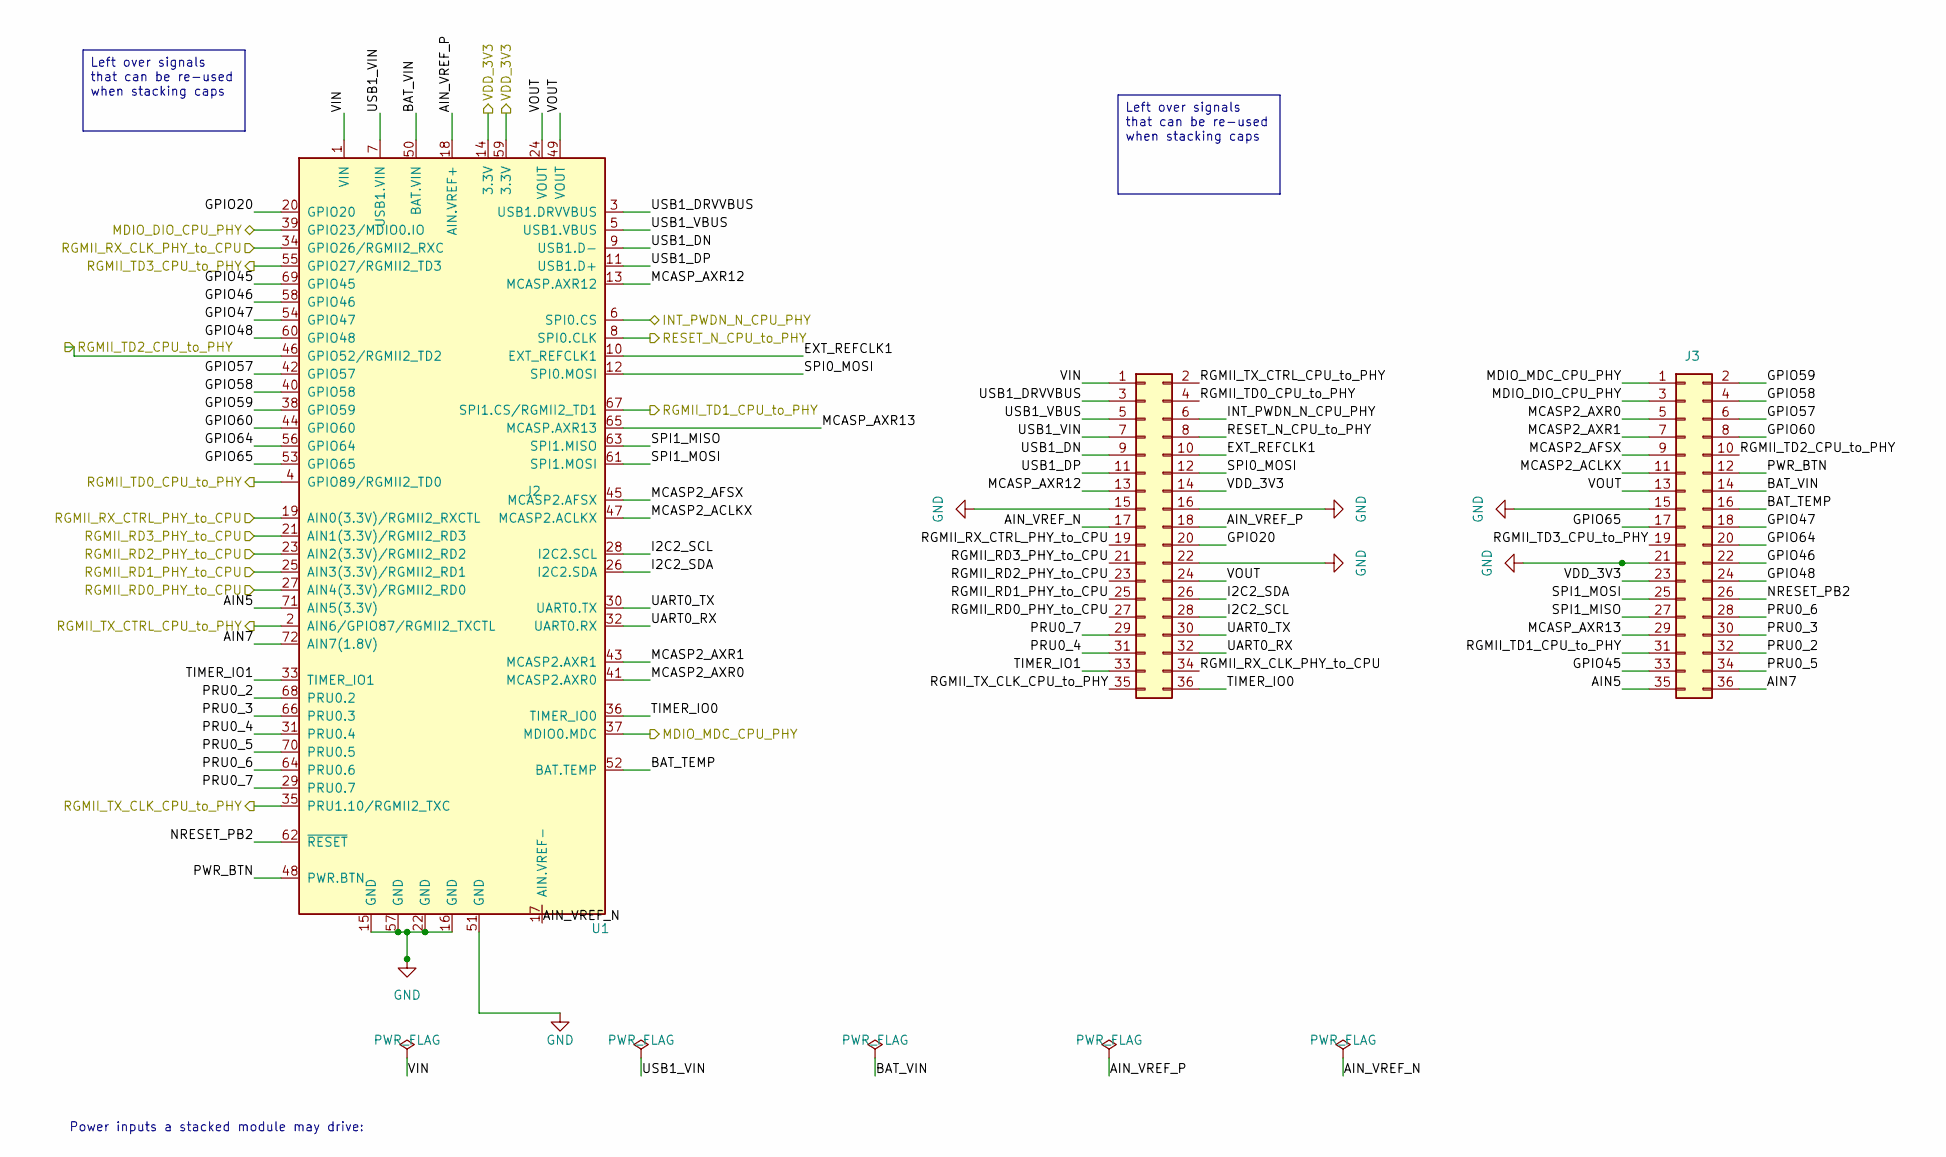
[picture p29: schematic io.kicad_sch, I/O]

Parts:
J2, J3: Header_18x02_2.54mm_2.54mm_Straight; 18x02_2.54mm_Header; MPN HC-PZ254-11.5L-2x18PZ; LCSC C41376109
U1: PocketBeagle2; BeagleBoard_PocketBeagle; MPN PocketBeagle 2; Mouser TBD

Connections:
/INT_PWDN_N_CPU_PHY: J2.6, U1.6 (SPI0.CS); also elsewhere on the board
/MDIO_DIO_CPU_PHY: J3.3, U1.39 (GPIO23/MDIO0.IO); also elsewhere on the board
/MDIO_MDC_CPU_PHY: J3.1, U1.37 (MDIO0.MDC); also elsewhere on the board
/RESET_N_CPU_to_PHY: J2.8, U1.8 (SPI0.CLK); also elsewhere on the board
/RGMII_RD0_PHY_to_CPU: J2.27, U1.27 (AIN4(3.3V)/RGMII2_RD0); also elsewhere on the board
/RGMII_RD1_PHY_to_CPU: J2.25, U1.25 (AIN3(3.3V)/RGMII2_RD1); also elsewhere on the board
/RGMII_RD2_PHY_to_CPU: J2.23, U1.23 (AIN2(3.3V)/RGMII2_RD2); also elsewhere on the board
/RGMII_RD3_PHY_to_CPU: J2.21, U1.21 (AIN1(3.3V)/RGMII2_RD3); also elsewhere on the board
/RGMII_RX_CLK_PHY_to_CPU: J2.34, U1.34 (GPIO26/RGMII2_RXC); also elsewhere on the board
/RGMII_RX_CTRL_PHY_to_CPU: J2.19, U1.19 (AIN0(3.3V)/RGMII2_RXCTL); also elsewhere on the board
/RGMII_TD0_CPU_to_PHY: J2.4, U1.4 (GPIO89/RGMII2_TD0); also elsewhere on the board
/RGMII_TD1_CPU_to_PHY: J3.31, U1.67 (SPI1.CS/RGMII2_TD1); also elsewhere on the board
/RGMII_TD2_CPU_to_PHY: J3.10, U1.46 (GPIO52/RGMII2_TD2); also elsewhere on the board
/RGMII_TD3_CPU_to_PHY: J3.19, U1.55 (GPIO27/RGMII2_TD3); also elsewhere on the board
/RGMII_TX_CLK_CPU_to_PHY: J2.35, U1.35 (PRU1.10/RGMII2_TXC); also elsewhere on the board
/RGMII_TX_CTRL_CPU_to_PHY: J2.2, U1.2 (AIN6/GPIO87/RGMII2_TXCTL); also elsewhere on the board
/VDD_3V3: J2.14, J3.23, U1.14 (3.3V), U1.59 (3.3V); also elsewhere on the board
/io/AIN5: J3.35, U1.71 (AIN5(3.3V))
/io/AIN7: J3.36, U1.72 (AIN7(1.8V))
/io/AIN_VREF_N: J2.17, U1.17 (AIN.VREF-)
/io/AIN_VREF_P: J2.18, U1.18 (AIN.VREF+)
/io/BAT_TEMP: J3.16, U1.52 (BAT.TEMP)
/io/BAT_VIN: J3.14, U1.50 (BAT.VIN)
/io/EXT_REFCLK1: J2.10, U1.10 (EXT_REFCLK1)
/io/GPIO20: J2.20, U1.20 (GPIO20)
/io/GPIO45: J3.33, U1.69 (GPIO45)
/io/GPIO46: J3.22, U1.58 (GPIO46)
/io/GPIO47: J3.18, U1.54 (GPIO47)
/io/GPIO48: J3.24, U1.60 (GPIO48)
/io/GPIO57: J3.6, U1.42 (GPIO57)
/io/GPIO58: J3.4, U1.40 (GPIO58)
/io/GPIO59: J3.2, U1.38 (GPIO59)
/io/GPIO60: J3.8, U1.44 (GPIO60)
/io/GPIO64: J3.20, U1.56 (GPIO64)
/io/GPIO65: J3.17, U1.53 (GPIO65)
/io/I2C2_SCL: J2.28, U1.28 (I2C2.SCL)
/io/I2C2_SDA: J2.26, U1.26 (I2C2.SDA)
/io/MCASP2_ACLKX: J3.11, U1.47 (MCASP2.ACLKX)
/io/MCASP2_AFSX: J3.9, U1.45 (MCASP2.AFSX)
/io/MCASP2_AXR0: J3.5, U1.41 (MCASP2.AXR0)
/io/MCASP2_AXR1: J3.7, U1.43 (MCASP2.AXR1)
/io/MCASP_AXR12: J2.13, U1.13 (MCASP.AXR12)
/io/MCASP_AXR13: J3.29, U1.65 (MCASP.AXR13)
/io/NRESET_PB2: J3.26, U1.62 (~RESET)
/io/PRU0_2: J3.32, U1.68 (PRU0.2)
/io/PRU0_3: J3.30, U1.66 (PRU0.3)
/io/PRU0_4: J2.31, U1.31 (PRU0.4)
/io/PRU0_5: J3.34, U1.70 (PRU0.5)
/io/PRU0_6: J3.28, U1.64 (PRU0.6)
/io/PRU0_7: J2.29, U1.29 (PRU0.7)
/io/PWR_BTN: J3.12, U1.48 (PWR.BTN)
/io/SPI0_MOSI: J2.12, U1.12 (SPI0.MOSI)
/io/SPI1_MISO: J3.27, U1.63 (SPI1.MISO)
/io/SPI1_MOSI: J3.25, U1.61 (SPI1.MOSI)
/io/TIMER_IO0: J2.36, U1.36 (TIMER_IO0)
/io/TIMER_IO1: J2.33, U1.33 (TIMER_IO1)
/io/UART0_RX: J2.32, U1.32 (UART0.RX)
/io/UART0_TX: J2.30, U1.30 (UART0.TX)
/io/USB1_DN: J2.9, U1.9 (USB1.D-)
/io/USB1_DP: J2.11, U1.11 (USB1.D+)
/io/USB1_DRVVBUS: J2.3, U1.3 (USB1.DRVVBUS)
/io/USB1_VBUS: J2.5, U1.5 (USB1.VBUS)
/io/USB1_VIN: J2.7, U1.7 (USB1.VIN)
/io/VIN: J2.1, U1.1 (VIN)
/io/VOUT: J2.24, J3.13, U1.24 (VOUT), U1.49 (VOUT)
GND: J2.15, J2.16, J2.22, J3.15, J3.21, U1.15 (GND), U1.16 (GND), U1.22 (GND), U1.51 (GND), U1.57 (GND); also elsewhere on the board

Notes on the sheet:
Power inputs a stacked module may drive:
Left over signals that can be re-used when stacking caps

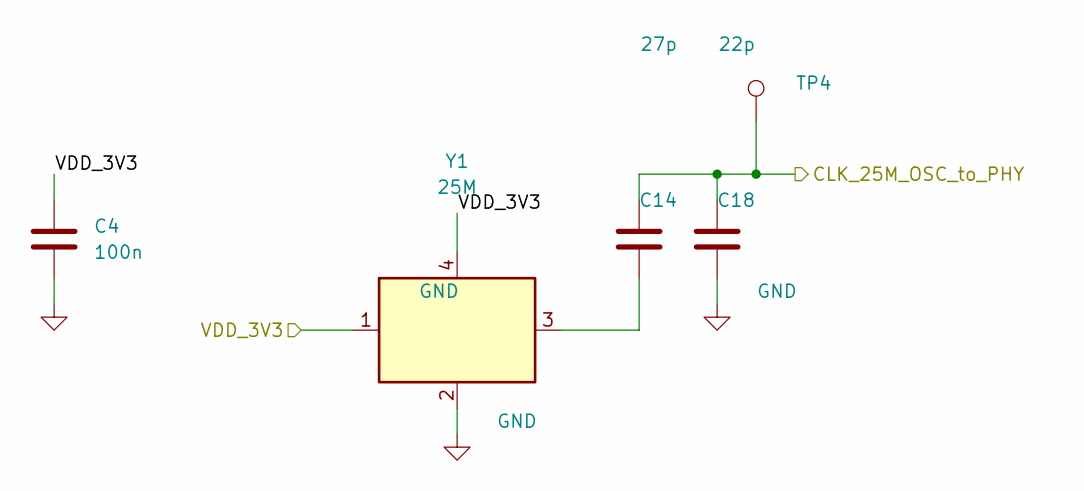
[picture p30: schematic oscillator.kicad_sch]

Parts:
C4: 100n; C_0402; Voltage_in_V 50; Tolerance_in_pct 10; MPN CL05B104KB54PNC; LCSC C307331
C14: 27p; C_0402; Voltage_in_V 50; Tolerance_in_pct 5; MPN 0402CG270J500NT; LCSC C1557
C18: 22p; C_0402; Voltage_in_V 50; Tolerance_in_pct 5; MPN GRM1555C1H220JA01D; Mouser 81-GRM1555C1H220JA01D
TP4: TestPoint_SMD; TestPoint_SMD_1.0x1.0mm
Y1: 25M; ECS-2520MV; Voltage_in_V 1.6-3.6; MPN ECS-2520MV-250-CN-TR; Mouser TBD

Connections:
/VDD_3V3: C4.1, Y1.1 (Tri-State), Y1.4 (VDD); also elsewhere on the board
/network/oscillator/CLK_25M_OSC_to_PHY: C14.2, C18.2, TP4.1; also elsewhere on the board
GND: C4.2, C18.1, Y1.2 (GND); also elsewhere on the board
unnamed: C14.1, Y1.3 (OUT)

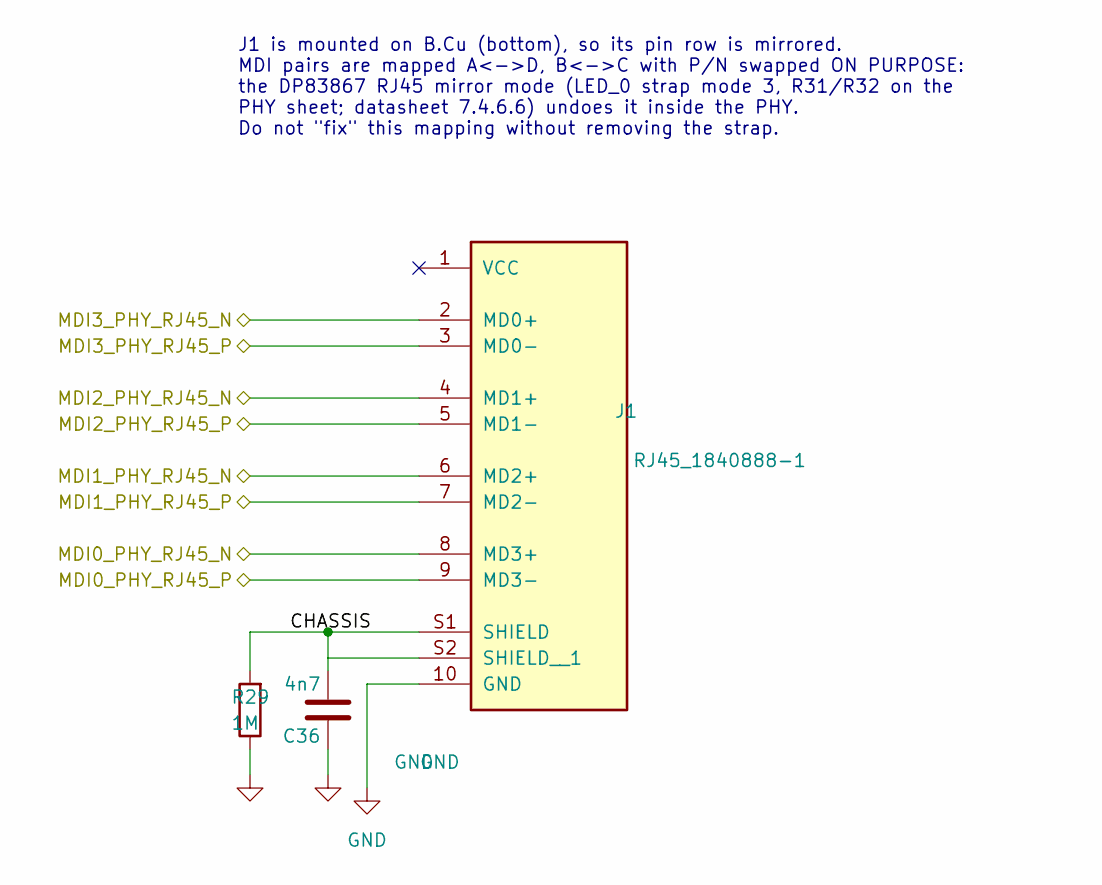
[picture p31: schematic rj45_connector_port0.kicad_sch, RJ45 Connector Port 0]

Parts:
C36: 4n7; C_1210; Tolerance_in_pct 10; Voltage_in_V 2000; MPN C1210C472KGRACTU; LCSC C2167834
J1: RJ45_1840888-1; BEL_1840888-1; PARTREV 5; Mouser TBD
R29: 1M; R_1206; Tolerance_in_pct 1; MPN CRCW12061M00FKEA; LCSC C844869

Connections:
/network/phy/MDI0_PHY_RJ45_N: J1.8 (MD3+); also elsewhere on the board
/network/phy/MDI0_PHY_RJ45_P: J1.9 (MD3-); also elsewhere on the board
/network/phy/MDI1_PHY_RJ45_N: J1.6 (MD2+); also elsewhere on the board
/network/phy/MDI1_PHY_RJ45_P: J1.7 (MD2-); also elsewhere on the board
/network/phy/MDI2_PHY_RJ45_N: J1.4 (MD1+); also elsewhere on the board
/network/phy/MDI2_PHY_RJ45_P: J1.5 (MD1-); also elsewhere on the board
/network/phy/MDI3_PHY_RJ45_N: J1.2 (MD0+); also elsewhere on the board
/network/phy/MDI3_PHY_RJ45_P: J1.3 (MD0-); also elsewhere on the board
/network/rj45_connector_port0/CHASSIS: C36.2, J1.S1 (SHIELD), J1.S2 (SHIELD__1), R29.2
GND: C36.1, J1.10 (GND), R29.1; also elsewhere on the board

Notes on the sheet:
J1 is mounted on B.Cu (bottom), so its pin row is mirrored. MDI pairs are mapped A<->D, B<->C with P/N swapped ON PURPOSE: the DP83867 RJ45 mirror mode (LED_0 strap mode 3, R31/R32 on the PHY sheet; datasheet 7.4.6.6) undoes it inside the PHY. Do not "fix" this mapping without removing the strap.

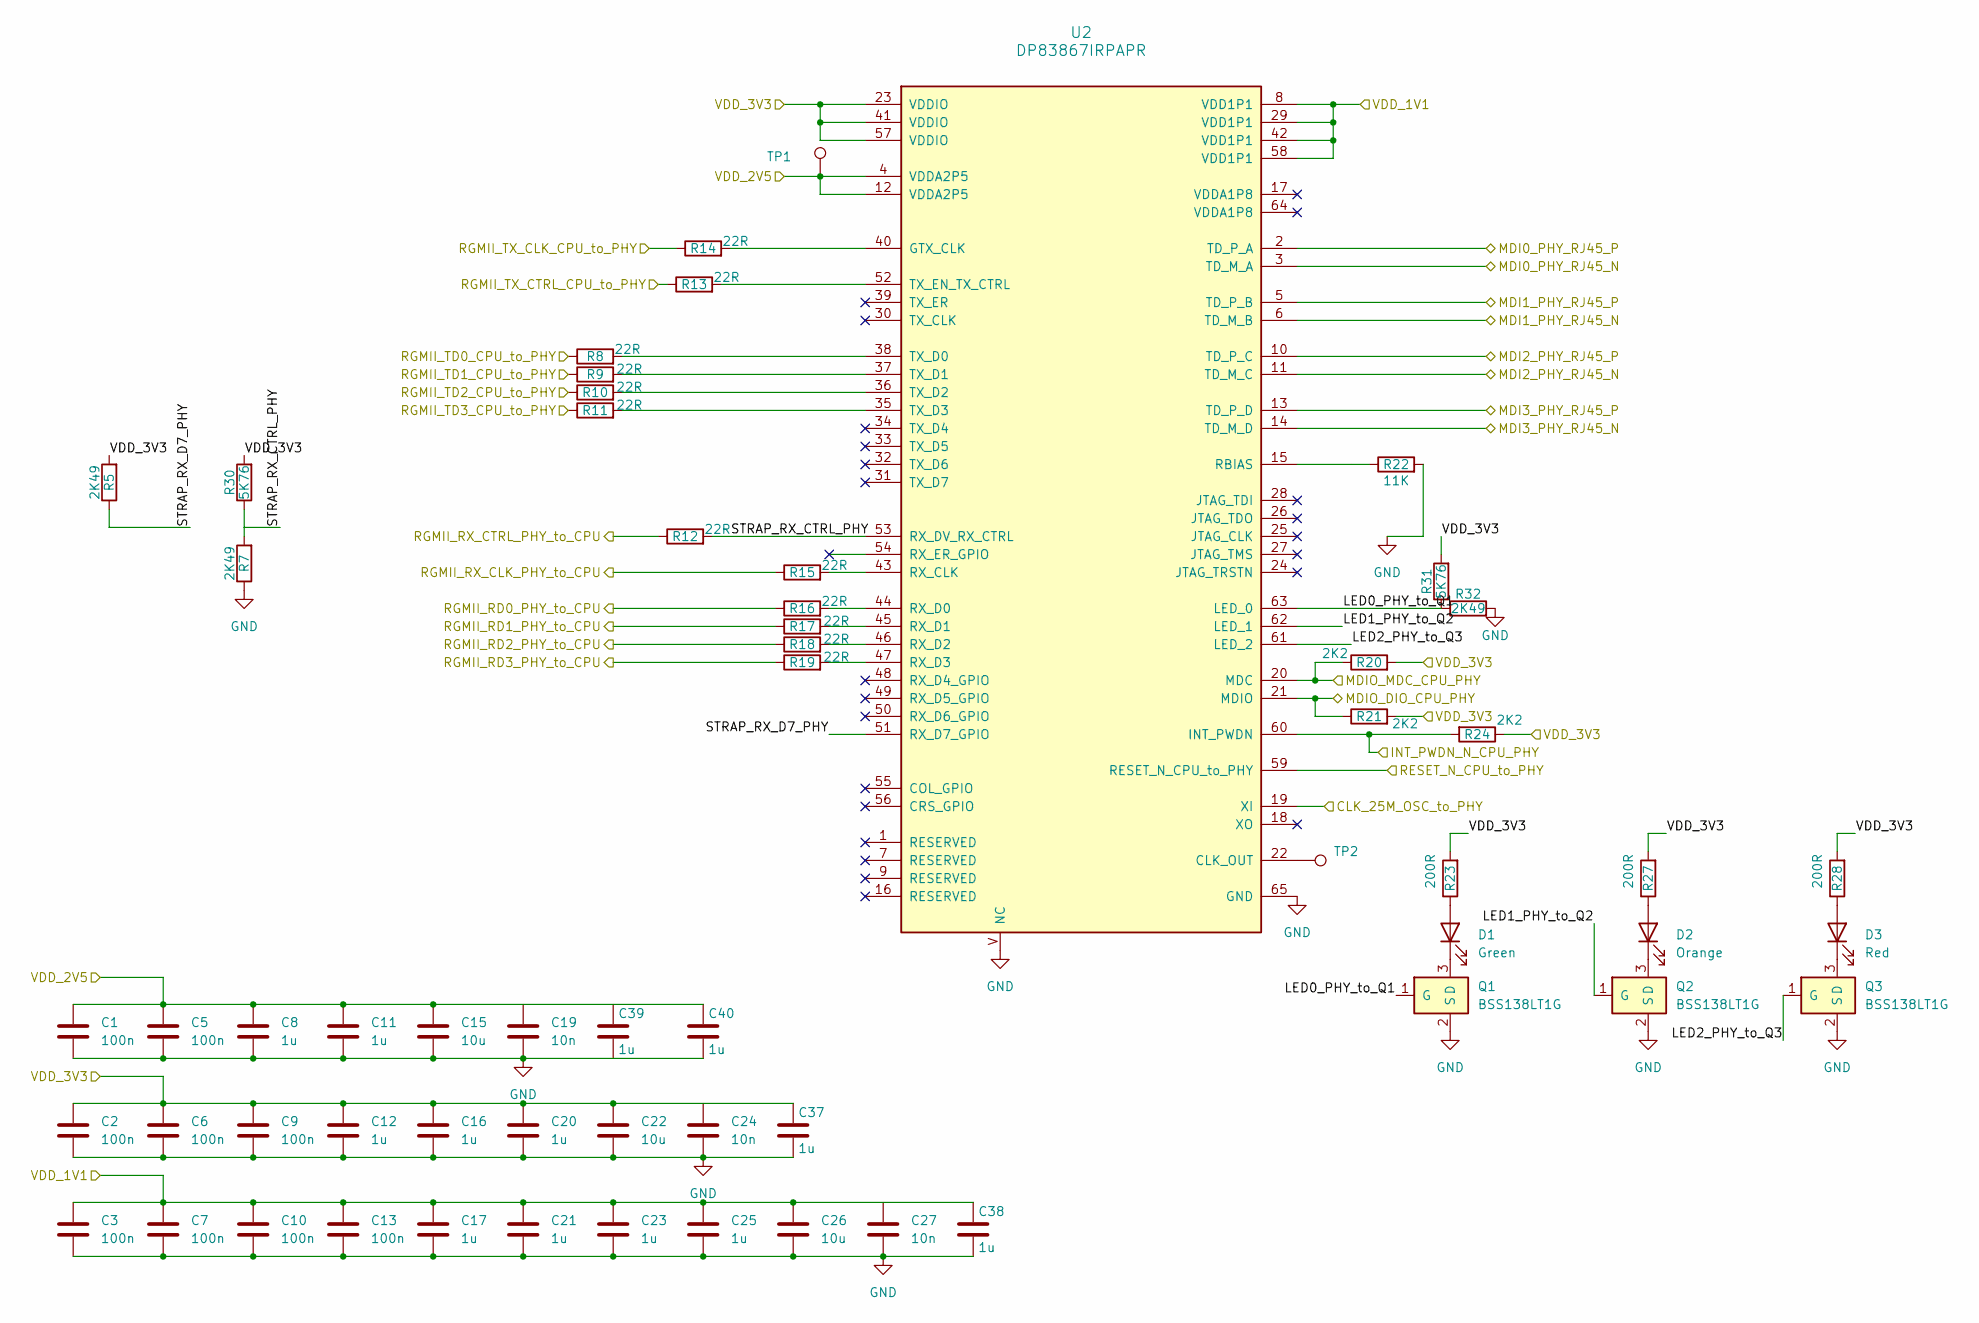
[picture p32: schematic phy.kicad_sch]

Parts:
C1, C2, C3, C5, C6, C7, C9, C10, C13: 100n; C_0402; Voltage_in_V 50; Tolerance_in_pct 10; MPN CL05B104KB54PNC; LCSC C307331
C8, C11, C12, C16, C17, C20, C21, C23, C25: 1u; C_0402; Voltage_in_V 16; Tolerance_in_pct 10; MPN GRM155R61C105KA12D; Mouser 81-GRM155R61C105KA12D
C15, C22, C26: 10u; C_0402; Voltage_in_V 6.3; Tolerance_in_pct 20; MPN GRM155R60J106ME44D; Mouser 81-GRM155R60J106ME44D
C19, C24, C27: 10n; C_0402; Voltage_in_V 50; Tolerance_in_pct 10; MPN GRM155R71H103KA88D; Mouser 81-GRM155R71H103KA88D
C37, C38, C39, C40: 1u; C_0402; Tolerance_in_pct 10; Voltage_in_V 16; MPN GRM155R61C105KA12D; Digikey 490-10694-1-ND
D1: Green; LED_0805; MPN LTST-C170GKT; Mouser 859-LTST-C170GKT
D2: Orange; LED_0805; MPN LTST-C170KFKT; Mouser 859-LTST-C170KFKT
D3: Red; LED_0805; MPN LTST-C170KRKT; Mouser 859-LTST-C170KRKT
Q1, Q2, Q3: BSS138LT1G; SOT-23; MPN BSS138LT1G; Mouser 863-BSS138LT1G
R5, R7: 2K49; R_0402; Tolerance_in_pct 1; MPN CRCW04022K49FKEDC; Mouser 71-CRCW04022K49FKEDC
R8, R9, R10, R11, R12, R13, R14, R15, R16, R17, R18, R19: 22R; R_0402; Tolerance_in_pct 1; MPN 0402WGF220JTCE; LCSC C25092
R20, R21, R24: 2K2; R_0402; Tolerance_in_pct 1; MPN CRCW04022K20FKEDC; Mouser 71-CRCW04022K20FKEDC
R22: 11K; R_0402; Tolerance_in_pct 1; MPN FRC0402F1102TS; LCSC C2909313
R23, R27, R28: 200R; R_0402; Tolerance_in_pct 1; MPN 0402WGF2000TCE; LCSC C25087
R30, R31: 5K76; R_0402; Tolerance_in_pct 1; MPN FRC0402F5761TS; LCSC C5153969
R32: 2K49; R_0402; Tolerance_in_pct 1; MPN CRCW04022K49FKEDC; Digikey 541-4867-1-ND
TP1, TP2: TestPoint_SMD; TestPoint_SMD_1.0x1.0mm
U2: DP83867IRPAPR; HTQFP-64_10x10mm_P0.5mm; MPN DP83867IRPAPR; Mouser 595-DP83867IRPAPR

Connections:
/INT_PWDN_N_CPU_PHY: R24.2, U2.60 (INT_PWDN); also elsewhere on the board
/MDIO_DIO_CPU_PHY: R21.1, U2.21 (MDIO); also elsewhere on the board
/MDIO_MDC_CPU_PHY: R20.1, U2.20 (MDC); also elsewhere on the board
/RESET_N_CPU_to_PHY: U2.59 (RESET_N_CPU_to_PHY); also elsewhere on the board
/RGMII_RD0_PHY_to_CPU: R16.1; also elsewhere on the board
/RGMII_RD1_PHY_to_CPU: R17.1; also elsewhere on the board
/RGMII_RD2_PHY_to_CPU: R18.1; also elsewhere on the board
/RGMII_RD3_PHY_to_CPU: R19.1; also elsewhere on the board
/RGMII_RX_CLK_PHY_to_CPU: R15.1; also elsewhere on the board
/RGMII_RX_CTRL_PHY_to_CPU: R12.1; also elsewhere on the board
/RGMII_TD0_CPU_to_PHY: R8.1; also elsewhere on the board
/RGMII_TD1_CPU_to_PHY: R9.1; also elsewhere on the board
/RGMII_TD2_CPU_to_PHY: R10.1; also elsewhere on the board
/RGMII_TD3_CPU_to_PHY: R11.1; also elsewhere on the board
/RGMII_TX_CLK_CPU_to_PHY: R14.1; also elsewhere on the board
/RGMII_TX_CTRL_CPU_to_PHY: R13.1; also elsewhere on the board
/VDD_1V1: C3.1, C7.1, C10.1, C13.1, C17.1, C21.1, C23.1, C25.1, C26.1, C27.1, C38.1, U2.8 (VDD1P1), U2.29 (VDD1P1), U2.42 (VDD1P1), U2.58 (VDD1P1); also elsewhere on the board
/VDD_2V5: C1.1, C5.1, C8.1, C11.1, C15.1, C19.1, C39.1, C40.1, TP1.1, U2.4 (VDDA2P5), U2.12 (VDDA2P5); also elsewhere on the board
/VDD_3V3: C2.1, C6.1, C9.1, C12.1, C16.1, C20.1, C22.1, C24.1, C37.1, R5.2, R20.2, R21.2, R23.2, R24.1, R27.2, R28.2, R30.2, R31.2, U2.23 (VDDIO), U2.41 (VDDIO), U2.57 (VDDIO); also elsewhere on the board
/network/oscillator/CLK_25M_OSC_to_PHY: U2.19 (XI); also elsewhere on the board
/network/phy/LED0_PHY_to_Q1: Q1.1 (G), R31.1, R32.1, U2.63 (LED_0)
/network/phy/LED1_PHY_to_Q2: Q2.1 (G), U2.62 (LED_1)
/network/phy/LED2_PHY_to_Q3: Q3.1 (G), U2.61 (LED_2)
/network/phy/MDI0_PHY_RJ45_N: U2.3 (TD_M_A); also elsewhere on the board
/network/phy/MDI0_PHY_RJ45_P: U2.2 (TD_P_A); also elsewhere on the board
/network/phy/MDI1_PHY_RJ45_N: U2.6 (TD_M_B); also elsewhere on the board
/network/phy/MDI1_PHY_RJ45_P: U2.5 (TD_P_B); also elsewhere on the board
/network/phy/MDI2_PHY_RJ45_N: U2.11 (TD_M_C); also elsewhere on the board
/network/phy/MDI2_PHY_RJ45_P: U2.10 (TD_P_C); also elsewhere on the board
/network/phy/MDI3_PHY_RJ45_N: U2.14 (TD_M_D); also elsewhere on the board
/network/phy/MDI3_PHY_RJ45_P: U2.13 (TD_P_D); also elsewhere on the board
/network/phy/STRAP_RX_CTRL_PHY: R7.2, R12.2, R30.1, U2.53 (RX_DV_RX_CTRL)
/network/phy/STRAP_RX_D7_PHY: R5.1, U2.51 (RX_D7_GPIO)
GND: C1.2, C2.2, C3.2, C5.2, C6.2, C7.2, C8.2, C9.2, C10.2, C11.2, C12.2, C13.2, C15.2, C16.2, C17.2, C19.2, C20.2, C21.2, C22.2, C23.2, C24.2, C25.2, C26.2, C27.2, C37.2, C38.2, C39.2, C40.2, Q1.2 (S), Q2.2 (S), Q3.2 (S), R7.1, R22.2, R32.2, U2.65 (GND), U2.V (NC); also elsewhere on the board
unnamed: D1.2 (A), R23.1
unnamed: D1.1 (K), Q1.3 (D)
unnamed: D2.2 (A), R27.1
unnamed: D2.1 (K), Q2.3 (D)
unnamed: D3.2 (A), R28.1
unnamed: D3.1 (K), Q3.3 (D)
unnamed: TP2.1, U2.22 (CLK_OUT)
unnamed: R14.2, U2.40 (GTX_CLK)
unnamed: R22.1, U2.15 (RBIAS)
unnamed: R15.2, U2.43 (RX_CLK)
unnamed: R16.2, U2.44 (RX_D0)
unnamed: R17.2, U2.45 (RX_D1)
unnamed: R18.2, U2.46 (RX_D2)
unnamed: R19.2, U2.47 (RX_D3)
unnamed: R8.2, U2.38 (TX_D0)
unnamed: R9.2, U2.37 (TX_D1)
unnamed: R10.2, U2.36 (TX_D2)
unnamed: R11.2, U2.35 (TX_D3)
unnamed: R13.2, U2.52 (TX_EN_TX_CTRL)

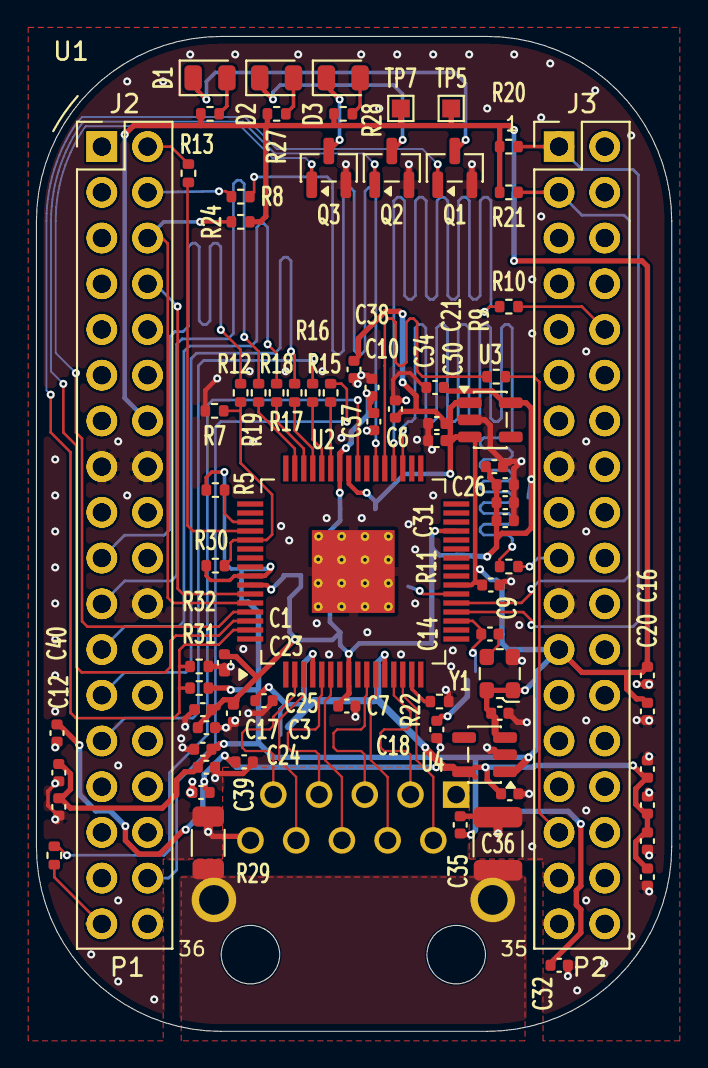
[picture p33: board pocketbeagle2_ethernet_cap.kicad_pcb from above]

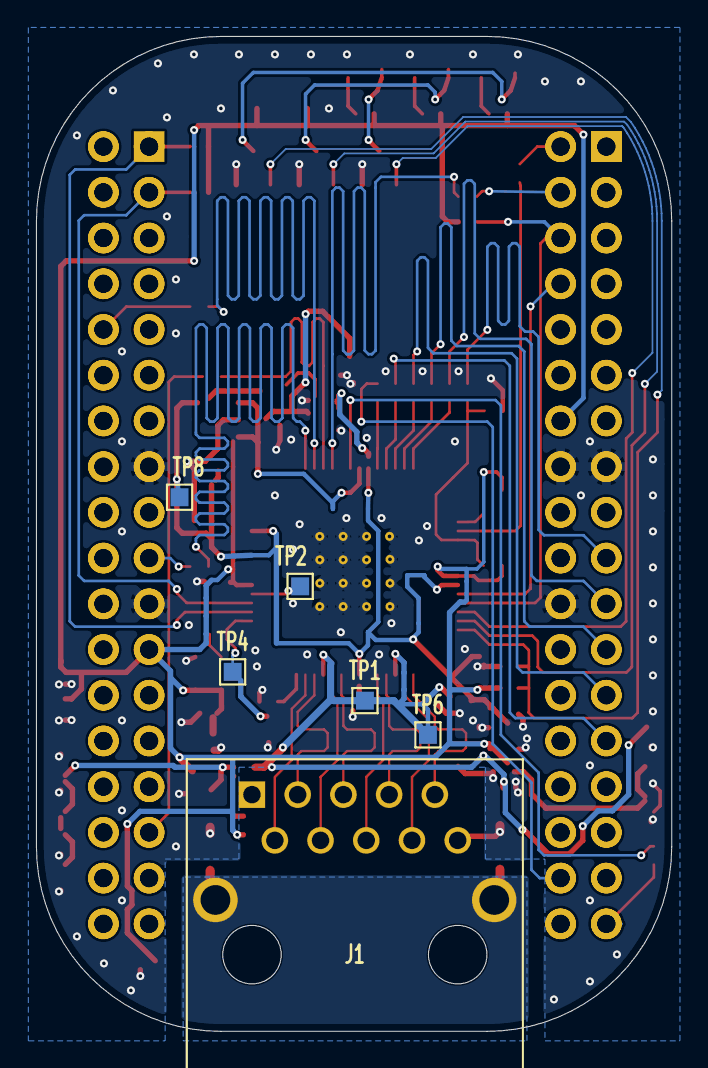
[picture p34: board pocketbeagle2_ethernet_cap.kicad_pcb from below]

Board: 4 copper layers, 35.3 x 55.3 mm, 84 parts (6 on the bottom side), 103 nets.

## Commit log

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2025-08-23 Preparing routing for RGMII and MDI interfaces
    [Power.kicad_sch, pocketbeagle2 revA_241205.kicad_pcb]
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2025-08-24 Fully routed PCB, missing fligth time matching on the RGMII
    [network.kicad_sch, pocketbeagle2 revA_241205.kicad_pcb, pocketbeagle2 revA_241205.kicad_sch]
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2026-07-07 Rename project files to pocketbeagle2_ethernet_cap
    [pocketbeagle2_ethernet_cap.kicad_pcb, pocketbeagle2_ethernet_cap.kicad_sch]
2026-07-07 Split Power into ldo_1v1 and ldo_2v5 sheets, rename audio sheet
    [Power.kicad_sch, audio.kicad_sch, ldo_1v1.kicad_sch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]
2026-07-07 Nest network into phy, rj45_connector_port0 and oscillator sheets
    [network.kicad_sch, oscillator.kicad_sch, phy.kicad_sch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]
2026-07-07 Migrate phy sheet to KL library symbols
    [phy.kicad_sch]
2026-07-07 Migrate oscillator sheet to KL library symbols
    [oscillator.kicad_sch]
2026-07-07 Migrate RJ45 port sheet to KL library symbols
    [rj45_connector_port0.kicad_sch]
2026-07-07 Migrate LDO sheets to KL library symbols
    [ldo_1v1.kicad_sch, ldo_2v5.kicad_sch]
2026-07-07 Migrate audio sheet to KL library symbols
    [audio.kicad_sch]
2026-07-07 Migrate root sheet to KL PocketBeagle2 module symbol
    [pocketbeagle2_ethernet_cap.kicad_sch]
2026-07-07 Apply signal naming convention to all nets
    [audio.kicad_sch, ldo_1v1.kicad_sch, ldo_2v5.kicad_sch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]
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2026-07-07 Fix remaining ERC issues: pin types, no connects, power flag, stub wires
    [audio.kicad_sch, phy.kicad_sch, pocketbeagle2_ethernet_cap.kicad_sch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]
2026-07-07 Replace audio PMOD sheet with full IO pass-through expansion headers
    [audio.kicad_sch, expansion.kicad_sch, pocketbeagle2_ethernet_cap.kicad_sch]
2026-07-07 Improve schematic readability across all sheets
    [expansion.kicad_sch, ldo_1v1.kicad_sch, ldo_2v5.kicad_sch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]
2026-07-07 Fix sheet pin text side and hide expansion header pin names
    [expansion.kicad_sch, network.kicad_sch, pocketbeagle2_ethernet_cap.kicad_sch]
2026-07-07 Convert to hierarchical port design, move PocketBeagle into io sheet
    [expansion.kicad_sch, io.kicad_sch, pocketbeagle2_ethernet_cap.kicad_sch]
2026-07-07 Clean up oscillator sheet: hide osc pin names, fix C4 and Y1 text placement
    [oscillator.kicad_sch]
2026-07-07 Fix io sheet: collapse 5 stacked GND symbols at U1 into one
    [io.kicad_sch]
2026-07-30 Migrate network sheet to KiCad 10 file format
    [network.kicad_sch]
2026-07-30 Migrate oscillator sheet to KiCad 10 file format
    [oscillator.kicad_sch]
2026-07-30 Migrate RJ45 port0 sheet to KiCad 10 file format
    [rj45_connector_port0.kicad_sch]
2026-07-30 Migrate root sheet to KiCad 10 file format
    [pocketbeagle2_ethernet_cap.kicad_sch]
2026-07-30 Move 1V1 LDO ground symbol; KiCad 10 format
    [ldo_1v1.kicad_sch]
2026-07-30 Move 2V5 LDO ground symbol; KiCad 10 format
    [ldo_2v5.kicad_sch]
2026-07-30 Connect LED1 and LED2 nets to Q2 Q3 gates
    [phy.kicad_sch]
2026-07-30 Rewire PocketBeagle ground pins and extend signal stubs
    [io.kicad_sch]
2026-07-30 Updating to KiCad 10 + updsate the library
    [io.kicad_sch, pocketbeagle2_ethernet_cap.kicad_pcb]
2026-09-25 Fix J2/J3 pass-through nets, AIN_VREF_N and U1 symbol
    [io.kicad_sch]
2026-09-25 Fix RX_CTRL and RX_D7 straps, oscillator load, RBIAS
    [oscillator.kicad_sch, phy.kicad_sch]
2026-09-25 Add chassis isolation, remove magjack centre-tap resistor
    [network.kicad_sch, rj45_connector_port0.kicad_sch]
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2026-09-25 Clear copper for re-spin, sync schematic, add P1/P2 silk
    [pocketbeagle2_ethernet_cap.kicad_pcb]
2026-09-25 Add rev B re-spin handover and helper scripts
    [board_before_respin.kicad_pcb]
2026-09-25 Route length-matched RGMII, MDI, LEDs and control nets
    [pocketbeagle2_ethernet_cap.kicad_pcb]
2026-09-25 Route power distribution, decoupling and strap resistors
    [pocketbeagle2_ethernet_cap.kicad_pcb]
2026-09-25 Route MDIO, clock, LEDs, chassis and second 3V3 feed
    [pocketbeagle2_ethernet_cap.kicad_pcb]
2026-09-25 Add 3D models, fix PB2 stack height, C34 stub
    [pocketbeagle2_ethernet_cap.kicad_pcb]
2026-09-25 Add 1uF decoupling on PHY pins 4, 12, 41, 42
    [phy.kicad_sch, pocketbeagle2_ethernet_cap.kicad_pcb]
2026-09-25 Mirror J1 MDI pins, add LED_0 mirror-mode strap
    [phy.kicad_sch, rj45_connector_port0.kicad_sch]
2026-09-25 Move J1 to bottom, rebuild MDI, U4 area, chassis planes
    [pocketbeagle2_ethernet_cap.kicad_pcb]
2026-09-25 Clear P1/P2 headers: move R13, R9, U3; re-route TD1
    [pocketbeagle2_ethernet_cap.kicad_pcb]
2026-09-25 Add GND/chassis pours on F/B and stitching via fence
    [pocketbeagle2_ethernet_cap.kicad_pcb]
2026-09-25 Silkscreen: JLC-size references without overlaps, PB2 model fix
    [pocketbeagle2_ethernet_cap.kicad_pcb]
2026-09-25 Switch BOM to in-stock LCSC parts, U3 to TLV73311
    [io.kicad_sch, ldo_1v1.kicad_sch, ldo_2v5.kicad_sch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]
2026-09-25 Move LED drivers, pull-ups, TD0/TD2 resistors to top side
    [pocketbeagle2_ethernet_cap.kicad_pcb]
2026-09-25 Move LDO, decoupling and series resistors to top side
    [pocketbeagle2_ethernet_cap.kicad_pcb]
2026-09-25 Silkscreen re-placed, 0402 3D models, orphan via removed
    [pocketbeagle2_ethernet_cap.kicad_pcb]
2026-09-25 Add JLCPCB Gerbers, LCSC BOM, CPL and generator scripts
    [pocketbeagle2_ethernet_cap-B_Cu.gbl, pocketbeagle2_ethernet_cap-B_Mask.gbs, pocketbeagle2_ethernet_cap-B_Paste.gbp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]
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2026-09-25 J1 3D model, narrow 1 mm silkscreen references
    [pocketbeagle2_ethernet_cap.kicad_pcb]
2026-09-25 Regenerate JLCPCB files, add assembly drawing
    [pocketbeagle2_ethernet_cap-B_Cu.gbl, pocketbeagle2_ethernet_cap-B_Mask.gbs, pocketbeagle2_ethernet_cap-B_Paste.gbp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]
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2026-09-25 Add build folder: fabrication, assembly and documentation outputs
    [pocketbeagle2_ethernet_cap-B_Cu.gbl, pocketbeagle2_ethernet_cap-B_Mask.gbs, pocketbeagle2_ethernet_cap-B_Paste.gbp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]
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2026-09-25 Bump library: J1 model to datasheet size, rebuild
    [pocketbeagle2_ethernet_cap-B_Cu.gbl, pocketbeagle2_ethernet_cap-B_Mask.gbs, pocketbeagle2_ethernet_cap-B_Paste.gbp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]
2026-09-25 CPL: place J2/J3 by part centre, not pin 1
    [pocketbeagle2_ethernet_cap-B_Cu.gbl, pocketbeagle2_ethernet_cap-B_Mask.gbs, pocketbeagle2_ethernet_cap-B_Paste.gbp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]
2026-09-25 CPL: rotate J2/J3 90 degrees for JLC header model
    [pocketbeagle2_ethernet_cap-B_Cu.gbl, pocketbeagle2_ethernet_cap-B_Mask.gbs, pocketbeagle2_ethernet_cap-B_Paste.gbp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]
2026-09-25 Move R29/C36 pads off J1 shield holes, refit caps
    [pocketbeagle2_ethernet_cap.kicad_pcb]
2026-09-25 CPL: JLC rotation fixes per package, rebuild outputs
    [pocketbeagle2_ethernet_cap-B_Cu.gbl, pocketbeagle2_ethernet_cap-B_Mask.gbs, pocketbeagle2_ethernet_cap-B_Paste.gbp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]
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
